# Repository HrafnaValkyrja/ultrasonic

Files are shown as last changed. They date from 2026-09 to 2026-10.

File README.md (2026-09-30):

# Stereo Ultrasound

A glasses-mounted wearable that shifts ultrasound (≈20–85 kHz) down into the audible range and plays it by bone conduction, in stereo, in real time.

- **Spec (source of truth):** [`docs/spec.md`](docs/spec.md). §1 is the owner-locked MVP.
- **Latest plan review:** [`docs/research/review-2026-09-30.md`](docs/research/review-2026-09-30.md)
- **Research findings:** [`docs/research/`](docs/research/), one file per task ID from spec §12.
- **Models and checks:** [`sim/checks/`](sim/checks/): PWM noise, noise-shaper comparison, dead-time distortion, weight balance. Run with `python3 <script>` (numpy, scipy).
- **Data:** [`sim/data/`](sim/data/): the mic's ultrasonic response, digitized from its datasheet.

Status: concept phase. Phase 1 (DSP simulation in Python) is next, pending owner decisions O1–O3 in spec §12.

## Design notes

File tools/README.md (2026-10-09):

# Engineering harness

Tools that let Claude simulate circuits, design and check boards, model mechanics, render
diagrams and cross-compile firmware in the cloud container. One idempotent installer,
one environment file, smoke tests with real answers.

```bash
tools/setup.sh               # install anything missing, verify (a fast no-op once installed)
tools/setup.sh --smoke       # ...then run the smoke tests
tools/setup.sh --check       # verify only
source tools/env.sh          # PATH, venv, KiCad library paths, FreeRouting, mermaid-cli
python3 tools/smoke/run_all.py [--offline] [-k NAME] [--keep DIR]
```
A SessionStart hook runs `tools/setup.sh --quiet` in Claude Code on the web, so a fresh
container installs everything automatically.

## What's installed (2026-09-30)
| Tool | Version | Used for | Skill |
|---|---|---|---|
| ngspice | 42 | Circuit simulation: H-bridge dead time, gate drive, LDO, battery | spice-sim |
| KiCad (`kicad-cli`, `pcbnew` Python) | 10.0.6 (official PPA, key pinned in `keys/`) | ERC/DRC, Gerber/drill/placement export, 3D renders, board scripting | pcb-kicad |
| SKiDL | 2.3.0 | Schematics as code, generating the KiCad netlist | pcb-kicad |
| FreeRouting | 2.4.1 (SHA-256 pinned; OpenJDK 25) | Headless autorouting via Specctra DSN/SES | pcb-kicad |
| easyeda2kicad | 1.0.1 | KiCad symbol, footprint and 3D model by LCSC number | jlc-parts |
| `tools/jlc.py` | — | JLC stock, price, Basic/Extended, with a query timestamp | jlc-parts |
| ARM GCC + newlib | 13.2.1 | Cortex-M4F cross-compiling (hard-float) | — |
| build123d | 0.13.0 | Parametric CAD, mass properties, STL/STEP | cad-mech |
| scikit-fem | 12.0.2 | Finite elements (spring arm force, stiffness) | cad-mech |
| sounddevice + libportaudio2 | 0.5.6 / 19.7 | Live audio I/O for `bench/rig/` scripts (licences: python-sounddevice MIT, PortAudio MIT-style) | bench |
| numpy / scipy / matplotlib | 2.5.3 / 1.18.1 / 3.11.2 | DSP models, plots (`tools/plotstyle.py`) | — |
| mermaid-cli | 11.17.0 (uses the preinstalled Chromium) | Flowcharts and mind maps to PNG | visual-explainer |
| headless Chromium | preinstalled (`/opt/pw-browsers`) | SVG diagrams to PNG (`docs/diagrams/render.sh`) | visual-explainer |

Python packages live in a Python 3.12 venv (`$ULTRA_VENV`, with system site packages so
`import pcbnew` works), pinned by `requirements.txt` and `constraints.txt`. Install location
is `/opt/ultrasonic-tools` (`$ULTRA_TOOLS_HOME`).

**Cost:** about 3.4 GB of disk (1.7 GB of apt packages, 1.7 GB of venv and tools). A run with
partly cached apt packages took 107 s. A fully cold install hasn't been timed; expect a few
minutes. The KiCad 3D-model library is optional: `--with-3d` adds 3.2 GB.

## Smoke tests (all passing, 2026-09-30)
| Test | Checks |
|---|---|
| ngspice | RC step response: time constant 1.000 ms (expected 1.000) |
| kicad+freerouting | Build a 2-net board → autoroute → import → DRC 0 errors, 0 unconnected → 25 Gerber files → 3D render |
| skidl | Netlist with parts, nets and footprints |
| arm-gcc | Cortex-M4F object uses the FPU |
| build123d | Exact volume and centroid of a part with a window; STL + STEP |
| scikit-fem | Cantilever tip deflection matches beam theory to 0.1% |
| sounddevice + libportaudio2 | 0.5.6 / 19.7 | Live audio I/O for `bench/rig/` scripts (licences: python-sounddevice MIT, PortAudio MIT-style) | bench |
| render | SVG and Mermaid diagrams to PNG |
| easyeda2kicad | Fetches the SPH0641LU4H-1 footprint and symbol (C2879853) — network |
| jlc-api | Live JLC lookup — network |

## Fixed while testing
`tools/spice.py` returned no `.meas` results: ngspice 42 refuses `.meas` in batch mode
when writing a rawfile. Netlists with `.meas` now get a second batch pass without `-r`.

## What this can't do
- **Cycle-accurate Cortex-M4 timing.** There's no free simulator for it; measure on the Nucleo
  with the DWT cycle counter (spec S3).
- **Bone conduction, skin coupling and perception.** These are bench and ear questions (spec §10).
- **The mic's acoustic port above ~20 kHz.** Lumped models are approximate; the S1 acoustic
  coupons decide.
- **EMI and full-wave electromagnetics.** Not installed (openEMS could be added if needed).
- **Accuracy of vendor models.** A simulation is only as good as its models; every result
  names the models it used.

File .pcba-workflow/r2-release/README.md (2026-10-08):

# r2 (phase-2 'mz2') release package - 2026-10-08 - gate BLOCKED (see gate.yaml)
Mirrors .pcba-workflow/k4-release. Files: `r2_gerber_drill.zip` (Protel-ext Gerbers F/In1/In2/B Cu, masks, paste, silk, Edge.Cuts; Excellon PTH+NPTH; maps; job), `bom.csv`, `cpl.csv` (JLC rotations via tools/jlc_rotations.py; bottom rule jlc2022), `jlc_rotation_corrections.csv`, `pin1_expected.png`, `pin1_check.csv`, `sourcing_dated.csv` (live JLC API), `cost_inputs.json`, `src/bom_jlc_mz2.csv`.
Rebuild: `python3 .pcba-workflow/k4-release/build_release.py r2` (default arg = K4). Gerbers: `kicad-cli pcb export gerbers --board-plot-params --no-x2` + `export drill --excellon-separate-th --generate-map --map-format gerberx2` on the board, zipped.
Quantity assumed 5 boards (JLC min). Nothing ordered.

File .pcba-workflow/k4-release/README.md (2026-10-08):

# K4 release package (P + M boards) - 2026-10-08 - gate BLOCKED (see gate.yaml); rebuilt on 311b11d (board hashes in gate.yaml)

Files (per board X in P, M): `k4_X_gerber_drill.zip` (Protel-ext Gerbers F/In1-4/B Cu, masks, paste, silk, Edge.Cuts; Excellon PTH+NPTH; drill maps; job file),
`bom_X.csv` (JLC columns Comment/Designator/Footprint/LCSC Part #), `cpl_X.csv` (Designator, Mid X, Mid Y, Layer, Rotation; absolute KiCad coordinates, y up, mm),
`pin1_check.csv`, `sourcing_dated.csv` (live JLC API per line), `build_release.py`, `src/` (BOMs matching the boards).

Board: 15.5 x 12.0 mm (bbox 15.55 x 12.05 with edge line), 6 copper layers, 0.8 mm, ENIG (BM28 0.35 mm pitch, QFN/DSBGA need flat pads), min track/space 0.09/0.088 mm (persisted JLC fine rules in .kicad_pro), parts both sides (top, from cpl_X.csv. P top: C2 C9 C11 C22 J21 Q1 R2 R3 R4 R6 R21 R22 R23; P bottom: the rest incl. U1 QFN48, Y1, L1, Q2. M top: C16 C17 C19 D4 D5 J20 R8 R9 R12 R13 R14 U2 U3 U4; M bottom: the rest incl. SW1, U6, RT1).

## Quantities (owner rule: 2 worn + 3 spares, O19)
JLC PCBA minimum is 5. Order 5 P + 5 M assembled; every BOM line = qty/board x 5. Spares are whole boards, so a P/M pair is always available.
MCU C5271013 stock was 19 on 2026-10-08 (08:40Z) (5 needed): reserve early.

## Stack-up / impedance
No `(stackup)` block in the board files; JLC publishes 6L builds for 1.2/1.6/2.0 mm only, NOT 0.8 mm (read 2026-10-08, K4-STACK6). Order 6L 0.8 mm with JLC's default build, **no impedance control**: nothing here claims a controlled net (USB D+/D- are full speed, ~15 mm). Planes: In1 GND, In2/In3/In4 per router assignment; sim/noise assumed uniform dielectrics (0.2 dB spread to thin-outer). Copper outer 1 oz-class (35 um nominal on JLC 6L), inner 0.5 oz (15 um).

## Vias / via-in-pad
All vias 0.15 mm drill / 0.25 mm pad, through (F-B) only: P 107, M 70 (pcbnew count). That is JLC's minimum (0.15/0.25) and carries a small-via surcharge. **Via-in-pad: 67 vias land on SMD pads on P (U1 QFN48 exposed pad, R3, R5); none on M.** Order flag: **"Via-in-pad / plugged: Epoxy/copper filled and capped (POFV)"**, which JLC covers for 0.15-0.55 mm vias (capabilities page Sep 2026). Ink-plugged is NOT allowed in pads. Without POFV, solder wicks into the QFN EP vias. Drill histogram: P PTH 0.15 x107; M PTH 0.15 x70, NPTH 0.65 x1 (mic port).

## CPL rotation corrections (tools/jlc_rotations.py, 2026-10-08; replaces the raw-KiCad CPL)
`cpl_X.csv` now carries JLC rotations: top = KiCad rot + corr; bottom = (180 - (rot - corr)) mod 360 (JLCKicadTools rule, comment dated 2022-07; JLC changed it before, so the preview still decides; `--bottom-rule asis` = old raw behaviour). corr comes from (1) pin-1 geometry of our footprint vs the EasyEDA footprint of the LCSC part (easyeda2kicad, cached `tools/data/jlc_rot/ee/`), (2) the community DB `tools/data/jlc_rot/cpl_rotations_db.csv` (matthewlai/JLCKicadTools, GPL-3.0, last commit 2024-09-11, fetched 2026-10-08; same file kicad-jlcpcb-tools downloads) which wins when a rule matches. Table: `jlc_rotation_corrections.csv` (board, ref, footprint, LCSC, kicad rot, jlc rot, corr, offset, source, confidence, check flag, notes). Regenerate: `python3 tools/jlc_rotations.py --release` (build_release.py calls it).
Result: only U1 (corr 270) differs among ICs; bottom-side rule changes C13, R10 etc. (180 -> 0, harmless for passives). 43 of 55 parts are symmetric passives (high); **12 parts are NOT confirmable from data and go on the preview checklist, `pin1_expected.png` shows the expected pad-1 corner for each**: J21, J20 (BM28), Q1, Q2 (SOT1216, no EasyEDA footprint exists for C19654206, so no data check at all), U1 (QFN48, pad sets differ 0.23 mm from EasyEDA), U2 (LGA mic), U3 (DSBGA), U4 (X2SON), U6 (SOT-553), D4, SW1. (D5 X1SON is symmetric-ish, checked in the same pass.) JLC's private per-part rotation offsets are not published; that residual is what the preview is for.
Do not accept the preview with any part highlighted red; stop and re-export. Any part rotated wrong in preview: add its correction to a local override and rerun.

## Panel / rails (15.5 x 12 boards)
JLC assembly needs rails + tooling; boards this small cannot run alone. Options:
A. **(recommended) 1 P + 1 M per panel, 5 panels** = exactly 5 + 5 boards (2 worn + 3 spares); Different Design = 2, panel by customer. Side by side with 2 mm gap and mouse bites: 33 x 12; 5 mm rails on the long sides: 33 x 22; 2 mm tooling holes + 1 mm fiducials in the rails. If JLC enforces the 70 x 70 minimum seen in assembly.md, widen the rails (free FR4, same price).
B. 5 P + 5 M in one 2-row panel: fewer panels, but a single bad row blocks both; JLC min PCB qty may force 5 such panels.
C. Order loose and "Panel by JLCPCB" V-cut: not recommended (mouse-bite/V-cut leaves 0.4 mm tolerance against 0.35 mm-pitch connector edge placement and offers no fiducials).
No panel file made (needs the final board hashes).

## Cost estimate, 5 + 5 assembled (2026-10-08, JLC parts API 11:53Z; fees from JLC page read 2026-10-02: assembly.md)
| Line | USD | Basis |
|---|---|---|
| Parts (40 lines, 35 distinct LCSC, 5x each) | 78.40 | live API price at qty, `sourcing_dated.csv`; MCU alone 5 x 9.02 = 45.1 |
| Feeder loading $1.53 per part type | 54 (61 if per board line) | 35 distinct (29 Extended) |
| Setup + stencil, double-sided | 68 to 135 | $51.12 + $16.42 once for one combined order; double if P and M ordered separately |
| X-ray (QFN48, DSBGA, LGA, X2SON, DFN, X1SON) | 25 to 70 | scaled from $10-28 per 4 boards; unquoted |
| PCB 6L 0.8 ENIG, 0.15 vias, POFV, 5 panels | 60 to 160 | UNQUOTED: JLC headline "6L 5 pcs from $2" excludes ENIG, POFV, small-via fee |
| Shipping, tax | not included | |
| **Total** | **about 287 to 503** | mid ~395; over the ~$300 budget line (O13) unless the low end holds |
Live quote is required before relying on any of this. Hand-off to the upload checklist: `operate-jlcpcb-order` (not started).

## ECR-0023 filler
Bonded-post filler: low-shrink epoxy, <= 0.5 % shrink (shell assembly, not a PCB line item).

**K4-STACK6 (2026-10-08):** stack-up we order = JLC 6L 0.8 mm default build, symmetric split assumed (sources: jlcpcb.com/resources/6-layer-pcbs, jlcpcb.com/impedance, read 2026-10-08). sim/noise/k4_noise.py re-run with both bounding splits: worst-PSRR corner 26.4 dB (uniform) / 26.2 dB (thin_outer), spread 0.2 dB, sign-off >= 10 PASS.

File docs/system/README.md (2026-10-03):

# The big picture: living system documents

The pod is one system. A change in one place (a part swap, a moved component, a lid feature, a firmware
pin) can break something three domains away. These documents keep the whole picture in one place, so
every change is checked against it **before** it is made. Owner rule, 2026-10-01: Claude and every
agent use this set for every design change.

## The rule

1. **Before** any design change (schematic, layout, mechanics, firmware architecture, part choice):
   read `00-whole.md`, `integration-map.md`, and the doc of every subsystem and region the change touches.
   Walk the change through the cross-check in `integration-map.md` §10 (functions, nets, pins, rails,
   off-board, mechanical, firmware, cross-domain dependencies). Run `python3 tools/plm.py impact <file|ref:X|net:X|item>`
   to list every interface and doc the change touches. A change bigger than a typo gets an ECR
   (`plm.py ecr new`); the owner approves ECRs that touch her decisions.
2. **After** the change, in the same commit: update every doc it touched, in the AI-facing format (owner
   rule 2026-10-01: the docs are written for other Claude instances with a compacted context, not for humans):
   - **content:** current state only (history = git, no change-log section; one `Rev <letter> <date>:` line at
     the top says what the latest revision changed); the YAML status header, interfaces, key numbers and open
     issues all updated;
   - **form:** YAML blocks and terse key:value lines; stable IDs (D#, O#, R#, F#, ECR-####, relation ids, check
     ids; a closed issue leaves a gap in its ID sequence, never a renumbering); a source (file:symbol | spec § |
     commit) and a date on every number; pointers instead of copies; invariants as executable checks
     (`tools/checks/*`) that the doc lists by id; at most one `why:` line, only when non-obvious; every
     abbreviation defined once at the top.

   Regenerate the integration map when the schematic changes:
   `source tools/env.sh && python3 hw/pod/system_map.py`. Then `plm.py status`: every SUSPECT relation and
   STALE item it reports must be checked and re-baselined (`plm.py review <id> --by ... --note ...`) before
   the work counts as done.
3. **Agents** get this set as mandatory context and must return the cross-check with every proposal.
   A team (agent or person) that edits an item checks it out first (`plm.py checkout <item> --by <team>`);
   a CONFLICT FLAG means a related item is held by another team: coordinate before editing.
4. **Authority:** `docs/spec.md` wins. These docs summarise and link; they never override the spec or the
   source-of-truth files (`hw/pod/gen.py`, the KiCad board, `hw/mech/*.py`). If a doc disagrees with a
   source file, the doc is wrong: fix it. If the spec looks wrong, raise it with the owner.
5. **Staleness is a bug.** A doc whose status line is older than the last change to its source files is
   out of date. Fix it before relying on it.

## Index

| Doc | Kind | Covers |
|---|---|---|
| [00-whole.md](00-whole.md) | whole | The product on one page: functions, block and physical diagrams, key numbers, status of every part of the system, decision index |
| [integration-map.md](integration-map.md) | integration (generated) | Every block, inter-block net, MCU pin, rail load, off-board wire, mechanical keep-out, firmware dependency; the cross-check protocol |
| [physical.md](physical.md) | physical integration | Coordinate frame, stack-up through the pod, clearances, sealing paths, assembly order (test build vs final bonded build) |
| [sub-power.md](sub-power.md) | subsystem | Cell, charger, power path, LDO, rails, temperature-safe charging, battery sensing, power budget |
| [sub-audio-in.md](sub-audio-in.md) | subsystem | Ultrasonic mic, acoustic port path, PDM/ADF1 capture |
| [sub-processing.md](sub-processing.md) | subsystem | MCU, core SMPS, clocks, memory, firmware architecture and algorithms, low-power modes |
| [sub-output.md](sub-output.md) | subsystem | H-bridge, PWM, exciter, arm wiring to it, self-test current sense |
| [sub-dock-usb.md](sub-dock-usb.md) | subsystem | Magnetic dock, USB FS, DFU, ESD, dock detect |
| [sub-ui.md](sub-ui.md) | subsystem | Button (switch, plunger, skin), power LED |
| [sub-debug-test.md](sub-debug-test.md) | subsystem | SWD, test pads, test hooks, snap-off test frame, self-test over USB, bring-up plan |
| [reg-pod-body.md](reg-pod-body.md) | region | Housing (tub, lid, spine top), board retention, dock bay, sealing, adapter to the temple |
| [reg-board.md](reg-board.md) | region | The PCB: outline, faces, floorplan regions, layer stack, keep-outs, height bands, routing state |
| [reg-arm.md](reg-arm.md) | region | NiTi arm, heel, strut cover, joint, wire path through it |
| [reg-pad.md](reg-pad.md) | region | Transducer cup, contact face, pad board and LED |

## Relation tracking (`tools/plm.py`, PLM-style)

Items (these docs), relations (the interfaces between them, each watching the exact things that carry the
interface: nets, parts, placement entries, CAD symbols, spec lines), baselines, check-outs and ECRs live in
`docs/system/plm/`. A relation turns **SUSPECT** when anything it watches changes after its last review; an
item turns **STALE** when its sources change after its doc was last reviewed; a watch that no longer resolves
is **BROKEN** (re-model the relation). `plm.py graph` draws the whole web (`docs/diagrams/plm-relations.png`).
Idea sources: Teamcenter-style where-used / change management; Doorstop's suspect-link stamps.

## Template (every subsystem and region doc)

Format of the six Rev F docs (`sub-power`, `sub-processing`, `sub-output`, `sub-dock-usb`, `sub-debug-test`,
`reg-board`); rule 2 above defines the style.

````
# <NAME>: <scope> (item <ITEM-ID>)
Rev <letter> <date>: <one line: what this revision changed; current state only, history = git>
Status: <schematic / board / firmware state, each with source + date>. Updated <date>.

```yaml
abbrev: {TERM: meaning}          # every abbreviation, defined once, before use
item: <ITEM-ID>                  # docs/system/plm/items.yaml
src_of_truth: ["<file[:symbol or Lnn]>", "<...>"]
owner_decisions: ["O#", "<...>"]
open_ecrs: {ECR-####: <state>}
checks: ["tools/checks/<x>.py [<check id>] (<date>: <result>)"]
diagrams: ["docs/diagrams/<name>.png"]
```

## Purpose            YAML: functions (F-rows in integration-map.md §1), requirements, each with its D-/O-id
## Big picture        a diagram (PNG in docs/diagrams, dark mode, or mermaid) + at most ~10 key:value lines
## Elements           YAML list: ref, part (glossed: part number = what it is), lcsc · class · stock · price (query date), position (src)
## Interfaces         YAML list, one entry per neighbour: to, nets/pins (names exactly as in integration-map.md),
                      crosses, invariants, src, rel (plm relation id)
## Constraints        YAML: D-items, O-items, physics/process limits, each with src
## Key numbers        YAML list: {q: quantity, v: value, src: source + date}; derived values say "derived"
## Open issues        YAML list with stable IDs (<PREFIX>-<n>, gaps = closed): id, t (what), close (what would
                      close it), owner (who decides)
## Before you change this, check   YAML: invariant -> other docs/checks it can break; always: plm.py impact + integration-map §10
````

## Change log
- 2026-10-01: set created (owner rule). `integration-map.md` generated from gen.py Rev E.
- 2026-10-01: doc set completed (00-whole, physical, 7 subsystem and 4 region docs, diagrams `system-overview-physical` and `board-regions`), then inspected and corrected in one editor pass: interfaces name the doc on the other side, 00-whole gains the status table, "Design-level cross-domain risks" and "Fixes waiting in source files"; ECR-0008/0009 and two relations in `items.yaml` amended.

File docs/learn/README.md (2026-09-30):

# Learning the device

**Level-set (owner, 2026-09-30):** RF, analogue, digital packets/data, CAD and device physics are all known ground. The gaps are the black boxes: what's inside a modern MCU, how to read one, and why a 4-layer board. Lessons are pitched there.

- `02-inside-the-chip.png`: the STM32U575 as a small network (bus masters, DMA, memory-mapped peripherals, clock tree), with one audio sample's path
- `03-four-layer-board.png`: the pod board's stack-up, vias, return paths, and why 4 layers

## Original plan (lesson 1 pitched too low; kept for reference)

Each lesson has one picture and one idea. Every later lesson builds on lesson 1.

1. **The big picture:** the journey of one bat chirp; the "two pianos" idea (`01-big-picture.png`)
2. **Hearing ultrasound:** how a 3.5 mm mic hears 40 kHz, and why it speaks in 1-bit pulses
3. **Counting:** turning pulses into numbers; why 200,000 numbers a second is enough for 85 kHz
4. **Sorting and re-singing:** splitting sound into 28 "keys" (the FFT), the log squeeze, and why whines vanish
5. **Switching:** making sound from on/off pulses (PWM), the H-bridge, and dead time
6. **Bone conduction:** why the tragus, and how vibration reaches the cochlea
7. **Power:** battery, regulators, and why current decides runtime; the idle mode
8. **The board:** every part on the render, matched to the blocks above
9. **Mechanics:** the pod, the NiTi arm, and balance on your nose and ears

Each lesson ends with a hands-on "try it" for when the parts arrive.

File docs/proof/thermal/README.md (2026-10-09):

# P-THERM: is the K4 pod thermally possible? (2026-10-08)
Method: lumped transient network (`thermal.py`, numbers reproducible, 3G fence): U3 die - board - shell - 35 °C ambient, cell coupled to board (1.4 mm air gap, 113 K/W) and shell (13.9 K/W). Envelope from `hw/mech/dims_k4.py` (A_out 23.5 cm²). No 2-D FEM: the unknowns are the film coefficient and gaps, not conduction detail. Plot: `thermal.png` (dark).

## Heat sources (130 mA charge, 5 V dock, D4 drop 0.30 V -> VIN 4.7 V)
| part | dissipation | basis |
|---|---|---|
| U3 BQ25180 (TI 1-cell linear charger) | 0.19 W at VBAT 3.3 V, 0.12 W at 3.8 V, 0.07 W at 4.2 V | (VIN-VBAT) x (130+5 mA), TI SLUSE99C §8.3.7.7 formula |
| D4 PMEG3005EL (Nexperia 30 V Schottky) | 0.04 W | 0.30 V x 0.135 A |
| cell + PCM (protection circuit) | 5 mW | I²R, 0.3 Ω ASSUMED (no datasheet ESR in repo) |
| awake, worst (MCU 5.8 + audio 2.15 + bridge ctrl 1.06 + transducer avg 2.5 = 11.5 mA, VSYS 4.2 V) | 48 mW (LDO U4 14 mW) | `docs/system/rail-budget.yaml` |

## Results
| # | check | result | verdict |
|---|---|---|---|
| 1 | U3 junction, charging, 35 °C docked | 52 °C (board 47 + P x RθJB 30.3); bounds with θJA 65/107 °C/W on 0.2 W: 48-56 °C. Limit: THERM_REG 100 °C | PASS (48 K margin) |
| 2 | D4 junction | ~71 °C (existing figure, 500 K/W) | PASS |
| 3 | Cell temp, charging, **docked, still air** (h 10 W/m²K) | peak 43.5 °C at 21 min, limit 45 °C (0-45 °C charge, `sub-power.md` L134) | PASS, margin only 1.5 K |
| 4 | Cell temp, charging, **worn / covered** (h 5, bound) | peak 49.4 °C | FAIL as a bound; mitigated by U3 JEITA (TS 45 °C stop) via RT1 (reads board, hotter than the cell, so conservative) -> charge pauses, never overheats the cell. Charging worn is not a stated use |
| 5 | Skin touch, charging docked | shell 42.9 °C vs 43 °C | PASS, zero margin |
| 6 | Skin touch, charging worn bound | shell 48.9 °C | FAIL vs 43 °C; do not charge on the head |
| 7 | Awake runtime, worst | 48 mW: shell +2.1 K (docked-like) to +4.1 K (bound) -> ~39 °C at 35 °C ambient; U4 +2.3 K | PASS |
| 8 | LDO U4 under transducer drive, fw clamp 208 mA (FWSIM-R64), VSYS 4.2-4.5 V docked (drop 1.2-1.5 V) | Playback is real-time audio, not scheduled bursts (spec §5: heterodyne/compression; bat calls last ms, spec L291). Duty is signal-driven, so bounded three ways. (a) Continuous full-clamp sine (impossible bound): mean |i| = 0.637 x 208 = 132 mA -> 0.16 W (4.2 V) to 0.20 W (4.5 V) -> +26 to +33 K at θJA 166 °C/W (steady). (b) Budgeted worst average, rail-budget exciter 2.5 mA: 3.8 mW at 4.5 V -> +0.6 K (equals 1.9 % of (a)). (b2) D17 option A + 12 dB drive into the limiter, real programme (docs/proof/electrical/d17-cost.md, 2026-10-08): mean 14.5 mA (dense) to 24.9 mA (calls continuous) -> 17-37 mW -> +2.9 to +6.2 K (TEAX 7.8 ohm: +3.0 to +6.3 K); option A alone +1.0 to +2.2 K; U4 junction ~45 °C worst, PASS. (c) One call, 10 ms at the clamp (0.2 W mean): ΔT = P θ (1-e^(-t/τ)); no Zth curve exists in TPS7A20 datasheet SBVS338H (rev. Jul 2024, fetched 2026-10-08; only θJA 166.1, RθJC(top) 103.6, ψJT 3.0, ψJB 103.3 °C/W for DQN), so NO thermal-capacity credit is taken: the pulse is charged at steady θJA, +33 K (supersedes the assumed τ 0.1-1 s, +0.3 to +3 K). Even a 200 calls/s buzz at 10 ms is case (a). U4 junction then ~35 + 3 (shell) + 33 = 71 °C worst, far under its 125 °C | PASS (realistic +0.6 K; bound +33 K); datasheet θJA/ψJT confirmed; Zth not published (bound used); shell/ambient terms still ASSUMED, bench log of U4 (PWR-I12) closes them |

**Row 8 re-run 2026-10-08 (SIM-FID-U4; datasheet SBVS338H, θJA 166.1, ψJT 3.0 so case top is within 0.2 K of the die).** Heat into the shell = all extra battery power (4.2 V x extra mA; acoustic output negligible) at row 7's 44 K/W (docked-like) to 85 K/W (bound); U4 = (VSYS-3.0) 1.2-1.5 V x I x 166. Ambient 35 °C.

| Case (exciter mean mA; source) | Pod P | Shell | U4 junction | Touch margin vs 48 °C (TS1) |
|---|---|---|---|---|
| Today, rail budget 2.5 | 48 mW | 37.1-39.1 | ~39-41 | 8.9-10.9 K |
| A+loud12, real use bats (8.9 awake hops; current-models-reconciled.md) | ~75 mW | 38.3-41.4 | 41.9-45.0 | 6.6-9.7 K |
| A+loud12 dense programme (14.5; d17-cost.md) | ~98 mW | 39.3-43.3 | ~44-49 | 4.7-8.7 K |
| A+loud12 nonstop loud, calls continuous (24.9) | ~142 mW | 41.2-47.1 | 48-55.5 | **0.9-6.8 K** |

All junctions far under 125 °C (even +33 K pulse on top: <90 °C). Shell touch is the limiter: nonstop loud playback in the bound (worn, no airflow) case is 0.9 K from TS1 48 °C, thin but passing; docked-like 6.8 K. Note row 5/6 charging limits (43 °C skin) are separate and do not combine with playback (docked, not worn). Still ASSUMED: ambient 35 °C, R_shell 44-85 K/W (row 7), VSYS 4.2-4.5 V, mean mA from sim not firmware.
| 9 | Cell ESR, h, R_BS | assumed, not measured | OPEN: log board+cell temperature through a full charge (PWR-I12 / ECR-0009 item 3) |

## Limits (sources; touch text re-fetched 2026-10-08)
- Cell charge 0-45 °C: Renata ICP401230 V02 08/2019 (as in `sub-power.md`).
- Touch: IEC 62368-1 (TS1 table, Table 42 in ed. 2.0 2010; Table 38 in later editions): TS1 max 48 °C, metal and plastic, contact > 1 min; 51 °C metal / 60 °C plastic for 10-60 s; TS2 = TS1 + 10 K. Source: UL Japan tech brief 'Touch Temperature' (Copyright 2010 UL), https://japan.ul.com/wp-content/uploads/sites/27/2014/06/1_techbrief_touchtemp.pdf, fetched 2026-10-08 (secondary source; the standard text itself is paywalled). The earlier '~43 °C' is NOT the 62368-1 number: it is the IEC 60601-1 applied-part limit (recall, still unconfirmed). Project line stays 43 °C (conservative, worn on skin ~33-35 °C): rows 5/6 verdicts unchanged; against 62368-1 TS1 48 °C, row 5 has 5 K margin and row 6 (48.9 °C) is a marginal FAIL.
- U3 numbers: TI BQ25180 SLUSE99C §7.3, §8.3.7.7 (via `docs/system/audit-datasheet-claims.md` row 7, 2026-10-02).

## Verdict
Possible with thin margin: docked charge keeps the cell under 45 °C by 1.5 K and the shell at the 43 °C line. The one real lever is current: capping charge at 65 mA (0.5C, already an open owner question A-SAFETY-REVIEW) halves U3 heat and gives ~20 K margin. Recommend: ship firmware default 0.5C, 130 mA only below ~30 °C ambient (RT1 reads).

**Lead note 2026-10-08:** the owner ruled 130 mA (1C) in O34, so 1C stays the default. The hot case is already covered in hardware: U3 TS_HOT is set to 45 °C (sub-power.md register plan), so above that charging pauses and resumes once the cell cools; it never overheats. A 0.5C fallback above ~30 °C ambient (RT1) is a firmware option to raise only if the bench first charge (G5, thermocouple) shows pauses. Row 8 (LDO duty) and the touch-limit re-fetch closed 2026-10-08 (see table and limits).

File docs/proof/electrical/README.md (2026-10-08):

# K4 electrical proof (P + M boards), 2026-10-08

Question: are `hw/pod/k4/routed_{P,M}.kicad_pcb` (generator `hw/pod/k4/gen.py`, BOMs `bom_jlc_{P,M}.csv`) electrically possible?
Answer: **boards are connected and rule-clean; the +3V0 peak is not.** Two FAILs, one root cause: the bridge full-drive peak (326 mA) exceeds the K4 cell's pulse rating (260 mA) and the U4 LDO's 300 mA rating. Fix candidate already in the repo: 12 ohm exciter (about 226 mA), ECR-0005 (proposed).

**Lead check 2026-10-08:** both FAILs are full-drive hardware peaks with no firmware limit. The firmware already clamps the bridge (FWSIM-R64, fw/variants.yaml `bridge`, tested by fw/test/test_clamp.c and prop_ceiling.c): i_peak_max = min(0.8 x cell pulse, 0.9 x U4) = min(208, 270) = **208 mA** for the K1_130 cell. With the clamp, rows 2 and 4 **PASS** (cell 80 %, U4 69 %). The cost is loudness: the clamp holds the drive at about 208/315 of full scale (about -3.6 dB of peak level). A 12 ohm exciter (ECR-0005, closes on bench E1) would raise the unclamped headroom. Open: confirm the clamp holds on the bench (G-stage current probe).

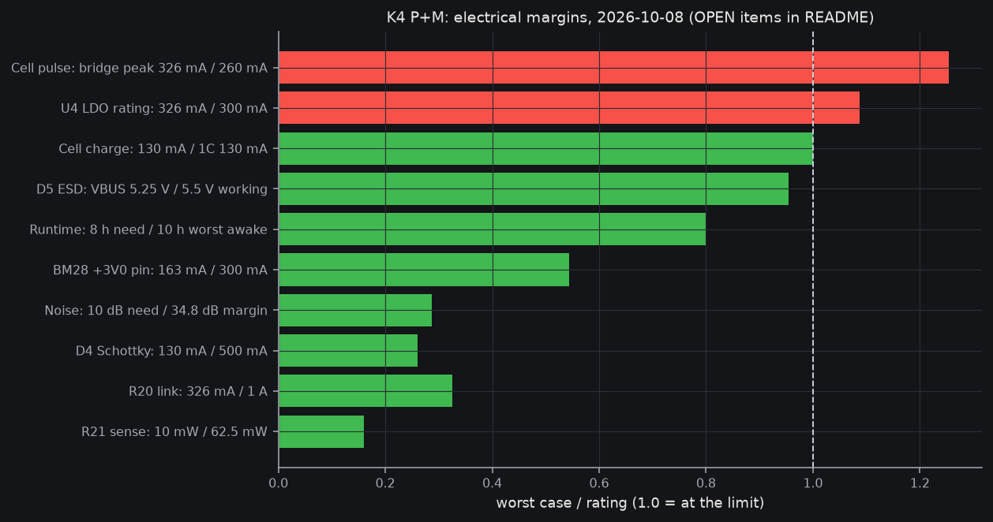
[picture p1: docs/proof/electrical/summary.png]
summary


Status: PASS = met with margin from a source; FAIL = exceeded; OPEN = no K4 evidence yet. Source paths are repo-relative.

| # | Check | Worst case vs limit | Status | Source | Date |
|---|---|---|---|---|---|
| 1 | Runtime vs cell (ICP401230UPR, Renata 130 mAh Li-polymer) | avg 5.0-9.8 mA awake; 130 mAh gives about 10-16 h with LED vs 8 h spec (scaled from the 175 mAh model, not re-simulated) | PASS | docs/system/sub-power.md l.171-181; docs/research/k1t-vs-k4-parity.md | 2026-10-08 |
| 2 | Cell pulse | bridge peak 326 mA vs 260 mA (2C "non-continuous", duration unstated) = 125 % unclamped; 208 mA with the FWSIM-R64 clamp = 80 % | **PASS (fw clamp)** | fw/variants.yaml K1_130; docs/research/drastic/V2-cells.yaml l.82; tools/checks/interfaces.py (run today, r2 loads: +3V0 peak 326 mA) | 2026-10-08 |
| 3 | Cell charge | 130 mA at ICHG code 40 vs 1C = 130 mA (0 % margin; owner question on a 65 mA cap open) | PASS (at limit) | docs/system/sub-power.md l.146 | 2026-10-08 |
| 4 | +3V0 rail load (U4 TPS7A2030, TI 300 mA 3.0 V ultra-low-noise LDO) | 326 mA unclamped vs 300 mA rated; 208 mA + ~11 mA other loads with the clamp = 73 % | **PASS (fw clamp)** | docs/system/rail-budget.yaml; interfaces.py rails WARN; sub-power.md PWR-I1 | 2026-10-08 |
| 5 | +3V0 dropout | holds at 315 mA while VBAT >= 3.32 V (dropout 140 mV at 300 mA + path drop). Below that the bridge sags (function, not safety). Cell sag at 260 mA <= 88 mV (max R) | PASS (derived), OPEN at low SOC | sub-power.md l.158; V2-cells.yaml l.108 | 2026-10-07 |
| 6 | +3V0 and VSYS ripple (K4 nets) | Bound = |Z|(f) x bridge peak 208 mA (clamped), ngspice AC of K4 caps (C4/C7 10u, C14 22u on +3V0; C21 10u on VSYS; cell 0.34 ohm Rint, R21 0.1 ohm). +3V0: 17-39 mV pk at 40 kHz (kd 1..0.5 cap derating, LDO Zout 0.2..2 ohm), 4-8 mV at 200 kHz, 1 mV at 2 MHz. VSYS: 53-65 mV pk at 40 kHz, 16-29 mV at 200 kHz, 3-4 mV at 2 MHz. Mic-rail effect stays the 8.72 uV rms LN-M05 / 34.8 dB (row 8) because R30/C filter and mic PSRR sit after. U4 Zout curve is not in SBVS338H (assumed R\|\|1 uH), kd is an estimate until A-CAP-CURVES; bound is a peak-current sine, not a loop sim | PASS (bound), OPEN (U4 Zout bench, G-stage scope) | sim/proof/k4_rail_ripple.cir (ngspice 45, run 2026-10-08); sim/noise/params.yaml esr; V2-cells.yaml | 2026-10-08 |
| 7 | VDD11 (MCU core SMPS, D11 the one allowed switcher) | L1 DFE201610E-2R2M (Murata 2.2 uH): Isat 2.4 A (Murata), ST needs > 0.5 A; core load not budgeted in rail-budget.yaml | PASS (rating), OPEN (load figure) | docs/system/sub-processing.md l.36; rail-budget.yaml VDD11 | 2026-10-08 |
| 8 | Mic supply noise: F02 SMPS to MIC_VDD vs 10 dB sign-off | worst-PSRR corner margin 34.8 dB abs-bound on the re-routed boards (26.4 dB / 26.2 dB for the default / thin_outer stack in ECR-0020 rev 5 text; both >= 10) | PASS | sim/noise/out_k4/k4_noise.json; `k4_noise.py --gap 0.6` re-run today, output byte-identical (cmp) to the 07:39 file; ECR-0020 l.28, l.124 | 2026-10-08 |
| 9 | Mic data/clock crosstalk vs 100 mV | MIC_DATA 62.6 dB, MIC_CLK 64.1 dB abs-bound margin (bridge: 82/88 dB) | PASS | k4_noise.json (with_L1_body) | 2026-10-08 |
| 10 | BM28 (Hirose 0.35 mm B2B, 30 pins) current | +3V0 on pins 15/30 plus 4 power tabs: 326 mA over 2 pins = 163 mA/pin vs 0.3 A per contact [tentative, secondary source] = 54 %. Mic VDD 1.35 mA | PASS | docs/system/integration-map.md l.218; pin-contract.yaml k4_split | 2026-10-08 |
| 11 | BM28 SI on MIC_CLK / data | Simulated (ngspice, 6-section LC lines, Z0 70 ohm assumed from 0.09 mm trace on ~0.1 mm prepreg, IPC-2141 microstrip; 6.9 ps/mm; BM28 1 nH + 0.3 pF): MIC_CLK 1.8 V, 2 ns edge, 33 ohm R2, 12.5 + 7.1 mm: overshoot 1.88 V (+4 %), settles clean. Neighbour I2C_SCL (4.7k pull-up, 3.0 V, GND pin between; Cm 0.2 pF, k 0.2 assumed worst): +/-68 mV vs VIL 0.9 V. Checkerboard map (gen.py l.383-389) puts GND on both row neighbours of MIC_CLK (pins 2, 4) and MIC_DATA (22 and 20 beside LED_K). Lines 19.6 mm and 19 mm (M MIC_DATA) are far shorter than edge length (2 ns = 290 mm). Connector parasitics assumed (no Hirose model) | PASS (simulated, assumed parasitics), OPEN (TDR on a bench coupon) | sim/proof/k4_bm28_si.cir; pcbnew track lengths; hw/pod/k4/gen.py l.383 | 2026-10-08 |
| 12 | USB FS (12 Mb/s) through BM28 pins 11/13 | pcbnew lengths: P D+ 4.65 mm / D- 4.57 mm, M D+ 8.49 / D- 7.16 (0.09 mm tracks, 1 via each, GND pins 12/14 both sides); on-board total D+ 13.1 mm, D- 11.7 mm, skew 1.4 mm = 10 ps (6.9 ps/mm) vs 12 Mb/s bit 83 ns; no stubs (ESD U6 TPD2E2U06 in-line at the contacts, gen.py l.305). Dock wires 27-42 mm (physical.md l.181). FS edges are 4-20 ns (rise 4 ns => critical length ~ tr/6 / 6.9 ps/mm ~ 97 mm), so the whole path (<= 55 mm with wires) is lumped; FS has no board impedance spec (90 ohm differential is the HS/cable figure, uncoupled 70 ohm single-ended here, no effect at FS). Primary source, fetched and read 2026-10-08: USB 2.0 Specification Rev 2.0 (2000-04-27, usb.org release package usb_20_20240927.zip, https://www.usb.org/sites/default/files/usb_20_20240927.zip, file usb_20.pdf): section 7.1.2.1 FS 10-90 % rise and fall times 4 ns to 20 ns, matched within +/-10 %, monotonic, crossover VCRS 1.3-2.0 V; Table 7-8 FS driver output resistance ZDRV 28-44 ohm (so no board-trace impedance rule at FS); Table 7-9 cable ZO 90 ohm +/-15 % is the cable figure; the spec gives no FS PCB-trace length rule, only the edge-rate bounds used above | PASS (analytic) | pcbnew on routed_{P,M}.kicad_pcb; pin-contract.yaml | 2026-10-08 |
| 13 | Clock: LSE 32.768 kHz Y1 (7 pF) with C11/C12 8.2 pF | CL = 8.2 x 8.2 / 16.4 + stray (~3 pF) = ~7 pF; matches Y1. No HSE (internal oscillator) | PASS (analytic), bench confirm | bom_jlc_P.csv; docs/research/A3-clock-and-peripherals.md | 2026-10-08 |
| 14 | DRC (kicad-cli pcb drc, JLC 6L rules) | P: 0 violations, 0 unconnected; M: 0 / 0 | PASS | `kicad-cli pcb drc` run today on routed_P / routed_M | 2026-10-08 |
| 15 | ERC (SKiDL, gen.py) | 0 errors, 15 warnings (unconnected-by-design nets LDO_OUT/VBUS/VBAT, VLXSMPS pin type) | PASS | hw/pod/k4/gen.erc | 2026-10-08 |
| 16 | tools/checks/interfaces.py on K4 | since 56cf4fd it runs on K4 (ULTRASONIC_DESIGN=k4): mic-port, switch, outline, inside, clamp-bands (ledge), heights (37 parts), board-nets PASS; pins WARN (known ECR-0013 hazards); rails WARN uses unclamped peaks and the old 175 mAh cell pulse rating (350 mA), not K4's 130 mAh (260 mA): checker gap, fw clamp covers it (row 2); frame FAIL = vision line (parked for the pen test) | PASS with 1 checker gap | ULTRASONIC_DESIGN=k4 python3 tools/checks/interfaces.py, run by lead 2026-10-08 | 2026-10-08 |

## Part ratings vs worst case

| Part | Worst case | Rating | Margin | Status | Source |
|---|---|---|---|---|---|
| U4 TPS7A2030 | 219 mA clamped (326 unclamped) | 300 mA | +27 % | PASS (fw clamp) | row 4 |
| R20 0 ohm 0402 link | 326 mA | 1 A (2 A overload) | 3x | PASS | rail-budget.yaml (Uni-Royal 2019-02-26) |
| R21 0.1 ohm 0402 sense | 10 mW (315 mA) | 62.5 mW (0402 generic) | 6x | PASS | computed |
| R30 33 ohm 0402 mic filter | 1.35 mA: 60 uW; drop 45 mV | 62.5 mW | >1000x | PASS | sub-audio-in.md l.134 |
| D4 PMEG3005EL (Nexperia 30 V 0.5 A Schottky) | 130 mA charge | 0.5 A / 30 V | 3.8x | PASS | sub-dock-usb.md l.44 |
| D5 TPD1E10B06 (TI ESD diode) | VBUS 5.25 V | 5.5 V working | 5 % | PASS (thin) | sub-dock-usb.md l.42 |
| U6 TPD2E2U06 (TI USB ESD) | 5 V | 5.5 V | 10 % | PASS | sub-dock-usb.md l.45 |
| Q1/Q2 PMCXB290UE (Nexperia 20 V N+P pair) | 3.0-4.2 V, 315 mA | 20 V (current rating not in repo) | 5x V | PASS V, OPEN I | sub-output.md l.52 |
| L1 Murata 2.2 uH | core SMPS | Isat 2.4 A | see row 7 | PASS | sub-processing.md l.36 |
| BM28 contacts | 163 mA | 0.3 A | 46 % | PASS | row 10 |
| C9 2.2 uF 10 V X5R 0201, C17 1 uF 16 V 0201 (DC-bias derating) | 1.1 V / 4.5 V | Samsung curve not fetched (site blocks automated download; Murata SimSurfing also browser-only, queue.yaml A-CAP-CURVES, 2026-10-08): owner-download | n/a | OPEN (owner-download, A-CAP-CURVES) | docs/brief/queue.yaml |
| C14 22 uF 0603, C15 4.7 uF 25 V, C16 2.2 uF 10 V, C21 10 uF (on VBAT/VBUS, <= 5.5 V) | <= 5.5 V | voltage ratings not in the BOM names for C14/C21 | n/a | OPEN (owner-download, A-CAP-CURVES; ripple row 6 brackets kd 0.5..1) | bom_jlc_{P,M}.csv |

## What closes the FAILs and OPENs
1. Rows 2 and 4: choose the exciter resistance (12 ohm gives about 226 mA, under both limits) or accept the cell overrun after asking Renata for pulse duration; owner decision via ECR-0005. Then re-run `interfaces.py` with the K4 cell (260 mA) as the VSYS rating.
2. Row 16 (K4 rail checker) and the maker DC-bias curves (A-CAP-CURVES, owner download) remain. Rows 6, 11, 12 closed analytically/by sim 2026-10-08.
3. Row 11: TDR on a bench coupon only if the mic clock edge gets faster than R2 allows.

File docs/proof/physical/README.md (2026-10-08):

# Proof P-PHYS: is the K4 pod physically possible? (2026-10-08)
Re-run 2026-10-08, fenced 3G: `K4_RELIEF=lift python3 hw/mech/shell_k4.py` -> hw/mech/out/k4s_lift/checks.json (2026-10-08: cavity relief CELL_RELIEF_R 0.25 on the y0/z1 edge + 0.2 relief in the strut fill, cell unshrunk; all clashes and corridors 0); `python3 sim/checks/k4_heights.py` -> sim/out/k4_heights.json. k1t: hw/mech/out/k1t/checks.json (docs/research/k1t-vs-k4-parity.md, 2026-10-08). Figure: physical.png (plot.py).

| # | Check | K4 | K1-thin | Verdict | Source |
|---|---|---|---|---|---|
| 1 | 6L 0.8 mm stack-up (JLC) | JLC impedance page lists 6L only at 1.2/1.6/2.0 mm; 0.8 mm 6L unpublished; dielectric split chosen by JLC; no impedance control | n/a (4L 0.8 mm, JLC04081H-3313 published) | K4 OPEN (gate B4); k1t PASS | .pcba-workflow/k4-release/gate.yaml (fetched 2026-10-08); reg-board.md l.161 |
| 2 | Part heights vs floor (P file-B side) | clear nom 0.65, RSS 0.44, worst 0.163 (tallest L1 1.0) | board-B to cell 1.4, tallest 1.08, margin 0.32 | PASS both | k4_heights floor_side; k1t B_gap |
| 3 | Part heights vs lid (M file-B side + 0.25 VHB) | worst +0.112 (12 parts, 0 fail); only 0201-class under the lid; SW1 in pocket, mic bore | F gap slack 0.05 | PASS both (K4 thin); interfaces heights PASS 37 parts (C16/C17/C21 rows added to part_heights.yaml 2026-10-08, C16 from sibling-sheet T class) | k4_heights lid_side_M_fileB; k1t F_gap |
| 4 | Inner gap P-M (BM28 0.6 +-0.05) | 24 checked, 0 fail nominal/worst, 2 below margin | n/a | PASS (2 WARN) | k4_heights inner_gap |
| 5 | Clashes (shell checks) | all 0, corridors 0 (was tub/cell 0.145 mm3: cell edge in the R0.5 cavity fillet; fixed by shell relief: cavity y0/z1 edge R0.25 (was R0.5) and a 0.2 square relief in the strut fill at the cell's z0 corner; cell kept sharp, min resin 0.6, fill wall >= 0.71) | all 0, corridors 0 | PASS both | checks.json both |
| 6 | Printable (solids valid) | tub, lid, puck 1 solid each | all 1 solid; 0.6 wall corner 0.14 under chamfer, coupon unprinted | K4 PASS; k1t OPEN (wall coupon) | checks.json printable; parity doc gap 1 |
| 7 | Tolerance stack board/ledge/post (ECR-0023 add.2) | chain +-0.537 lin / +-0.215 RSS; post printed 0.5875 short, air gap 0.05..1.125, epoxy dab fills; ledge VHB 19 mm2 | no post | OPEN: epoxy fill (shrink, voids) is [A], bench-unverified; ledge alone 104 kPa vs 85 | k4_heights floor_post; docs/research/k4-ledge-margin.md; ECR-0023 |
| 8 | BM28 mated height | 0.6 mm gap +-0.05 [T] (C424570/C424571 BM28B0.6-30DP/DS, JLC 2026-10-08); in chain, floor worst 0.163 includes it | n/a (no B2B) | PASS | integration-map.md l.218; k4_heights TOL bm28 |
| 9 | Dock fit | head 21.2 x 6.86 on 4.4 flat belly overhangs T 6.4 by 0.23/side; tab to cell 3.55; tab-to-boss 0.45; clash dock_mags/dock_boss 0 | dock fits (clash/dock 0) | PASS (overhang is cosmetic, by design) | checks.json dock |
| 10 | Board in cavity | stack x 18.5-34.0, side gap 1.03, front gap 0.25 | board x 34.55-64.55, side gap 0.8, front 0.25 | PASS both | checks.json |
| 11 | Vision line (VISION_X 29.5 = pupil + 18 mm, estimate) | front X0 17.65: 11.85 mm inside; passes only if the pen-test line is <= 12.6 mm (parity doc) | X0 33.7: clear 4.2 mm | K4 OPEN (pen test, weekend bench day); k1t PASS on estimate | hw/mech/pod.py l.35; queue A-K4-VISION |
| 12 | Size | 49.85 x 6.4 x 15.25, 4805 mm3, 9.43-10.58 g | 33.8 x 8.5 x 14.8, 4779 mm3, 9.6-11.5 g | info | checks.json; parity doc |

## Bottom line
Geometry closes for K4 (no real clash, positive clearances at worst case). Three things are not proven: 6L 0.8 mm stack at JLC (B4), the epoxy post fill that keeps the ledge VHB alive under a 2 N press (bench), and the vision line (pen test). K1-thin is simpler on all three but owes the 0.6 mm wall coupon print, the button and duct fixes, and a release package (~5-6 h Claude time).

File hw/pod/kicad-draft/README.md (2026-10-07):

# Pod board: draft KiCad project (KiCad 10)

Open `pod.kicad_pro` in **KiCad 10** (the files are KiCad 10 format; KiCad 9 and older can't open them).
The project is self-contained: footprints, symbols and 3D models for the LCSC-sourced parts are in
this folder and referenced via `${KIPRJMOD}`. Standard parts use KiCad's own libraries.

## What this is
- **Board:** 20 × 11.5 mm, 4 layers, parts on both sides.
- **Placement:** by script (`hw/pod/place.py`).
- **Routing:** FreeRouting, fully routed.
- **DRC:** clean except the courtyard rings of neighbouring 1 mm test pads. Clearance is checked at JLC's 0.09 mm minimum.
- **`pod.net`:** the netlist from the schematic code (`hw/pod/gen.py`). The code is the source of truth; there is no `.kicad_sch`.
- **`bom_jlc.csv`:** every part with its LCSC number.

## What it is NOT
A proof that the parts fit and route. It is not a layout to order. Known issues to fix in the real layout:
1. **No ground plane.** The autorouter used all four layers for signals. Make In1.Cu a solid GND plane and route around it.
2. **The MCU's centre pad needs vias to ground** (thermal and ground).
3. ~~Mic port hole 0.5 mm~~ **Fixed 2026-09-30: 0.6 mm.** Spec §8 allows 0.6–1.0 mm, but the mic's ground ring has a 1.025 mm inner diameter, so 0.8 mm would leave only 0.11 mm to copper. 0.6 mm leaves 0.21 mm. Footprint `lcsc:Knowles_LGA-5_3.5x2.65mm_Port0.6`.
4. **The PMCXB290UE (Q1, Q2) footprint** comes from EasyEDA and has pads smaller than Nexperia's land pattern (datasheet Fig. 32). Redraw it before layout.
5. **SMPS loop** (U1 pin 20 → L1 → C8/C9): keep it tighter than the router did.
6. **Silkscreen** labels are shrunk to 0.4 mm so the board is readable; set real silk sizes for fabrication.

## Rev B updates (2026-09-30, after the audit)
**Done in this file:**
- **Board thickness 0.8 mm** with a real 4-layer stackup (it said 1.6 mm with no stackup). The dielectric values approximate JLC's 0.8 mm 4-layer build (7628/3313 prepreg class) `[Med]`. Pick JLC's stackup by name at order time and copy its exact numbers.
- **Mic port 0.6 mm** (item 3 above).
- DRC is unchanged at 186, all silk, text and test-pad courtyards.

**Not done here: import the new netlist** (`pod.net`, schematic Rev B) when you start the real layout (File → Import → Netlist):
- **U3 → MCP73832** (same SOT-23-5 footprint): open-drain STAT, so PA10 never sees 5 V.
- **New:** R11 100k (STAT pull-up), R12/R13 100k/100k (VBUS sense into PA1), C20 100 nF at VBAT pin 1.
- **Changed:** C4 → 10 µF **0603**; R1 (BOOT0) → 10k.
- **Also for the layout:** one 2.2 µF at **each** VDD11 pin (pin 46 has none); keep the SMPS loop tight.

**Audit claim checked and NOT upheld:** "TPS7A20 footprint pads oversized" (FP-1). The EasyEDA footprint matches KiCad's stock `Texas_X2SON-4_1x1mm_P0.65mm`, which is drawn from TI's DQN0004A drawing: signal pads 0.46 × 0.32 mm vs 0.46 × 0.31 mm, and the smallest pad gap is 0.134 mm vs 0.120 mm. The tight gap is the package's own; JLC's minimum is 0.09 mm. No change.

2026-10-07 (CHK-IDENT): the 'LCSC Part' properties were stripped from the 8 footprints in lcsc.pretty (same cleanup as ECR-0012 on the live library): footprints carry no part identity; the BOM comes from gen.py. This draft is superseded (hw/current.yaml); kept because sim/noise/pcbgeom.py cites its stackup lines as a source.

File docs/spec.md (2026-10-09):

# Stereo Ultrasound — Project Spec v0.14

**Owner:** Valkyrie
**Status:** Concept phase. §1 MVP confirmed by owner 2026-09-30. MCU (D5) and firmware toolchain (D15) decided. v0.5 applies the full-plan sanity check (`docs/research/review-2026-09-30.md`). Next: shopping-list approval (O3) → Phase 1 simulation and first bench orders. No hardware purchased.
**Last updated:** 2026-09-30 (Claude Code session). See §15 for the changelog.

**Confidence tags:** `[High]` verified from a primary source or well established · `[Med]` reasoned estimate, likely right · `[Low]` guess, verify before relying on it.

**Everything below §1 may be revised as evidence comes in. §1 is locked.**

---

## 0. Working rules (for Claude)

1. **§1 (MVP) is owner-locked.** Never change it. If evidence says part of it can't be met, say so bluntly and propose options, but leave the text alone.
2. **Gloss every part number** in plain language on first mention in any document or message: what it is, and why it's there.
3. **Primary sources.** Datasheets for specs; distributor or JLC listings for stock and price, always with the query date. Findings go in `docs/research/`, one file per task, and get summarized here. Numeric models live in `sim/` and are cited by script name.
4. **Decisions as 2–3 options with tradeoffs plus a recommendation.** The owner picks. Nothing is final without her approval.
5. **Part-choice checklist:** smallest package JLC can assemble · lowest power · **switching regulators only as allowed by D11** · in stock or sourceable. JLC "Basic" parts carry no setup fee, "Extended" parts carry a small one; say which.
6. **Teach the why** (DSP, PDM, noise shaping, power design), briefly and without condescension.
7. **Be blunt.** If something in this spec is wrong, flag it, fix it here, bump the version, and log it in §15.
8. **Show, don't just tell.** The owner is a visual learner. When a mechanism, layout, flow or comparison is involved, draw it: author the SVG in `docs/diagrams/`, render it with `docs/diagrams/render.sh`, and send the **PNG** into the chat, where it displays inline (SVG files only appear as file cards). Label the arrows; one figure, one claim.

---

## 1. MVP — LOCKED (owner-defined; do not modify)

### 1.1 Goal
A wearable that lets the owner hear ultrasound (roughly 20–96 kHz) in real time, in stereo, by shifting it down into a comfortable audible band and delivering it by bone conduction. It mounts on her everyday prescription glasses and must feel like an extension of her body, not a gadget.

### 1.2 Owner constraints
1. **Full-time glasses wearer.** The device clips onto her main glasses via removable 3D-printed clasps.
2. **Nothing Ear (open) headphones are worn constantly and reserved for phone audio.** The device must not use them as output, must not interfere with their fit, and must not bump the driver pod (over the ear opening, between helix root and tragus; shifts slightly during wear). The counterweight bulb sits behind the ear.
3. **Unusually good high-frequency hearing** (hears some charger and LED-driver whine). So: any self-noise must be no louder than the ambient background, and PWM noise is kept well above her hearing. *(Owner change 2026-09-30: the blanket "no switching regulators" rule was removed.)*
4. **Comfort and size are the top priority.** Bulky or uncomfortable means unworn means failed. Bulk goes at the front of the frame near the hinges, never near the neck or behind the ears.

### 1.3 Success tests
- **T1 House walk:** she hears ultrasonic sources (electronics, etc.) around the house. In Transient-only mode the house is tolerable, not overwhelming.
- **T2 Nature sit:** outside at dusk, bats and other ultrasonic wildlife come through as comfortable, non-shrill sound.
- **T3 Localization:** eyes closed, she can point left/right toward an ultrasonic source (e.g. a 40 kHz rangefinder emitter) better than chance.
- **T4 Coexistence:** Ear Opens worn and playing phone audio the whole time; no fit interference; both streams distinguishable.
- **T5 Wearability:** 2+ hours with no pressure pain at the transducer site or temples, including while talking and eating.
- **T6 Silence:** with no ultrasound present, the device is inaudible to her. No hiss, no whine.

---

## 2. Priorities (ranked)

1. Comfort, size, weight
2. Power draw
3. Circuit simplicity and part count
4. Cost
5. Sound pleasantness (close 5th; the reason for digital DSP over analog)

---

## 3. Architecture (per side)

```
                     32.768 kHz crystal ─▶ MSI (auto-trimmed) ─▶ PLL ─▶ 48–80 MHz per mode (D14) — every clock below derives from this
SPH0641LU4H-1 mic ◀── 4.0 MHz clock (SYSCLK ÷ 12…20) ──┐
      │ PDM 1-bit                                   │
      ▼                                             │
STM32L452 DFSDM (hardware PDM→PCM, sinc5 ÷10) ──────┘ 400 kS/s ──▶ half-band FIR ÷2 ──▶ 200 kS/s
      ▼
DSP: mic EQ → band select → shift or compress → transient gate → volume → safety ceiling   (output-band signal at 12.5 kS/s)
      ▼
×16 interpolation → 3rd-order noise shaper → TIM1 PWM, 200 kHz centre-aligned, 2-level (AD), 12.5–25 ns dead time
      ▼
H-bridge: 2× complementary MOSFET pairs (gates held off by pull resistors until TIM1 takes over) → RC-BC02 transducer

Power:    ~105–150 mAh LiPo along the temple arm (with protection) → MCP73831 charger → low-noise 3.0 V LDO → everything
Controls: 1 button; SWD pogo pads for programming; magnetic pogo pins for charging
```

Two identical, fully independent units, one per temple arm. No wires or radio between them (D2).
Every rate in the chain is an integer ratio of one 80 MHz clock. Any switching interference that leaks into the mic path therefore folds to 0 Hz and is filtered out (D14).

---

## 4. Decisions

Each decision gives the choice, the reasoning, and what was rejected. **vX.Y** marks the version that changed it.

### D1. Output site: at the tragus (primary); root of the cheekbone arch (fallback) `[High]` — **v0.5: moved to the tragus, owner-confirmed**
- **Primary site (owner, 2026-09-30; refined v0.7):** the skin **just in front of the tragus, at its base, at mid-tragus height**. The owner confirmed the tragus area is *easier* to fit than the cheekbone-arch spot alongside the Ear Opens. Geometry: `docs/research/ear-open-fit.md`.
  - **Why it wins:** the literature predicts ~10 dB more loudness and 25–40 dB of left/right isolation instead of ~10–15 dB. The mechanism is *cartilage conduction*: vibrating the tragal cartilage radiates sound into the ear canal (Surendran 2023).
  - **Consequences:** more loudness per milliwatt (battery, R1); much less crosstalk between sides (stereo, R5, D2).
  - **Fit with the Ear (open) (v0.7):**
    - Its hook junction comes down the front of the ear at the helix root, *above* the tragus, sitting 0–3 mm proud of the ear's front edge.
    - Its pod angles down and back into the ear bowl (concha), and its speaker grille aims at the canal entrance behind the tragus.
    - The only free contact spot near the canal is therefore **in front of the tragus, below the junction**. "Above the jaw joint" (v0.6 advice) is taken by the junction.
  - **Press inward (into the head), not backward.** Pushing the tragus flap back narrows the canal entrance the Ear (open) aims into, which breaks T4.
  - **Jaw:** the condyle is directly in front of the tragus, so this skin moves when you chew or open wide. The spring must hold ≥1 N through that motion (E2: talk and chew; T5).
  - The ear canal must stay open for the cartilage path to work. The Ear Opens don't block it.
- **Fallback site:** root of the zygomatic arch, about one finger-width above the jaw joint and 1–1.5 cm forward of the tragus. Kept in E2 as the comparison.
- **Evidence** (`docs/research/bone-conduction.md`):
  - The condyle region is 5–10 dB more sensitive than the mastoid at 1–4 kHz, and 3–14 dB more than the temple (McBride 2005/2008).
  - Localization through condyle-placed transducers matches headphones: ~23° error vs ~20° (Wang 2022).
- **Contact force:** aim for **≥1 N** through a compliant pad of **~8 mm** diameter (or an 8×10 mm oval, long axis vertical), which fits the pocket. That's ~17–20 kPa. Our inertial exciter loses only a few dB at ~1 N; below ~0.5 N coupling gets weaker and less repeatable. T5 comfort is the limit.
- **Rejected:**
  - Streaming to the Ear Opens (violates §1.2.2).
  - Temple: 3–14 dB worse, and a glasses-pressure headache spot.
  - Air-conduction speaker: the pod is in the way.
  - Mastoid: crowded by the Ear Open hook and counterweight.

### D2. Two independent mono units, no link `[High]` — **v0.5: phase caveat**
- **Why:**
  - At ultrasonic wavelengths the head casts a strong acoustic shadow, so the loudness difference between ears is the main direction cue. Each side processing its own mic preserves it.
  - No wiring across the hinges.
  - Each clasp is half the size.
- **Caveat (v0.5):**
  - At the fallback site (~10–15 dB of isolation), each ear also hears the other side's transducer. At the tragus site (25–40 dB) the crosstalk mostly disappears. Ren 2025 models a clean left/right cue once isolation is ≥20 dB, so the tragus site largely removes this risk.
  - The two unlinked units play with arbitrary relative phase, which changes the *size* of the left/right difference each ear receives.
  - A simple model keeps its *direction*, which is what T3 needs `[Med]`. Studies that got headphone-grade localization used phase-coherent stereo (Ren 2025; Rowan & Gray 2008).
  - **S4 measures it:** free-running units vs units sharing one clock. If the difference is large, revisit a link (see Parked ideas).
- **Cost accepted:** 2 MCUs, 2 batteries, no shared settings.

### D3. Fixed gain plus manual stepped volume; no automatic gain control `[High]` — **v0.5: controls detail**
- Independent automatic gain on each side would equalize the sides and erase the direction cue.
- Volume and mode **reset to known defaults at power-on**.
- **Because the sides can't sync (v0.5):**
  - Coarse volume steps (~4 dB).
  - Each change plays a short tick pattern saying which step you're on.
  - A long press returns that side to the default, so both sides can always be re-matched in two presses.

### D4. Digital DSP, not analog frequency division `[High]`
- Analog division (comparator plus counter) sounds harsh and buzzy and throws loudness away.
- The real-time digital options are heterodyne and spectral frequency compression (§5). Time expansion, which most bat demos use, can't run in real time.

### D5. MCU = STM32U575CIU6Q (QFN-48, 7×7 mm, internal SMPS) `[High]` — **Changed v0.12 (was STM32L452CEU6, decided v0.4)**
- **v0.14 note (audit MP-07):** the pin map and text below are the L452 history. The current pin map is `hw/pod/gen.py` and `A3-u575-plan.md` §3: mic on ADF1 (PB3 clock, PB4 data), bridge on TIM1 (PA8/PA7/PA9/PB0).
- **What it is:** ST's ultra-low-power Arm Cortex-M4F at 80 MHz, with DSP instructions, an FPU and 160 KB RAM. It includes the **DFSDM**, a hardware PDM-to-PCM converter for the mic. The v0.2 pick (L432) lacks the DFSDM. Details: `docs/research/A1-A2-mcu-and-mic.md`.
- **Pin check (v0.5):** every needed function is available on the 48-pin package.
  - mic clock PA5, mic data PB1;
  - bridge PA8/PA7 and PA9/PB0 (TIM1 CH1/CH1N, CH2/CH2N);
  - SWD PA13/PA14; crystal PC14/PC15.
  - See `A3-clock-and-peripherals.md` §5.
- **JLC:** Extended part C222355, **16 in stock** (2026-09-30). Buy early (R10).

- **v0.12: moving to STM32U575CIU6Q** (owner removed the SMPS rule; D11). It's a Cortex-M33 at up to 160 MHz with DSP and FPU and an internal core SMPS, in the **same 7×7 mm UFQFPN-48**. MCU run current ~19.5 µA/MHz vs 84. The 160 MHz headroom also removes the CPU risk for log compression (R3).
  - Drop-in alternative: STM32U585CIU6Q (same chip plus crypto).
  - JLC (2026-09-30): U575CIU6Q C5271013, 8 in stock, $8.93; U585CIU6Q C5271021, 15 in stock, $12.52. Stock is thin, so buy early.
  - **Must re-verify before the schematic (A1/A3 reopened):** the U5 replaces DFSDM with the **MDF/ADF** digital filters, so the clock plan, filter orders and pin map need redoing. Also the advanced timer with complementary outputs and dead time for the bridge, and the SMPS inductor layout.
- **v0.13: U5 plan done** (`docs/research/A3-u575-plan.md`; DS13737 Rev 8, RM0456 Rev 6, ES0499 Rev 10).
  - **Correction:** ~19.5 µA/MHz applies only in voltage Range 4. In Ranges 1–3 on the SMPS it's **~40–45 µA/MHz**, so algorithm B at 80 MHz draws **~2.5–3 mA**, not ~0.9 mA. That's ~45% less than the L452, not ~75%.
  - **Pins (SMPS package):**
    - mic on the **ADF**, which draws ~8× less current than the MDF and keeps running in Stop 2: clock **PB3**, data **PB4**;
    - bridge PA8/PA7/PA9/PB0 (TIM1 CH1/CH1N/CH2/CH2N, unchanged);
    - button PA0; battery sense PA4; SWD PA13/PA14; crystal PC14/PC15. Never toggle PC13, which sits next to the crystal (ES0499 §2.2.1).
    - Using PB3 costs the SWO trace pin. Fallback is the MDF on PB8/PB1.
  - SMPS parts: 2.2 µH inductor (Murata LQM21PN2R2MGHL, a 0805 chip inductor; C341781, Extended, 6,100 in stock on 2026-09-30), 2 × 2.2 µF on VDD11, 10 µF at the SMPS input.
### D6. Output stage: 200 kHz 2-level PWM, 3rd-order noise shaping, discrete H-bridge `[Med]` — **Rewritten v0.5**
- **What it is:** TIM1, the MCU's motor-control timer, switches an H-bridge made of two complementary MOSFET pairs (each pair is one N-channel + one P-channel transistor in a 1.6 mm package). The bridge drives the transducer directly, and the transducer coil smooths the switching into sound.
- **Carrier:** **200 kHz**, centre-aligned (ARR = 200), with one duty update per period over DMA. It is synchronous with the input chain (D14), and 201 duty levels.
  - *Changed from 312.5 kHz.* That rate wasn't a multiple of the sample rate, so switching leakage would fold to 87.5 kHz and play as a tone.
- **v0.14, audit MP-01: the shaper's noise lands in the mic band.** "Coherent clocks put leakage at 0 Hz" holds for the carrier and its harmonics, **not** for the noise shaper's broadband quantisation noise. At 200 kHz that noise sits at **−35 dB re full scale across 20–85 kHz** on the bridge voltage (−59 dB in coil current), which is exactly the band the mic processes. If any of it couples back (rail, ground, mechanical), the device hears itself. `sim/checks/pwm_ultrasonic_leak.py`, same timer clock (80 MHz):

  | PWM rate / levels | mic band (V) | audio band 3–16 kHz | extra gate current |
  |---|---|---|---|
  | 200 kHz / 201 (today) | −35 dB | −87 dB | — |
  | 400 kHz / 101 | −45 dB | −102 dB | +0.3 mA |
  | **800 kHz / 51** | **−59 dB** | **−117 dB** | **+0.8 mA** |

  **Recommendation:** leave the hardware as is. The PWM rate is a firmware setting, and all three rows run on the same timer and bridge. Measure the real coupling on the bench (S2), then pick the lowest rate that keeps the self-noise below the mic's own floor.
- **Modulation: 2-level ("AD").** The two bridge legs are driven as complements.
  - At idle, a small ripple current (≈ Vbus / (4·L·f), e.g. 12.5 mA at 0.3 mH) flows back and forth. It costs 0.04–0.4 mW.
  - While that ripple exceeds the signal current, the bridge's **dead-time errors cancel exactly**, so quiet sounds stay undistorted.
  - *Changed from the 3-level ("BD") idea in v0.3–v0.4.* BD has no idle ripple, and dead time then distorts quiet signals badly: −10 dB THD+N at −40 dBFS even at 12.5 ns (`sim/checks/deadtime_switching.py`, `C3-output-stage.md`).
- **Dead time:** 1–2 timer ticks (12.5–25 ns), set per measured MOSFET switching speed.
  - **v0.13, SPICE with the Diodes DMC2400UV model** (`C3-output-stage.md` §5):
    - no dead time means shoot-through: 4.3 mA at idle;
    - 12.5 ns: 0.49 mA idle, THD+N −61 dB at −40 dBFS and −52 dB at the −12 dBFS ceiling;
    - 25 ns: 0.20 mA idle, −48 / −38 dB.
    - Start at 12.5 ns; try 25 ns plus firmware dead-time compensation in S2. Gate drive is 0.28 mA.
- **Noise shaping:** 3rd-order error feedback with one zero at DC and a zero pair near 13 kHz, plus TPDF dither.
  - Modelled noise: −93 dB (0.2–8 kHz), −90 dB (8–20 kHz), −72 dB (20–40 kHz), relative to full scale after the coil (`sim/checks/ntf_compare.py`).
  - Dither is off while squelched, so silence is an exact 50% square wave with zero noise (T6).
- **Squelch:**
  - Short gaps: keep switching at zero signal.
  - Long silences and Off: stop with a soft start/stop, because starting the ripple abruptly makes a small click.
- **Reset safety:** TIM1 outputs float from reset until configured (RM0394). **Pull-up resistors on P-gates and pull-down resistors on N-gates are mandatory.** Configure the safe idle states (OSSI, OISx) before enabling outputs.
- **Rejected:**
  - Integrated H-bridge ICs. DRV8837 has 160–200 ns delays and 30–188 ns edges, and 0.7 mA even at 50 kHz. DRV8210 tops out at 100 kHz with 500 ns dead time. DRV8833 has 450 ns dead time, 450 ns deglitch and 1.1 µs delay.
  - Amplifier IC + DAC: quiescent current, and one more part.
- **Depends on E1** (coil inductance). If L ≥ ~1 mH, AD's clean range shrinks, so consider 100 kHz / ARR 400.
- **Gate charge matters for battery life (v0.6):** 4 FETs × Qg × 200 kHz is 0.4 mA at ~0.5 nC but 2 mA at ~2.5 nC. B1 prefers the low-gate-charge pair (DMC2400UV class).

### D7. Transducer = RC-BC02 / "GD02"-class module `[Med]` — **v0.5: specs disputed**
- **What it is:** a tiny inertial bone-conduction exciter, rated 300–19,000 Hz, 0.3 W nominal / 0.8 W max.
- **The maker's own pages disagree:** 12.5×5×3.5 mm and 8 Ω on one, **12.6×6×4 mm and 12 Ω** on another. **Measure a sample** (E1).
- **No inductance data exists anywhere.** The one bone transducer with published figures (Adafruit 1674, larger) is 1.26 mH / 5.8 Ω, so the 0.3 mH placeholder may be low. Higher inductance helps filtering and shrinks AD's clean range (D6).
- A DIY glasses build reported it as quiet. That's acceptable, and the D1 findings help.
- **Alternatives with maker specs, prices unverified:**
  - RC-BC95: 9.5×9×4 mm, 8 Ω, 600–15,000 Hz.
  - RC-BC09: 10.9×8.5 mm, 8 Ω, 100–5,000 Hz.
- **Bench comparison part:** Dayton BCE-1 (21×14×7.8 mm, 4 Ω).

### D8. Factory assembly at JLCPCB `[High]`
- All SMD parts are machine-placed. The owner hand-solders only the transducer leads, the battery, and optionally the button.
- The mic is a land-grid part that can only be reflowed, and it is JLC-stocked (D13).

### D9. Output band ≈ 1.5–4 kHz `[Med]` — **v0.5: keep the floor ≥1.5 kHz**
- This is the ear's most sensitive region, near typical bone-transducer resonance, so it gives the most loudness per milliwatt.
- **Keep the floor at or above ~1.5 kHz.** Below that, the ear is sensitive to waveform phase. The two unlinked units' random phase could then scramble direction (D2).

### D10. Band floor calibrated to the owner's hearing `[High]` as a principle
- Measure her upper hearing limit (C5/E5). Start the processed band just below it, so there's no gap and no doubled sounds. Stored as a firmware constant, identical on both sides.

### D11. Switching regulator for the MCU core; linear for everything else `[Med]` — **Changed v0.12 (owner)**
- The owner removed the no-switching rule. The limit is now that self-noise is no louder than the ambient background (§1.2.3).
- **Use:** the MCU's internal SMPS for its ~1.2 V core only. That's where the efficiency gain is: the core's LDO throws away about 60% of its input.
  - Keep it in fixed-frequency (PWM) mode, never burst/skip mode, which is the usual source of audible whine at light load. **v0.13:** the U5 has no mode bit for this. Its SMPS switches at a fixed ~3 MHz in voltage Ranges 1–3 and runs asynchronously only in Range 4. **Rule: never run Range 4 on the SMPS.** Stop 2 stays on the SMPS (ES0499 §2.2.22: Stop 2 on the LDO with RAM partly off can lock the part).
  - Use a shielded, low-magnetostriction inductor. **v0.13:** the switching pin itself carries no capacitor. ST requires 2 × 2.2 µF on the core rail and 10 µF at the SMPS input, and no C0G part comes in those values. So those are X5R, placed at the MCU, away from the mic and on the far side of the board from it. Parts: Murata DFE201610E-2R2M (a shielded 2.2 µH metal-alloy inductor, 2.0×1.6 mm; C337891); `B-parts-selection.md`.
- **Main 3.0 V rail stays a linear LDO.** A battery-to-3.0 V buck would save only ~10%, and the mic and bridge supply benefit from a quiet rail.
- **Check:** the owner's listening test on the bench (E11). If whine is audible over a quiet room's background, fall back to the LDO. The chip can switch regulators on the fly.

### D12. Modes `[High]` as requirements
- **Full:** the whole band, pitched down.
- **Transient-only (indoor default):** steady tones (charger and LED-driver whine) suppressed; changing sounds (chirps, clicks, rustles) passed through.
- **Off:** silent. MCU in Stop 2 (~4–9 µA on the U5, v0.13), mic unpowered, bridge stopped.
- **v0.11 (owner):** if log compression (B) sounds better in Phase 1 listening, it becomes the **only** processing mode. The always-on current difference is ~1.6 mA, and with idle-listening mode ~0.4 mA. Heterodyne (A) stays in the code only as a fallback if B won't fit the CPU (R3).

### D13. Mic = SPH0641LU4H-1 digital MEMS with ultrasonic mode `[High]` — **v0.5: lifecycle OK, response data**
- **What it is:** a Knowles/Syntiant microphone, 3.50×2.65×0.98 mm, bottom port Ø0.325 mm, 1-bit PDM output.
  - Ultrasonic mode takes a 3.072–4.8 MHz clock and draws 845 µA typical.
  - Sensitivity matching is ±1 dB.
- **Lifecycle:** Active at DigiKey (22k in stock). Syntiant reissued the datasheet as Rev B-1 in Dec 2024. JLC C2879853, Extended, 1,076 in stock, $1.99 (2026-09-30).
- **Response (digitized from the datasheet, `sim/data/sph0641_ultrasonic_response.json`):** relative to 1 kHz,
  - +1.6 dB at 10 kHz, **+14.7 dB at 25 kHz**, about +8 dB across 35–65 kHz, +12.7 dB at 80 kHz.
  - The mic is *more* sensitive in ultrasound than at 1 kHz, which is good for distant bats (R8).
  - The 25 kHz peak is an acoustic-path resonance **on the test fixture**. Our port hole, clasp wall and mesh will reshape it. Hence the DSP **EQ stage**, the acoustic-path rules in §8, and the coupons in S1.
- **Firmware rules:**
  - Never power up or wake straight into ultrasonic mode. Start in standard mode (1.024–2.475 MHz), then raise the clock. Mode change ≤10 ms; power-up ≤50 ms.
  - Clock duty cycle 48–52% above 2.4 MHz (see D14 for the risk).
  - The SELECT pin must be tied, not left floating.
  - **No Class-2 ceramic capacitors (X5R/X7R) near the mic.**
- **Backup:** TDK T5838, a PDM mic with an ultrasonic mode, characterized only to **50 kHz**. It covers the bat band. JLC C7230692, 684 in stock.
- ⚠️ **Don't buy the RAK18032** "ultrasonic SPH0641" board. It actually carries the SPH0655, which is audio-only.

### D14. Clock tree and sample rates `[Med]` — **Rewritten v0.5**
- **Everything from one 80 MHz clock:**
  - mic clock 80 MHz ÷ 20 = **4.0 MHz** (even divider);
  - DFSDM sinc5 ÷10 → **400 kS/s**;
  - CPU half-band ÷2 → **200 kS/s** (Nyquist 100 kHz; usable to ~80–85 kHz);
  - DSP output at **12.5 kS/s**;
  - ×16 interpolation → **200 kHz** PWM update.
  - Stays in voltage Range 1: Range 2 caps peripheral clocks at 26 MHz.
- **Why synchronous:** switching interference coupling into the mic path folds to 0 Hz, where the band-floor high-pass removes it (T6).
- **Per-mode system clock (v0.6, power):** the tree works at any clock that's a multiple of 8 MHz. The mic divider becomes f/4 MHz (always even) and the PWM period ARR = f/400 kHz: 48 MHz → ARR 120; 64 MHz → ARR 160; 80 MHz → ARR 200.
  - Algorithm A runs at **48–64 MHz**, saving ~0.8–1 mA. Algorithm B needs **80 MHz**.
  - Mic clock and PWM rate stay the same; only the PWM step count changes (121–201 levels, fine with the 3rd-order shaper). Switch clocks only at mode changes, since DFSDM must restart.
- **DFSDM details** (RM0394; `A3-clock-and-peripherals.md` §3):
  - The CKOUT divider can only change with DFSDM disabled. The standard→ultrasonic mode switch is therefore stop, re-divide, restart; the µs gap is harmless `[Med]`.
  - Use **filter 0** (DMA1 channel 5). Filter 1 shares channel 6 with TIM1's update request.
- **v0.13, STM32U575 (`A3-u575-plan.md`):**
  - Clock: MSI locked to the 32.768 kHz crystal, **80 MHz in voltage Range 2** (allows up to 110 MHz). Actual 80.009 MHz; mic clock 4.0004 MHz; PWM period 200 counts; dead time in 12.5 ns steps, set separately for rising and falling edges.
  - Mic decimation in hardware: ADF sinc5 ÷5 → 800 kS/s, then its reshape filter ÷4 → **200 kS/s** (passes to ~89 kHz, rejects ~70 dB above ~120 kHz). The CPU half-band disappears. Fallback: ÷10 + CPU half-band, as before. ST publishes no response at this rate, so S1 sweeps it.
  - GPDMA takes any request on any channel, so the L452's DMA conflict is gone.
  - **Errata firmware rules (ES0499 Rev 12, checked 2026-09-30):**
    - handle the MSI PLL unlock interrupt by disabling and re-enabling PLL mode (spurious unlocks, §2.2);
    - switch PLL2/PLL3/HSI48/SHSI off before Stop 2 (§2.2.5);
    - never use TIM1 ocref_clr with combined or asymmetric PWM (no workaround); faults go through BKIN.
  - Idle mode: ADF + low-power DMA keep filling a ~40 ms look-back buffer in Stop 2. The ADF's built-in sound-activity detector is broadband: speech and footsteps trip it as easily as bats. So band detection stays in software (C9).
- **⚠️ Duty-cycle risk:** DFSDM's clock output is characterized at 45–55% on a sister chip. The mic needs 48–52%. Typical is 50%, and **S1 scopes it**. Fallback: a timer-generated clock into DFSDM's CKIN pin.
- **Decimation choice (S1 measures both):**
  - default ÷10 + CPU half-band (5–10 MHz of CPU, cleaner top octave);
  - power-saving option: DFSDM ÷20 alone (0 CPU, ~12 dB droop at 80 kHz, more folded noise near the top).
- **Band-edge note (MVP says "roughly 20–96 kHz"):** realistic top is ~80–85 kHz. The mic is characterized only to 80 kHz.
  - Option if the top octave matters: 80 MHz ÷ 18 = 4.44 MHz mic clock → 247 kS/s, for +23% CPU.

### D15. Firmware toolchain: bare C with CMake, CMSIS + ST LL drivers, CMSIS-DSP `[Med]` — **Decided v0.4 (delegated to Claude)**
- **Stack:**
  - C11 built with `arm-none-eabi-gcc` and CMake from the command line.
  - ST's CMSIS device headers plus LL (thin register-level) drivers.
  - CMSIS-DSP for FFT, FIR and vector math.
  - CubeMX only as a read-only pinout and clock checker.
- **Why:** the design is timing-critical glue (DFSDM → DMA → CPU → TIM1 DMA). Register-level control keeps timing explicit. CMSIS-DSP is also what the C2 benchmarks measure. The build is reproducible.
- **Owner side:** flash and debug through the Nucleo's ST-LINK (STM32CubeProgrammer, OpenOCD, or VS Code + Cortex-Debug).
- **Rejected:**
  - CubeIDE + HAL: heavy, and hides timing.
  - Rust: immature DFSDM support.
  - Zephyr: heavyweight.

### D16. Crystal clock reference `[High]` — **New v0.5**
- **Why:** the internal oscillators are off by up to ~1–2% between units. Heterodyne output = input − oscillator frequency, so a 1% error on a 38 kHz oscillator plays the same bat call **380 Hz apart** in the two ears.
- **Recommended:** a **32.768 kHz crystal** (LSE, "watch crystal") auto-trimming the MSI oscillator, which feeds the PLL.
  - About 0.3 µA, one crystal and two capacitors.
  - JLC options: Seiko Epson **Q13FC13500004** (FC-135, 3.2×1.5 mm), C32346, **Basic part (no setup fee)**, 467k in stock, $0.17. Or Seiko Epson **X1A0000610002** (2.0×1.2 mm), C55208, Extended, 22.5k in stock, $0.24.
- **Fallback:** 8 MHz crystal (HSE). Lower clock jitter, but +0.44 mA and a slightly larger part. S1 compares the noise floor with each on the Nucleo.
- **Residual:** crystals leave ~1–2 Hz between sides in heterodyne mode. That can cause a slow level wobble on *steady* tones through bone crosstalk. Transient-only mode removes steady tones, and bat calls last milliseconds. Accepted.

### D17. Output safety: fixed ceiling and pop-free start `[High]` as requirements — **New v0.5**
- A **fixed output ceiling** (soft clip), identical on both sides. With fixed gain (D3), a loud nearby source would otherwise become a loud output. Examples: an ultrasonic pest repeller, or the HC-SR04 up close.
- Power-up, mode changes and squelch transitions must not click (D6 soft start).
- **Owner ruling 2026-10-08 (decisions-log #2): "A + L".** The limiter ceiling rises from -12 dBFS to the firmware current clamp (look-ahead limiter on by default, `lim_lookahead` 1); the loud toggle is live (`loud_db` 12; HOLD2 in gesture option A, triple press in B) and loud mode is OFF at every boot. The ceiling is still fixed and identical on both sides. Cost: `docs/proof/electrical/d17-cost.md`. Battery saver (idle doze) stays off by default with a manual toggle (knob `idle_enable`).

### D18. Runtime and weight balance `[High]` as requirements — **New v0.6 (owner, 2026-09-30)**
- **Runtime:** ≥8 h per charge, target ~12 h. Nightly charging.
- **Battery:** bay sized for a ~150 mAh cell (~4.5 g); a ~105 mAh cell is the minimum. The exact cell is picked after E4 current measurements (§7).
- **Balance (owner: "design for balance as needed"):** the cell sits along the temple arm behind the front module, centred as far back as the Ear Open hook allows. This splits the added weight between nose pads and ears instead of loading the nose (§8 table).
- **Interpretation of §1.2.4** ("bulk at the front near the hinges, never near the neck or behind the ears"): nothing goes behind the ear or toward the neck. The electronics stay at the hinge; only the cell moves rearward along the arm, in front of the ear. §1 text unchanged. **The owner should confirm this reading** (O4).

### Parked or rejected ideas
- **Forward "gaze distance" sensing:** redundant with stereo vision.
- **Haptic channel for >60 kHz:** optional future layer. Anything vibrating on the head is also heard by bone conduction.
- **Blindspot Proximity on the glasses:** parked. Long hair blocks rear-facing ToF sensors.
- **Link between the two sides** (for phase-locking, shared volume, or crosstalk cancellation). Parked; revisit only if the S4 shared-clock A/B shows free-running phase hurts direction.
- **Bone-conducted ultrasound as the output** (skipping the frequency shift). Rejected: it needs ~55–60 dB more drive, has ~18 dB of usable range, and is always heard at one fixed pitch (Nakagawa 2020).

---

## 5. DSP

### 5.1 Input chain
- 200 kS/s single channel (D14). Usable band ~20–85 kHz; the mic is characterized to 80 kHz.
- **Mic EQ:** flatten the measured response (D13: a 13 dB tilt across 10–25 kHz and a +15 dB peak at 25 kHz). Free per-band gains in B; in A, one gain per oscillator setting. Final curve comes from S1 coupon measurements.
- **Band floor:** a high-pass at the D10 frequency removes audible-band content.
- Local bats (big brown, eastern red) call at roughly 25–50 kHz `[Med]`; verify in C6.

### 5.2 Algorithms (both built in simulation; chosen by listening)
- **A. Heterodyne (low CPU, ~23–48% of the MCU):**
  - Multiply by an oscillator (LO), low-pass, decimate to 12.5 kS/s.
  - Clean and tonal, one band at a time; the oscillator frequency is tunable.
- **B. Log frequency compression ("pretty" mode) — restructured v0.5 (~55–81% of the MCU):**
  - **Analysis:** a 256-point FFT at 50% overlap (0.64 ms hop, 781 Hz bins).
  - **Grouping:** bins go into ~32 log-spaced bands across ~20–85 kHz, each with its own noise floor, gate, and EQ gain. The 781 Hz bin width limits how narrow the lowest bands can be.
  - **Synthesis:** ~32 sine oscillators at 12.5 kS/s. Each band plays at its mapped frequency in ~1.5–4 kHz with the band's envelope.
  - Keeps timing and relative loudness across the whole band. The frequency map is fixed and identical on both sides.
  - *Why the change:* STFT + inverse STFT at 200 kS/s needs 85–119% of the CPU against published Cortex-M4 FFT timings (`C2-cpu-budget.md`).
  - *Sound difference:* a smooth "channel vocoder" rather than a phase-vocoder rebuild of the waveform. Phase 1 renders both for comparison.
  - **Levers if tight:** q15 FFT (~1.5× faster), 128-point FFT, fewer bands, DFSDM ÷20. The C2 budget assumed 48 oscillators, so ~32 adds margin.
- **Transient-only gate:**
  - In B, per-band spectral subtraction against a slowly updated floor.
  - In A, an envelope squelch with a slow floor.

### 5.3 Latency
- Target ≤20 ms end to end `[Med]`. Analysis frames are 1.28 ms with 0.64 ms hops, so there's plenty of room.

### 5.4 Controls
- One button: short press cycles modes; press-and-hold steps volume with tick feedback; long press resets that side (D3). Both reset at power-on.

---

## 6. Output stage: noise and linearity — **rewritten v0.5** (details: `docs/research/C3-output-stage.md`)

- **Noise is fine.** Quantization noise with the 3rd-order shaper sits ~90 dB below full scale across 0.2–20 kHz, and zero when squelched.
  - Bone-conducted ultrasound needs ~55–60 dB more drive than the 2–4 kHz band, so 20–40 kHz residue at −72 dB is irrelevant.
  - The band to protect is **8–16 kHz**: bone-conduction thresholds there track normal hearing (Popelka 2010), and the owner hears high. That's why the shaper's zeros sit near 13 kHz.
  - *v0.3 overstated this as the top risk. It was wrong.*
- **Linearity at low levels is the real risk.** Handled by 2-level modulation (D6), which is exactly clean while the ripple current exceeds the signal current. Quiet listening (≲ −30 dBFS at 0.3 mH) falls in that range. Louder signals get some distortion, masked by their own loudness.
- **Measured in S2, not assumed:**
  - idle silence (T6) with the bridge running;
  - low-level distortion via a 1 Ω sense resistor and a sound card;
  - 8–16 kHz noise by ear with squelch forced open.
- **Capacitor rule:** keep audio-rate voltage ripple off Class-2 ceramic caps on the bridge rail (they can "sing"), or use low-acoustic-noise types.

---

## 7. Power (per side) — **v0.6: sized for 8 h minimum, ~12 h target (owner, O1)**

**Requirement (D18):** at least 8 h of wear per charge, ideally ~12 h. Nightly charging.

**Budget after v0.6 optimizations** (tragus site, low-gate-charge MOSFETs, per-mode clock):

| Block | Current | Basis |
|---|---|---|
| Mic, ultrasonic mode | ~0.9–1.1 mA | 845 µA typ at 1.8 V; rises with supply and clock load `[High]` |
| MCU, algorithm A at 48–64 MHz | ~2.4–3.9 mA | 19–39 M cycles/s; 84 µA/MHz run, 27 µA/MHz sleep (`C2-cpu-budget.md`, D14) `[Med]` |
| MCU, algorithm B at 80 MHz | ~4.7–5.8 mA | 44–65 M cycles/s `[Med]` |
| Peripherals (TIM1, DFSDM, DMA) | ~0.6–1.0 mA | TIM1 8.1 µA/MHz `[Med]` |
| Bridge: gate charge + idle ripple | ~0.4–0.6 mA | 4 FETs × ~0.5 nC × 200 kHz with a low-gate-charge pair (B1); ripple loss 0.04–0.4 mW `[Med]` |
| Transducer, average at listening level | ~0.6–1.7 mA | was 2–5 mA; the tragus site needs ~10 dB less drive (D1) `[Low]`, measure (E4) |
| LDO, crystal, battery protection | <0.05 mA | `[Med]` |
| **Total** | **~5–8.5 mA (A), ~7.5–10.5 mA (B)** | `[Low]` until E4 |

**Runtime** (usable ≈ 85% of rated capacity):

| Cell | Algorithm A | Algorithm B | Meets |
|---|---|---|---|
| ~105 mAh | ~10.5–18 h | ~8.5–12 h | 8 h everywhere; 12 h in A |
| ~120 mAh | ~12–20 h | ~9.5–13.5 h | 12 h in A, most of B |
| **~150 mAh** | **~15–25 h** | **~12–17 h** | **12 h everywhere, even at the pessimistic end** |

**Recommendation:** design the battery bay for a ~150 mAh cell (≈4×12×40–45 mm, ≈4.5 g). Fit anything from ~105 mAh up once E4 measures real current.
- The estimates are `[Low]`, and the extra ~1.5 g costs little when placed for balance (§8).
- Charge at ≤0.5C (MCP73831 set to ~50–75 mA): ~2.5–3 h, overnight.

**Power levers, most effective first:**
1. Transducer at the tragus (D1, done).
2. Squelch with CPU sleep.
3. Algorithm choice (A is ~2.5 mA cheaper).
4. Lower clock for A (D14).
5. Low-gate-charge MOSFETs (B1).
6. DFSDM ÷20 (saves 0.3–0.6 mA of CPU).
7. **Idle-listening mode** (C9, `[Low]` estimate): when nothing ultrasonic is happening, run only a cheap band-energy detector at a low clock and keep a ~10 ms look-back buffer. Wake to full processing on activity, with the buffer covering the wake-up, so call onsets aren't clipped. Could save ~1–2 mA in quiet periods. Evaluate in S3.

**v0.10 power findings (2026-09-30):**
- ~~STM32U575: 19.5 µA/MHz on its internal SMPS … MCU ~3.8 → ~0.9 mA~~ **Corrected v0.13:** that figure is Range 4 only. At 80 MHz in Range 2 on the SMPS the MCU draws ~2.5–3 mA with algorithm B (DS13737 Rev 8 Table 39; `A3-u575-plan.md` §5) `[Med]`.
- **The big allowed lever is the idle-listening mode (C9), now the top power item.**
  - When the ultrasonic band is quiet, the CPU clock is divided down, a few band-energy detectors (each with a slowly tracking floor, so steady whines don't count) run on the DFSDM stream, and the bridge stops. The mic clock never changes, so there's no DFSDM restart.
  - A ~10 ms look-back buffer covers the wake-up, so call onsets aren't clipped.
  - Estimated draw at 75% quiet time: ~3.3 mA (A) and ~3.7 mA (B), against 7.2 and 8.8 mA always-on, so 8 h needs ~35 mAh instead of ~70–85 mAh `[Low]`.
  - Worst case, when the band is always busy, falls back to full draw. So the cell should still be sized for the always-on case, or for a measured duty cycle from E4.

**v0.14 budget: supersedes v0.13 below** (`sim/checks/power.py` rev 2; audit PWR-01..04, dsp-1/2/8):
- **Mic current re-derived at our 3.0 V / 4 MHz:** 1.1 / 1.35 / 2.15 mA. It was quoted at the datasheet's 1.8 V / 3.072 MHz point. Bridge 0.77 mA from our own SPICE; gate pulls added; transducer range widened (still an untraced guess until E1/E4).
- **The pessimistic case now also shrinks capacity:** 90% / 85% / 75% usable.
- **Full chain awake:** 5.0 / 6.8 / 9.8 mA. **Idle:** 1.7 / 2.2 / 3.4 mA.
- **Idle detector rev 2** (FFT snapshot every 5 ms plus a narrowband test; `sim/checks/idle_detector.py`). The old detector woke on audible speech: 95% awake on speech alone, and 67% in a room without electronics. Its 14% was the synthetic whines masking this. Rev 2 results:
  - awake time: speech only 5%, quiet room 18%;
  - Port Meadow (real AudioMoth recordings, 270 files): 95.5% of 10,024 annotated bat calls caught within 10 ms, and no pass missed entirely;
  - CPU: ~3.4 Mcycle/s, down from ~12. It fits the 16 MHz idle clock.
- **Runtime with 105 mAh:**
  - awake all the time: **8.0–13.2 h**;
  - half the time: 11.9–19.9 h;
  - quiet room: 17–30 h.
- **So the 8 h minimum holds even never sleeping, with no margin.** The idle mode is now load-bearing; keep 105 mAh (O5).

**v0.13 budget (superseded by v0.14 above; U575 on SMPS + idle-listening mode; `sim/checks/power.py`):**
- **Full chain awake:** 4.6 / 6.0 / 7.5 mA (low / nominal / high). **Idle:** 1.5 / 1.9 / 2.4 mA; the mic (~1 mA) is now the biggest idle load.
- **Awake time** from the Phase-1 DSP model (`sim/dsp/run_phase1.py`): **14%** on a simulated quiet evening, with all 4 events caught within 10 ms; 93% on a deliberately busy scene.
- **Runtime with a 105 mAh cell:**
  - awake all the time: **11.9–15 h**;
  - half the time: 18–23 h;
  - quiet evening: 29–37 h.
  - So 105 mAh meets 8 h everywhere and 12 h at nominal draw even if the chain never sleeps. An 80 mAh cell drops to 9.1 h at the pessimistic always-awake end, so keep 105 mAh (O5).

**Supply rail** `[Med]`:
- **3.0 V from a low-dropout LDO**, leaving ~300 mV of headroom at the LiPo's 3.3–3.4 V knee.
- Bridge supply stays on the regulated rail. Running it from the battery would make gain track charge by ≈1.8 dB and unbalance the sides.
- 2-level modulation *prefers* the full 3.0 V: more ripple means a wider clean range.

---

## 8. Physical layout (per side) — **v0.6: split along the arm for balance (D18)**

> **v0.8 (owner, 2026-09-30): one pod between the eye and the ear, swept-back arm.**
> Measured on the owner's photos (`docs/research/ear-open-fit.md`; scale ±20% until the ruler shot):
> - **Pod:** a single pod on the temple arm, from just behind the hinge to ≥5 mm ahead of the
>   Ear (open) hook. That's **~60 mm** of usable length, and it holds both the electronics and the battery.
> - **Arm (owner's aesthetic request):** swept **back** from the pod's rear-lower edge to the pad.
>   - Any sweep of 11° or more clears the Ear (open) by ≥5 mm.
>   - **25–35°** looks clearly swept and clears by 8–9 mm; the arm is ~22–24 mm long.
>   - Starting the arm further forward lengthens it (softer spring, more snag risk) without adding clearance.
> - **Fit:** PCB (~20 mm) + ~105 mAh cell (~30 mm) + walls ≈ 54 mm fits in line. A 150 mAh cell
>   (40–45 mm) does not fit in line; it would sit beside or under the PCB (a thicker pod), or
>   needs a shorter, fatter cell. B4 decides.
> - **Balance:** with the pod centred ~35 mm behind the hinge, the nose pads carry 3.9 g per side
>   (105 mAh) or 4.9 g (150 mAh), against 3.1–3.7 g for the cell-further-back layout below.
>   That's the price of keeping everything in front of the ear hook. The owner's call (O5).
>
> The v0.6 text below remains the fallback.
>
> **v0.14: CAD rev 2** (`hw/mech/pod.py`; sketches `hw/mech/out/pod_sketches.png`):
> - **Pod grows to 38 × 10 × 15 mm** (was 35 × 9 × 14). The cell is now modelled at the EEMB LP401230 spec sheet's **maximum** envelope (31 × 4.3 × 12.5), plus a ~3 mm protection board `[Low]`, with 0.3 mm assembly clearance. The v0.13 box fitted only the nominal cell with zero clearance. All 8 checked part pairs clear by ≥0.2 mm. ~7.1 g per side.
> - **Arm drawn as the real NiTi wire** in two variants for the reopened O7 (A: 20 mm on the plateau; B: 30 mm elastic, anchor moved forward, pad unchanged). Owner kept A's geometry (O7b).
> - **Exterior, owner 2026-09-30: "Blade"** (`hw/mech/blade.py`):
>   - gunmetal armour plate with an engraved circuit-trace groove (airbrush chrome if wanted);
>   - a tapered dorsal fin growing out of the plate, and a matching heel under the rear that holds the arm root;
>   - a hex pad whose ring is either LED-lit (O8) or chrome.
>   - **No UV or glow prints** (owner). Pod shell, plate, fin and heel print as one part.
> - **Frame adapter is a separate print (owner requirement: swap it for new frames without reprinting the pod).**
>   - It slides onto a dovetail rail on the pod's inner face from the front, stops at the rear, and a printed snap tab clicks over a ramp.
>   - To release it, push the tab's foot with a fingernail and slide it forward.
>   - It is parametric in the temple-arm section (`pod.TEMPLE_T/H`).
>   - Cost: **1.8 mm more stand-off** between temple and pod. The pad position is unchanged.
> - **Exterior history:** not final (owner): 3D-printed, cyberpunk ("Night City"), not a brick. Three concepts on the same insides: `hw/mech/styles.py`, rendered by `hw/mech/render_styles.py` (Blender, CPU). Glow parts are separate prints (UV-reactive/glow filament, no power).
>
> **v0.13: first CAD and spring study** (`hw/mech/pod.py`, `sim/checks/tragus_spring.py`, `docs/research/tragus-arm.md`):
> - **Pod:** 35 × 9 × 14 mm. The 105 mAh cell sits against the inner wall; the 0.8 mm PCB (**20 × 11.5 mm**, raised from 10 mm so the MCU's wiring can escape; `hw/pod/place.py` routes it completely, DRC clean) is outboard, with the mic porting outward at the front. Zero interference.
> - **Mass:** 7.75 g per side, centre of mass 52 mm behind the hinge: **nose pads 3.7 g, ear 4.1 g**.
> - **Spring:** a one-piece steel strip can't hold 1 N at this length without fatigue. **Recommended: rigid arm on a pivot with a preloaded torsion spring** (Ø0.65 mm wire, 7 turns, Ø5.2 mm): 0.99–1.26 N over ±2 mm of jaw travel. Alternative: superelastic NiTi wire, ~1.0 N settled, ~2.3 N while putting the glasses on. **O7 resolved: the owner chose NiTi.**
> - **Transducer orientation:** the RC-BC02 housing (~14 mm long) must lie **along the arm**. Stood vertically, its top end comes within ~2 mm of the Ear (open) hook junction; along the arm it clears by ~5.8 mm.
> - **Reaction:** the pad's 1 N pushes the temple arm outward and twists it (~25 N·mm). The clip needs ~5 N of grip on the arm's top and bottom edges. New E12 measures her temple arm's stiffness.
>
> **v0.9 (owner): peripheral vision is a hard no-go zone. No part of the device may be visible
> with the eyes looking straight ahead.**
> - **Estimate:** the temporal visual field reaches ~100–110° from straight ahead. For an object
>   ~35 mm out to the side of the pupil, that's visible up to ~6–13 mm *behind* the pupil plane.
>   The design limit is a 110° field plus a 5 mm margin: **nothing forward of ~18 mm behind the
>   pupil plane.** On the owner's photo that leaves **~35 mm** of temple arm for the pod, not 60 mm.
> - **Consequences:**
>   - The in-line PCB + cell layout no longer fits. The pod becomes ~35 mm long, with the PCB
>     stacked beside or under a ~30 mm (~105 mAh) cell, so it's thicker (~8–10 mm).
>   - Balance improves: the pod is centred ~47 mm behind the hinge, putting 3.2 g per side on
>     the nose pads (105 mAh) or 4.0 g (150 mAh).
>   - The swept-back arm (25–35°) is unchanged.
> - **Hard rule:** the owner's measured field (E10) overrides this estimate. The mic stays in
>   front of the hair (E9) *and* behind the vision line, so it goes at the pod's front end.

- **Front module, at the hinge:** PCB, mic, button, crystal.
  - **PCB size** `[Med]` (parts-area estimate): ~10×20 mm with parts on both sides (4-layer), or ~10×28 mm single-sided. The 7×7 mm MCU sets the ~10 mm width.
  - The mic faces outward here: the head-shadow cue needs it on the side of the head, and the front keeps it clear of hair and the Ear Open.
- **Battery bay, behind the front module along the temple arm:** the cell lies along the arm (long axis front-to-back), centred ~50–60 mm behind the hinge. It ends before the Ear Open hook, so nothing is behind the ear (§1.2.4). A 2-wire link runs from the front module.
- **Transducer arm (v0.7, `docs/research/ear-open-fit.md`):** an **"L" or "J" spring arm** attached to the temple arm ~10–15 mm in front of the ear.
  - It drops **in front of** the Ear (open)'s hook junction, then turns back to an ~8 mm pad on the skin just in front of the tragus, pressing inward with ≥1 N.
  - **Clearance:** ≥5 mm from every part of the Ear (open) in nominal fit; ≥8 mm for the vertical run. It must stay clear if the Ear (open) shifts ~3 mm.
  - If bumped, it deflects *away* from the Ear (open). Smooth, low profile against long hair (R16).
- **Balance** (`sim/checks/balance.py`; added load per side, estimated masses):

  | Layout | ~105 mAh cell (7.3 g) | ~150 mAh cell (8.8 g) |
  |---|---|---|
  | Everything in one pod at the hinge (v0.5) | nose 4.9 g · ear 2.4 g | nose 6.1 g · ear 2.7 g |
  | Cell centred mid-arm | nose 3.6 g · ear 3.6 g | nose 4.4 g · ear 4.4 g |
  | **Cell just before the Ear Open hook** | **nose 3.1 g · ear 4.2 g** | **nose 3.7 g · ear 5.1 g** |

  Moving the cell back lets the bigger battery load the nose pads *less* than the small one did at the hinge. **Nose-pad pressure is the usual comfort failure for glasses**, so this is the main lever.
- **Acoustic path rules (v0.5):**
  - The mic ports through the PCB, so use a **thin board (≤0.8 mm)**.
  - Keep the port hole short and wide (~0.6–1.0 mm, larger than the mic's Ø0.325 mm port).
  - No gasket cavity; the clasp opening directly over the hole; thin mesh, never foam.
  - The S1 coupons test real geometries.
- **Wiring along the arm:** battery (2 wires) and transducer (2 wires, a 200 kHz switching waveform). Route the transducer pair away from the mic port and clock/data lines.
- **Skin isolation:** transducer metal and solder joints fully insulated (silicone pad plus sealed housing).
- **Programming:** SWD pogo pads. **Charging:** magnetic pogo connector plus a nightly dock.
- **Mass:** ~7.3–8.8 g per side total `[Low]`, near the ~8 g target and well under the ~15 g "glasses start hurting" level, with the load split between nose and ear as above.

---

## 9. Parts (candidates; nothing ordered)

Stock and price as of 2026-09-30 from the JLC parts API unless noted.

| Function | Part (what it is) | JLC | Status |
|---|---|---|---|
| MCU | **STM32U575CIU6Q**: 160 MHz Cortex-M33 with internal core SMPS and MDF/ADF PDM filters, QFN-48 7×7 mm (v0.12; was STM32L452CEU6) | C5271013 · Extended · 8 · $8.93 | **Chosen** (D5, D11); re-verify MDF plan (A1/A3) |
| Mic | **SPH0641LU4H-1**: digital MEMS mic with ultrasonic mode, 3.5×2.65 mm | C2879853 · Extended · 1,076 · $1.99 | **Chosen** (D13); lifecycle OK |
| Mic backup | **TDK T5838**: PDM mic, ultrasonic mode to ~50 kHz | C7230692 · Extended · 684 · $3.47 | Backup only |
| Crystal | **Q13FC13500004**: 32.768 kHz watch crystal, 3.2×1.5 mm (or X1A0000610002, 2.0×1.2 mm) | C32346 · **Basic** · 467k · $0.17 (C55208 · Extended · 22.5k) | Recommended (D16) |
| H-bridge | 2× complementary N+P MOSFET pair, SOT-563 1.6×1.6 mm: **NTZD3155C** (onsemi, ~2.5 nC) or **DMC2400UV** (Diodes Inc., ~0.5 nC) | C236117 · Ext · 8,788 · $0.17 / C177025 · Ext · 113 (clone C2940616 · 3,836) | B1: on-resistance at 3.0 V gate drive and gate charge |
| Gate pulls | 4× resistors (P-gate pull-ups, N-gate pull-downs) | Basic | Mandatory (D6) |
| Charger | **MCP73831**: single-cell LiPo linear charger, SOT-23-5 | C424093 · Extended · 9,478 · $0.78 | B3: set ~50–75 mA (≤0.5C) |
| LDO | Low-noise 3.0 V linear regulator, low dropout, low idle current | — | B2 |
| Transducer | RC-BC02 / GD02 bone exciter (8 or 12 Ω, to be measured) | not JLC; hand-soldered | E1 |
| Battery | ~105–150 mAh LiPo with protection circuit, long and low (≈4×12×40–45 mm) to lie along the arm | not JLC; hand-soldered | B4 (after E4) |

---

## 10. Phase plan

### Phase 1: DSP simulation (Claude, no hardware) ← **current**
1. **Test corpus:** licensed full-spectrum recordings (≥192 kS/s) of bats and katydids, plus synthetic signals (C1). S1 recordings of the owner's own environment join later.
2. **Front-end model:** digitized mic response + EQ, and DFSDM ÷10 + half-band vs ÷20.
3. **Algorithms:** A, restructured B (and the original STFT-B for a listening reference), and the transient gate. Render WAVs.
4. **Output model:** 3rd-order shaper + 2-level PWM + coil. Checks already in `sim/checks/`; refine after E1.
5. **Cycle counts** for the chosen design (C2); confirm on hardware in S3.
6. **Exit:** algorithm and parameters chosen by the owner.

### Phase 1b: Hearing calibration
- Tone-sweep WAVs (C5) on decent full-range headphones, not the Ear Opens. The result sets the D10 band floor.

### Phase 2: Bench prototype — **revised v0.5; superseded in part by O9 (rev 1 pod board = prototype, no separate test boards)**

| Stage | Build | Answers | Needs Phase 1? |
|---|---|---|---|
| **S1: Ears** | Elecrow mic board → Nucleo DFSDM at 4.0 MHz; stream 200 kS/s audio to the PC over USB (L452 USB device on PA11/PA12), not just RAM bursts | D14 clock plan; **mic-clock duty cycle on a scope**; crystal choice (LSE vs HSE noise floor); mic ultrasonic noise floor (R8); **acoustic coupons** (response vs port geometry); **real recordings of the owner's home and yard**, including self-noise (own speech, chewing, hair on the clasp, frame creaks) | No |
| **S2: Voice** | JLC discrete-bridge test board → transducer; tones and clips from flash | E1 (inductance, resistance); **E2 placement: tragus (primary) vs cheekbone-arch fallback, at ≥1 N, Ear Opens playing**; R1 (loud enough?); **low-level distortion (1 Ω sense resistor + sound card); idle silence (T6); 8–16 kHz noise by ear** | No |
| **S3: Brain** | S1 + S2 joined, chosen algorithm in real time | R3 (CPU, measured with the cycle counter), E4 (current per mode), latency, no clicks (D17) | Yes |
| **S4: Stereo** | Two full units on a rough head mount, battery-powered | **Exit: T1, T2, T3, T6 pass.** Plus **A/B: free-running vs shared clock** (does phase matter for direction? D2) | Yes |

**Bench rules:**
- Listening tests run on battery, never laptop USB. USB streaming is for recording only.
- Use **NUCLEO-U575ZI-Q** (SMPS variant, v0.12). E11: owner listens for whine with the board against her temple in a quiet room.
- Check whether the Nucleo's user LED shares PA5; if so, remove its solder bridge.

**Shopping list v0.5** (to price and verify before ordering; owner approves):
- 2× **NUCLEO-U575ZI-Q**: ST dev board with the new MCU and its SMPS (v0.12; replaces NUCLEO-L452RE). Check stock at order time.
- 2–3× **Elecrow CCB50641P** SPH0641LU4H-1 mic boards: $12.50 each, in stock.
- **One JLC order** (Claude designs it):
  - ~5× discrete-bridge test boards (final MOSFETs, gate pulls, sense resistor, headers);
  - ~5× acoustic coupons: the mic on 0.6/0.8/1.0 mm boards with different port-hole sizes.
- 3× **RC-BC02** (buy from two listings, since the specs disagree) + 1× **Dayton BCE-1**. Longest shipping, so **order first**.
- 2× small protected LiPo cells + 2× linear-regulator modules. A USB breakout cable for S1 streaming.
- Test sources: **HC-SR04** (40 kHz ultrasonic rangefinder) as a T3 emitter; keys.
- Owner's kit: LCR meter (E1), PPK2 power profiler (E4). A cheap USB scope or logic analyzer is needed for the duty-cycle check.
- *Removed from v0.4:* DRV8833 modules (far too slow, D6); custom mic breakouts (Elecrow exists).

**Split:**
- Claude: JLC board designs, all firmware (D15), capture and analysis scripts, test procedures.
- Owner: ordering, wiring, all listening and wear tests.

### Phase 3: PCB
- Schematic checked against JLC stock → owner lays out in KiCad → Claude reviews and runs DRC, generates BOM and placement files → order assembled boards.

### Phase 4: Mechanical and integration
- 3D-printed clasps and drop-arms; iterate on fit. **Exit:** T1–T6 pass while worn.

---
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

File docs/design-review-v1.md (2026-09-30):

# First design review: Stereo Ultrasound, one side

**Date:** 2026-09-30 · **Spec:** v0.13 · **Status:** a complete first design on paper and in simulation. Nothing is bought or built.

This is the whole design in one place: what it is, what the simulations say, what's still a guess, and what you need to decide.
Every number links back to the script or note that produced it. Diagrams are in `docs/diagrams/`; the renders regenerate from the scripts named below.

---

## 1. What one side is

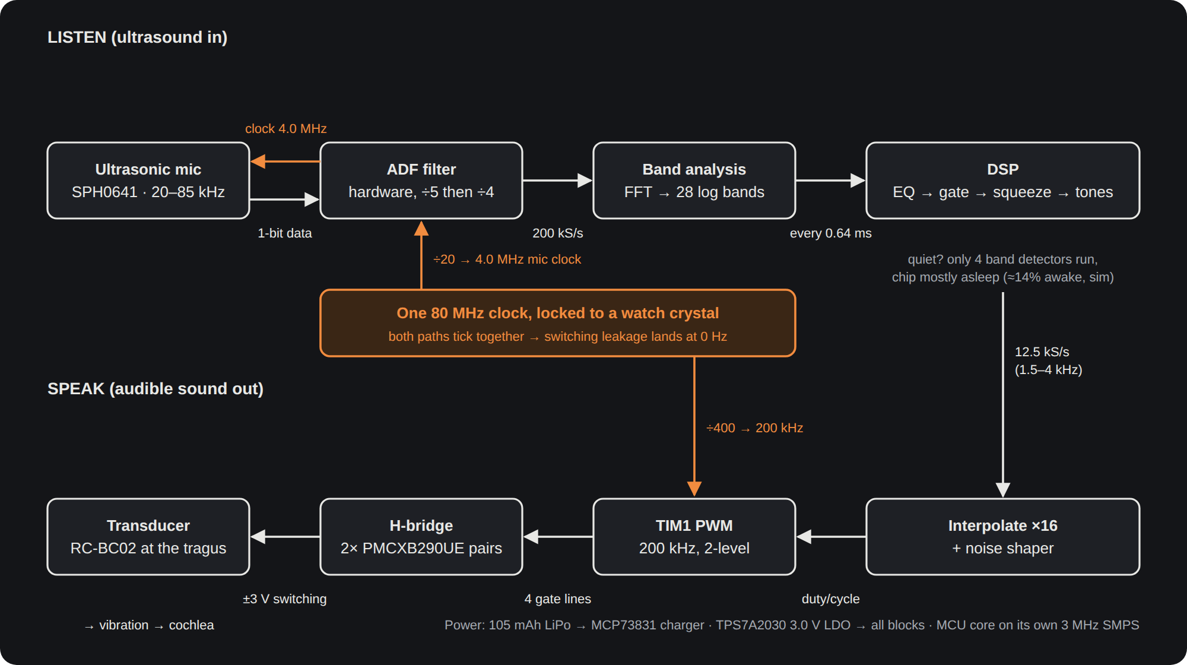
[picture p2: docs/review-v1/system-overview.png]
system


- **Listen:**
  - The **SPH0641LU4H-1** (an ultrasonic-capable digital MEMS microphone, 3.5×2.65 mm) hears 20–85 kHz.
  - The **STM32U575** (a low-power Arm Cortex-M33 microcontroller, 7×7 mm) turns the mic's 1-bit stream into samples in hardware, using its ADF filter.
  - Every 0.64 ms it measures 28 log-spaced bands.
- **Squeeze:**
  - Each band becomes a gentle tone. 20–85 kHz maps logarithmically onto 1.5–4 kHz, so every octave of ultrasound keeps its share of the audible range.
  - Steady whines (chargers, LED drivers) are gated out by default.
  - Only changing sounds come through: bats, insects, keys, rangefinders.
- **Speak:**
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

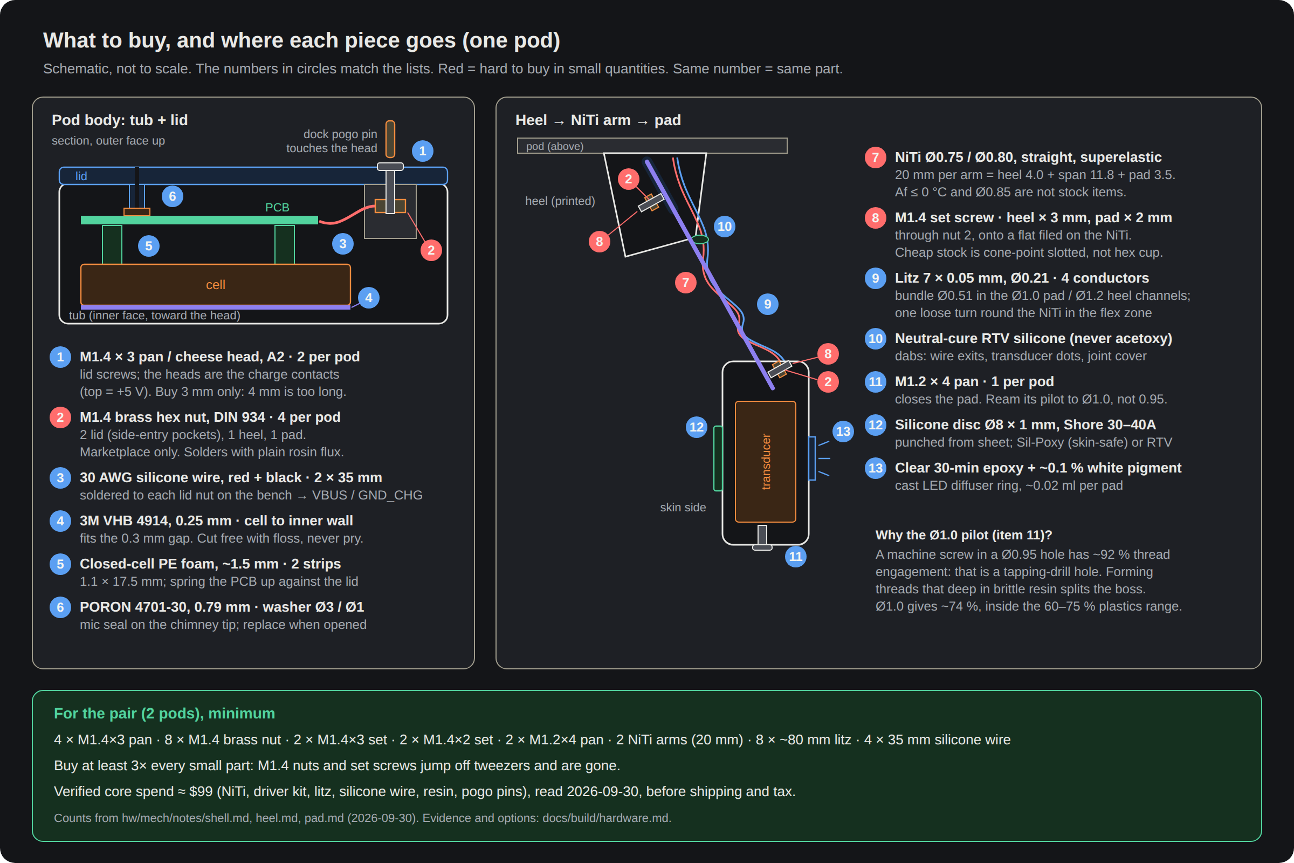
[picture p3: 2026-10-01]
docs/build/hardware-map.png

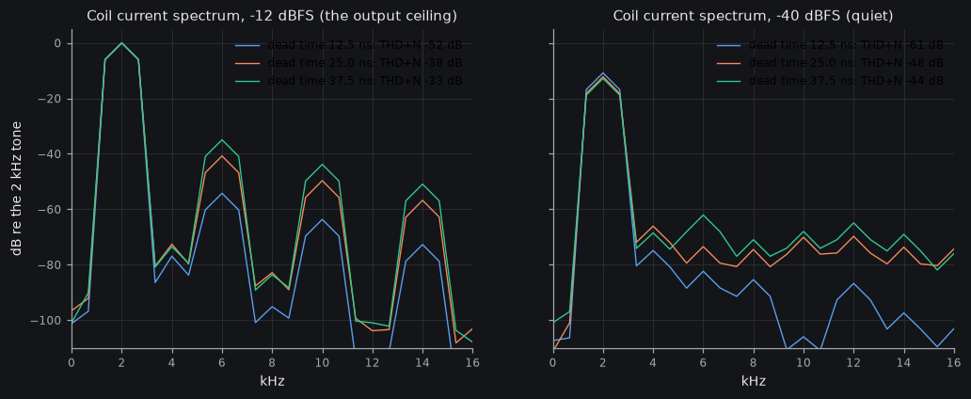
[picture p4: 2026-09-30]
docs/review-v1/bridge_spectrum.png

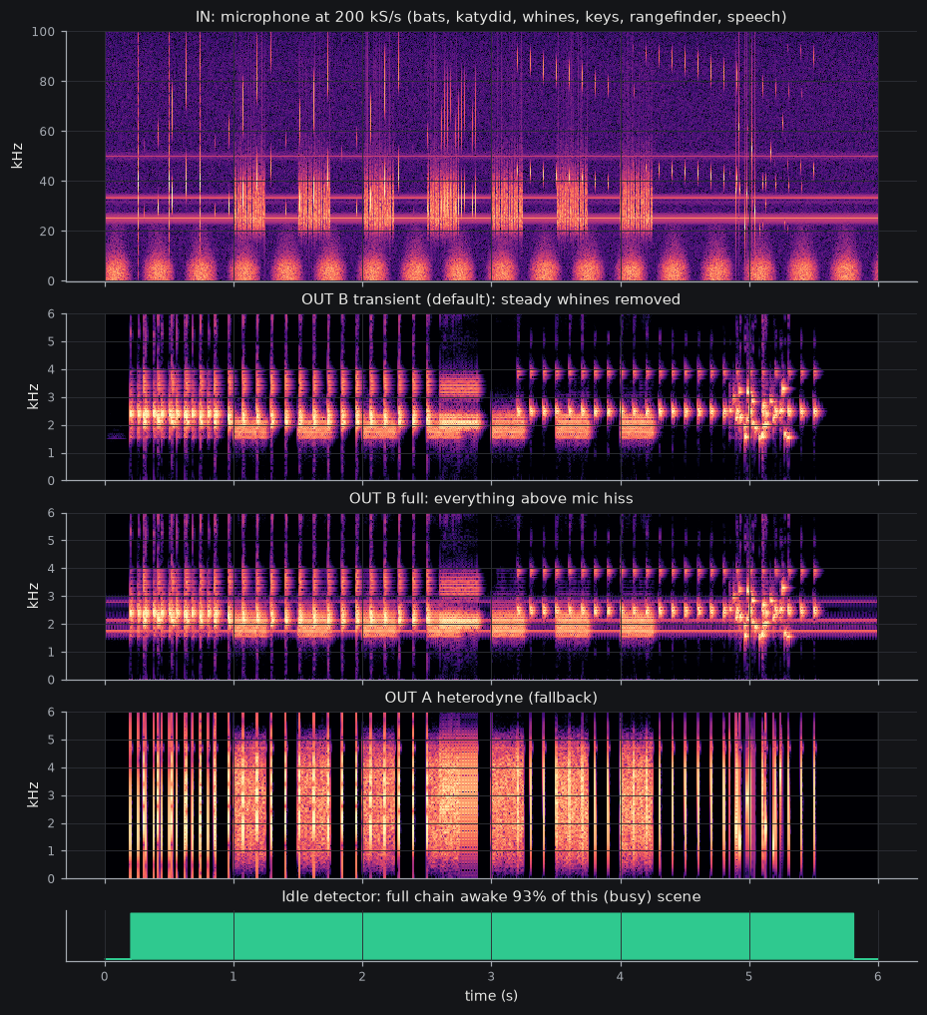
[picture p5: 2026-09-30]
docs/review-v1/spectrograms.png

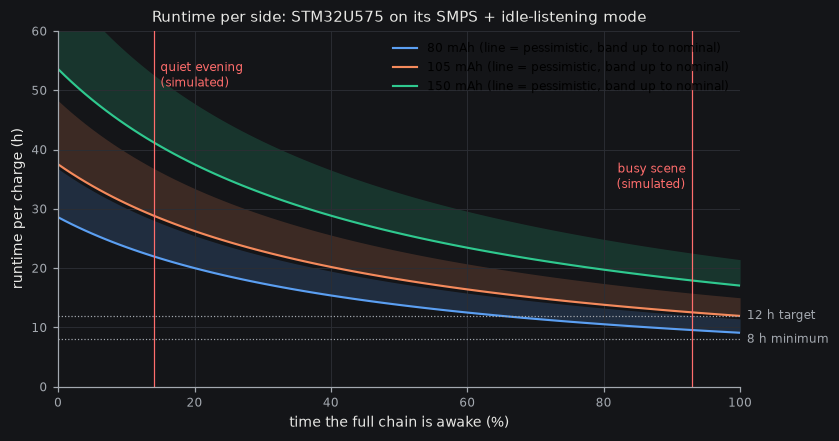
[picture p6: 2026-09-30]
docs/review-v1/runtime.png

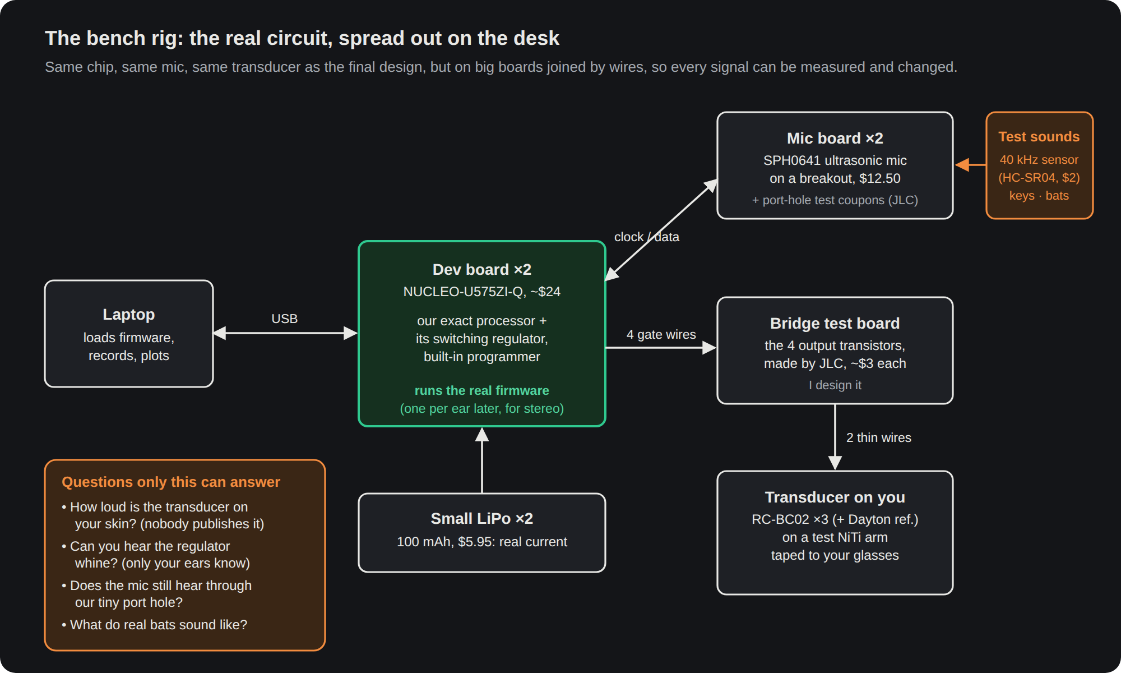
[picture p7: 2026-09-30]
docs/review-v1/bench-rig.png

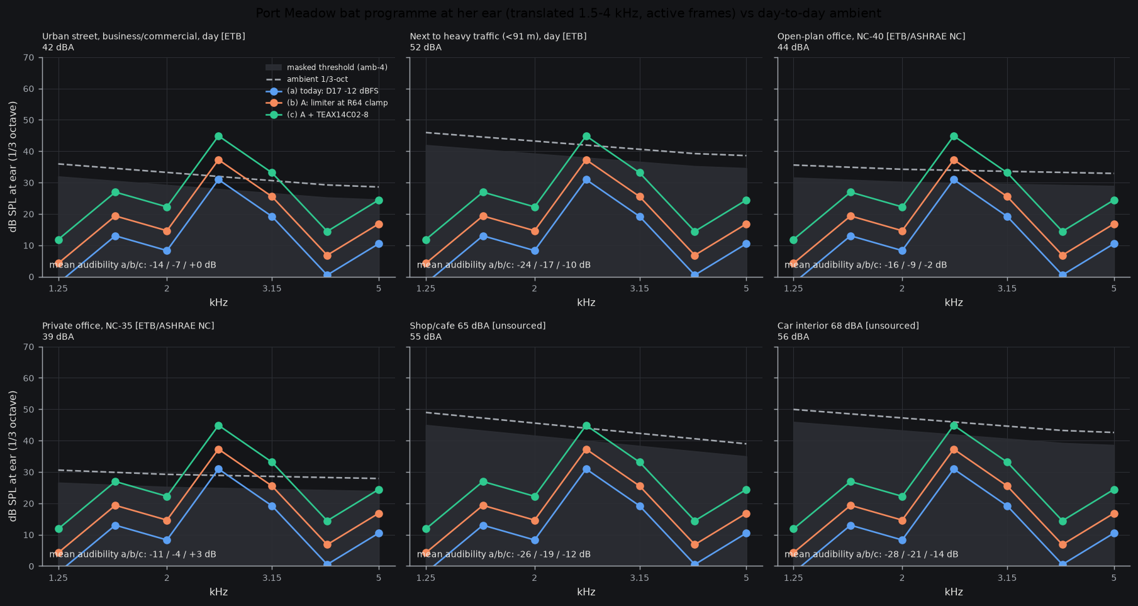
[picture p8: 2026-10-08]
docs/proof/electrical/programme_audibility.png

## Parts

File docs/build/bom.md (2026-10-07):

# Rev 1 BOM (flexible)

Generated by `docs/build/bom.py`; edit that file, not this one. Prices: JLC parts API 2026-10-01 or the sourcing lock 2026-09-30. Board parts are per pod; totals are for **one pair (2 pods)**.

| Block | Part | Ref | Source | Qty/pod | Unit $ | Per pod $ | Status | Note |
|---|---|---|---|---|---|---|---|---|
| MCU | STM32U575CIU6Q | U1 | C5271013 | 1 | 8.9281 | 8.93 | rev C | ONLY 8 IN STOCK at JLC 2026-10-01: buy/reserve early |
| Mic | SPH0641LU4H-1 | U2 | C2879853 | 1 | 1.9915 | 1.99 | rev C | ultrasonic PDM mic |
| Clock | 32.768 kHz crystal 2012 7 pF X1A0000610006 | Y1 | C99009 | 1 | 0.2125 | 0.21 | phase 2 | MZ-2 (ECR-0018); Rev G C32346 $0.1717; JLC API 2026-10-07T11:31Z, Extended, stock 23426 |
| MCU | 2.2 uH inductor DFE201610E | L1 (SMPS) | C337891 | 1 | 0.1366 | 0.14 | rev C |  |
| Bridge | PMCXB290UE N+P pair | Q1, Q2 | C19654206 | 2 | 0.1706 | 0.34 | rev C | footprint must be redrawn (Nexperia Fig. 32) |
| Charger | BQ25180YBGR (NTC/JEITA, power path, I2C) | U3 | C3682423 | 1 | 2.0419 | 2.04 | rev D | replaces MCP73832 |
| Charger | MCP73832-2-OT | U3 (old) | C38066 | 0 | 0.9492 | 0.00 | rev C (removed) | qty 0 after O16 |
| Charger | NTC 10k B3435 0201 NCP03XH103F05RL | RT1 (+ J9 pad for a cell NTC) | C98098 | 1 | 0.0166 | 0.02 | phase 2 | MZ-2 (ECR-0018); Rev G C77131 $0.0199; JLC API 2026-10-07T11:31Z, Extended, stock 175122 |
| Power | TPS7A2030 3.0 V LDO | U4 | C5220164 | 1 | 0.2175 | 0.22 | rev C | input moves to VSYS |
| Protect | PMEG3005EL SOD-882 (reverse docking) | D4 | C282565 | 1 | 0.1150 | 0.12 | phase 2 | MZ-2 (ECR-0018); Rev G 1N5819WS C191023 $0.0137; JLC API 2026-10-07T11:31Z, Extended, stock 43342 |
| Protect | TPD1E10B06DPYR (TI bidirectional ESD, 5.5 V working) at the J3 DOCK_VBUS contact | D5, D6 | C48260 | 2 | 0.0417 | 0.08 | rev G | D5 at J3 DOCK_VBUS replaces D3 (Rev F); D6 at J12 CC (Rev G, O24); JLC API 2026-10-02T23:48Z, 299k stock |
| Protect | PESD5V0S1BL (bridge outputs) | D1, D2 | C84374 | 0 | 0.0334 | 0.00 | rev F removed | Rev F: DNP footprints deleted (OUT-04) |
| USB | TPD2E2U06DRLR (D+/D- ESD) | U6 | C1972959 | 1 | 0.3224 | 0.32 | rev D | USB FS on PA11/PA12 |
| UI | C&K KMT022NGJLHS IP68 switch, 1.6 N, 600k cycles | SW1 | C221707 | 1 | 0.3902 | 0.39 | rev D | replaces KXT321; 2.2k pull-down for >= 1 mA contact current |
| Test | 0.1 ohm 1% 0402 bridge shunt ERJ2BSFR10X | R21 | C409058 | 1 | 0.0732 | 0.07 | phase 2 | MZ-2 (ECR-0018); Rev G 1206 C25334 $0.0055 Basic; JLC API 2026-10-07T11:31Z, Extended, stock 15878; lift it to disconnect the bridge |
| Test | 0 ohm 0402 link (LDO -> 3V0) | R20 | C17168 | 1 | 0.0025 | 0.00 | rev E | lift it to meter or inject the 3V0 rail |
| Passives | 0402/0603 capacitors (Basic) | C* | various | 18 | 0.0120 | 0.22 | rev G | 18 parts (Rev F: C20 removed; C15, C8/C9 itemised below) |
| Passives | Samsung CL05A225KP5NSNC 2.2 uF 10 V X5R 0402 (VDD11; ST DS13737 Rev 10 p.153: rated >= 10 V) | C8, C9 | C107369 | 2 | 0.0129 | 0.03 | rev G | Extended; was 6.3 V C12530 (O24); sourcing-lock 2026-09-30, 878k stock |
| Passives | Murata GRM155R61E475ME15D 4.7 uF 25 V X5R 0402 (charger IN, TI 25 V recommendation) | C15 | C2858031 | 1 | 0.0833 | 0.08 | rev F | Extended; JLC API 2026-10-02T23:50Z, 135k stock |
| Passives | 0402 resistors (Basic) | R* | various | 17 | 0.0030 | 0.05 | rev F | 17 parts (Rev F: R11, R17, R19 removed; R20 and R21 itemised under Test; +R23 100k I_SENSE offset, Phase 2 2026-10-07) |
| Pad board | Everlight 16-213/BHC-AN1P2 blue 0402 LED | LED1 | C131223 | 1 | 0.0291 | 0.03 | O8 | on the tiny pad board |
| Cell | Renata ICP501233PA-02, 175 mAh, PCM | BT1 | Renata distributor quote | 1 | TBD | TBD | O16 | NO public price: not on Digi-Key, Mouser blocks reads, Renata shows no price (2026-10-01); request a quote |
| Cell | Adafruit #1570 105 mAh (bench stand-in) | BT1 alt | Adafruit / Digi-Key | 0 | 5.9500 | 0.00 | option | set qty 1 for early bench tests |
| Transducer | RC-BC02 bone-conduction exciter | XDCR | marketplace | 1 | TBD | TBD | rev C | listing URLs were never saved; price unknown; buy 3+ from two listings |
| Connector | Xinyangze YZT0675 5-pin magnetic TARGET (pod side, magnets built in) | J-dock | LCSC C5126848 | 1 | 2.4000 | 2.40 | O16 | 21.2 x 6.86 x 2.8 mm; 51 in stock 2026-10-01; fits the bigger rev-1 bottom face |
| Connector | Xinyangze YZP0048-20048-05025-01 5-pin magnetic POGO head (cable side; mates the 5-pin YZT0675 target) | dock | LCSC C5126847 | 0.5 | 1.3900 | 0.69 | O16 | one per cable; JLC stock 0 (JLC API 2026-10-07T17:14Z): buy from LCSC/Xinyangze at order time; was wrongly C5126845 = the 4-pin -04025-03 head (DK-01) |
| Connector | Adafruit 5358 + 5412 magnetic pair (bench alt) | J-dock alt | adafruit.com | 0 | 11.4500 | 0.00 | option | $6.50 + $4.95, 21 x 7 face; for early tests |
| Connector | sealed USB-C receptacle (fallback, space reserved) | J-usbc | Same Sky UJ32-C-H-G-MSMT IP68 | 0 | TBD | TBD | option | 6.75 x 8.55 x 2.76; price not retrieved |
| Arm | NiTi superelastic wire 0.75 mm | arm | Kellogg's W-NITI-0.75-SE | 0.1 | 13.4900 | 1.35 | O7b | $13.49 per 5 ft (~76 arms) |
| Arm | Litz 7/44 served, 0.21 mm | 4 conductors | elecify.com | 0.05 | 0.7100 | 0.04 | O11 | $0.71 per 10 m |
| Arm | M1.4 set screw | NiTi lock | Polar Bear / FastenerMart | 2 | 0.1600 | 0.32 | O16 | pack price spread |
| Pad | M1.2 cup screw | cup closure | micro-screw kit | 1 | 0.1000 | 0.10 | O16 | screws OK on the cup |
| Pad | Sugru (or pre-made pad) | contact face | retail | 0.1 | 20.0000 | 2.00 | O16 | ~$20 per pack; tiny amount per pad |
| Housing | Tough/ABS-like resin | tub, lid, adapter, pad | Siraya Tech Blu 1 kg | 0.01 | 32.6500 | 0.33 | O16 | owner already prints resin |

**Priced parts: $22.50 per pod, $45.01 per pair**, plus TBD items: Renata ICP501233PA-02, 175 mAh, PCM, RC-BC02 bone-conduction exciter.

## One-time costs per JLC order (rough estimate, not a quote)

| Item | Low $ | High $ |
|---|---|---|
| JLC 4-layer PCB, 5 boards, 0.8 mm | 15 | 35 |
| JLC assembly setup + stencil (double-sided) | 25 | 60 |
| JLC loading fee per Extended part type (11 types x ~$3, after the 2026-10-01 audit) | 33 | 40 |
| Shipping (+ duties, country-dependent) | 20 | 60 |
| **Total** | **93** | **195** |

Rough rev-1 milestone: one JLC order (5 boards, 2-3 assembled) + one pair's parts. Known parts $45 + one-time $93-195 + TBD items (cells, transducers, connector).

**Risk: the STM32U575CIU6Q had only 8 in stock at JLC on 2026-10-01.**

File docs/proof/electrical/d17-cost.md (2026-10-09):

# D17 loudness options: battery and heat cost on the real programme (2026-10-08)

Answer: **option A as shipped (limiter, ceiling 0.5203) costs ~2.5 mA and still meets 8 h with margin. A with +12 dB drive into the limiter (the variant that gets the cafe/car margin) costs ~12 mA extra: 8 h is MISSED in the continuous-calls and cell-pessimistic cases (4-6 h), met only for sparse scenes. U4/cell heat is a non-issue (+3.6 K worst realistic).** TEAX14C02-8 (7.8 ohm vs 8 ohm exciter) adds only ~2 % current.

**SCOPE (2026-10-08, reconciled: current-models-reconciled.md):** this table is the cost of PLAYING A LOUD PROGRAMME (the 75-dB-per-call translated nature file, calls at the top of the level range, 51 % active frames) or its continuous worst case. It is NOT the cost of wearing the pod outdoors: for that, `sim/perf/port_meadow.py` (real clips, relative levels, gated by the squelch) gives loud12 +3.1 mA over today, not +12. The 14.5-25 mA figures are a cafe/car loud-mode ceiling; use them only for hours spent in that mode.

## Method
- Programme: `sim/out/nature/2_translated_only.wav` (20 s, 51 % of 100 ms frames active), same chain/limiter port as `sim/acoustics/audibility_reconciled.py` (`lahead`, `tp_limit`, ceilings 0.251 / 0.5203). Sample = bridge duty fraction; supply current = mean |x| x 327 mA (full-scale 3.0 V into 8 ohm + FETs + 0.1 ohm, audibility-requirement.md l.7). The H-bridge draws |i| from +3V0 (U4 passes it 1:1 from VSYS).
- The `bats*.npz` vectors are mic PDM input words, not output; no firmware run was made (limiter port used, as in the audibility doc). Scenes: dense = the file as is; continuous = active-frame mean held 100 % of the time (worst); sparse = 18 % active (rail-budget "quiet room", sub-power.md l.176), background from the file's inactive frames.
- Runtime = 130 mAh / (awake base without exciter + exciter + 0.73 mA LED worst). Base from sub-power.md l.173 `full_chain_awake_mA` [5.0, 6.8, 9.8] minus the budget's exciter term [0.4, 1.1, 2.5] = [4.6, 5.7, 7.3] (rail-budget.yaml, sim/checks/power.py). 130 mAh nominal, no derating (as thermal/electrical row 1).
- TEAX: 3.0/(7.8+1.2+0.1) vs 3.0/9.3 = x1.022 current for the same duty. The 208 mA clamp still bounds it; A+12 peaks 166-170 mA, under it. (The Bl gain is acoustic; it is the +7.6 dB, not extra current.)

## Mean transducer current (mA) and runtime (h, low / nom / high base load, LED on)
| Option | peak mA | dense | continuous | sparse 18 % | runtime dense | continuous | sparse |
|---|---|---|---|---|---|---|---|
| today a, -12 dBFS | 82 | 2.4 | 4.2 | 1.1 | 16.9 / 14.8 / 12.5 | 13.6 / 12.2 / 10.6 | 20.2 / 17.2 / 14.2 |
| A, limiter idle, 0.5203 | 145 | 4.9 | 8.7 | 2.3 | 12.7 / 11.5 / 10.1 | 9.3 / 8.6 / **7.8** | 17.0 / 14.9 / 12.6 |
| A, +12 dB into limiter | 166 | 14.5 | 24.9 | 7.5 | **6.5 / 6.2 / 5.8** | **4.3 / 4.1 / 3.9** | 10.2 / 9.4 / 8.4 |
| A + TEAX 7.8 ohm, +12 dB | 170 | 14.9 | 25.5 | 7.6 | **6.4 / 6.1 / 5.7** | **4.2 / 4.1 / 3.9** | 10.0 / 9.3 / 8.3 |

Bold = misses the 8 h spec. Today's dense figure (2.4 mA) sits at the top of the budget's guessed 0.4-2.5 mA exciter band, so that guess is about right for a busy file.

## Heat (thermal README row 8 case (b) redone)
U4 power = (VSYS - 3.0) x I, drop 1.2-1.5 V docked/full cell, theta-JA 166 C/W (README). Old case (b): 2.5 mA -> 3.8 mW -> +0.6 K.
| Option | U4 mW (dense / continuous) | dT U4 K (dense / continuous) |
|---|---|---|
| today | 2.8-3.5 / 5.0-6.3 | 0.5-0.6 / 0.8-1.0 |
| A, limiter idle | 5.9-7.3 / 10.4-13.0 | 1.0-1.2 / 1.7-2.2 |
| A, +12 dB | 17.4-21.8 / 29.9-37.4 | 2.9-3.6 / 5.0-6.2 |
| A + TEAX, +12 dB | 17.8-22.3 / 30.6-38.2 | 3.0-3.7 / 5.1-6.3 |
U4 junction worst ~35 + 3 (shell) + 6.3 = ~45 C vs 125 C limit. Cell: I_rms 34-41 mA x Rint 0.34 ohm = under 1 mW, negligible. Bound (a) (continuous full-clamp sine, +33 K) unchanged.

## Verdict
- Heat: PASS for every option (largest realistic +6.3 K, shell/touch unchanged within 0.1 K).
- Runtime: A (limiter, no extra drive) PASS: >= 7.8 h worst, 10-17 h typical. **A + 12 dB drive FAILS 8 h** unless scenes are sparse (>= 8.3 h at 18 % active); dense/continuous calls give 4-6 h. TEAX does not change this.
- Recommendation (owner decides): ship A (+TEAX if bought, which gives +7.6 dB acoustically for ~2 % current, the cheapest loudness); treat +12 dB drive as a user "loud" mode, or use the slow AGC variant (gain only on quiet calls) which raises mean current far less than blanket +12 dB (not simulated here for current). Needs a 4-6 h runtime caveat if +12 dB is default. OPEN: 130 mAh derating (cold, age) would worsen every row; bench current log (PWR-I12) not done.

## Adversarial check of ledger I-019 (TEAX + 4.4 dB drive = current driver + 12 dB), 2026-10-08
Script `sim/acoustics/teax_drive_check.py` (reuses audibility_reconciled.py chain, limiter, 5-call margins; current as above with TEAX x1.022; scenes dense / continuous / sparse 18 %; runtime nominal base, LED on). Margin = per-call dB over masked threshold, median (worst call).
| Config | pk mA | mean mA dense / cont / sparse | runtime h dense / cont / sparse | Private office | Open office | Heavy traffic | Cafe 67 | Car 68 |
|---|---|---|---|---|---|---|---|---|
| A + 12 (current driver) | 166 | 14.5 / 24.9 / 7.6 | 6.2 / 4.1 / 9.3 | +23.3 (+12.5) | +18.3 (+7.5) | +10.2 (-0.5) | +8.6 (-2.1) | +6.2 (-4.5) |
| A + TEAX +0 | 148 | 5.0 / 8.9 / 2.4 | 11.4 / 8.5 / 14.7 | +24.7 (+8.1) | +19.7 (+3.1) | +11.7 (-4.9) | +10.1 (-6.5) | +7.7 (-8.9) |
| A + TEAX +4.4 | 161 | 7.8 / 13.8 / 3.8 | 9.1 / 6.4 / 12.7 | +27.6 (+12.5) | +22.6 (+7.5) | +14.6 (-0.5) | +13.0 (-2.1) | +10.6 (-4.5) |
| A + TEAX +6 | 164 | 9.1 / 16.0 / 4.5 | 8.4 / 5.8 / 11.9 | +28.5 (+14.1) | +23.5 (+9.1) | +15.4 (+1.1) | +13.8 (-0.5) | +11.4 (-2.9) |
| A + TEAX +12 | 170 | 14.9 / 25.5 / 7.7 | 6.1 / 4.1 / 9.2 | +30.9 (+20.1) | +25.9 (+15.1) | +17.8 (+7.1) | +16.2 (+5.5) | +13.8 (+3.1) |
(Street-day row omitted; it tracks open office +2.)

Verdict: **PARTLY CONFIRMED.** Audibility: TEAX+4.4 has the SAME worst-call margin as current+12 in every scene (identical to 0.1 dB; the limiter ceiling sets the worst call) and a median 4.4 dB better. Current: the ~8 mA / 9 h figure holds for the dense file only (7.8 mA, 9.1 h). Continuous calls give 13.8 mA and 6.4 h (misses 8 h), so "8.5-9 h" is not general. Savings vs current+12: 46 % in mean mA (14.5 -> 7.8), +2.9 h dense.
Drive keeping >= 8 h: dense scenes TEAX +6 (8.4 h; worst-call +1.1 heavy traffic, -0.5 cafe, -2.9 car, best of those that pass); continuous scenes only TEAX +0 (8.5 h nominal, 7.7 h high base; worst-call -4.9 heavy traffic). Sparse: any drive up to +12 passes. No drive meets 8 h continuous AND the +12 worst-call margin; that needs a larger cell or a loud mode (owner decides).

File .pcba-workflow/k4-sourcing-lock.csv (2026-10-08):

reference | function | quantity_per_board | assembly_quantity | required_quantity | order_quantity | manufacturer | requested_mpn | mpn | supplier_part_number | package | package_verified | footprint | pinout_verified | cad_status | model_3d_status | lifecycle | stock_checked_at | stock_quantity | moq | unit_price | currency | assembly_class | line_parts_cost | setup_fee | extended_fee | line_total_cost | datasheet_url | approved_alternates | substitution_approved | substitution_approval_evidence | design_critical | approval_required | status | evidence_url
C13;C19 | 100n decoupling 10V X5R | 2 | 5 | 10 | 10 | Murata Electronics | GRM033R61A104KE15D | GRM033R61A104KE15D | C76934 | 0201 | yes | C_0201_0603Metric | yes | verified | not-required | active | 2026-10-08T12:19Z | 571587 | 1 | 0.0039 | USD | Extended | 0.039 | 0 | 3.0 | 3.039 | https://www.lcsc.com/product-detail/C76934.html | CL03A104KP3NNNC (C49062, Samsung, 0201 100n 10V X5R) | no |  | no | no | PASS | https://www.lcsc.com/product-detail/C76934.html
C15 | 4u7 25V C15 0402 | 1 | 5 | 5 | 5 | Murata Electronics | GRM155R61E475ME15D | GRM155R61E475ME15D | C2858031 | 0402 | yes | C_0402_1005Metric | yes | verified | not-required | active | 2026-10-08T12:19Z | 117272 | 1 | 0.0833 | USD | Extended | 0.4165 | 0 | 3.0 | 3.4165 | https://www.lcsc.com/product-detail/C2858031.html | none qualified: 25V 4u7 X5R 0402 only via Murata GRM155R61E475ME15D (Extended); re-search at freeze | no |  | no | no | PASS | https://www.lcsc.com/product-detail/C2858031.html
C16 | 2u2 10V C9/C16 0201 | 1 | 5 | 5 | 5 | Samsung Electro-Mechanics | CL03A225MP3CRNC | CL03A225MP3CRNC | C318539 | 0201 | yes | C_0201_0603Metric | yes | verified | not-required | active | 2026-10-08T12:19Z | 74441 | 1 | 0.0179 | USD | Extended | 0.0895 | 0 | 3.0 | 3.0895 | https://www.lcsc.com/product-detail/C318539.html | GRM033R61A225ME47D (C319184, Murata 0201 2u2 10V; same 0.39 max per K4 B6) | no |  | yes | yes | PASS | https://www.lcsc.com/product-detail/C318539.html
C17 | 1u 16V C17 0201 | 1 | 5 | 5 | 5 | Samsung Electro-Mechanics | CL03A105MO3NRNC | CL03A105MO3NRNC | C318540 | 0201 | yes | C_0201_0603Metric | yes | verified | not-required | active | 2026-10-08T12:19Z | 18491 | 1 | 0.0183 | USD | Extended | 0.0915 | 0 | 3.0 | 3.0915 | https://www.lcsc.com/product-detail/C318540.html | Murata 0201 1u equivalent C335102 (K4 B6; verify 16V before swap) | no |  | yes | yes | PASS | https://www.lcsc.com/product-detail/C318540.html
C18 | 1u 0402 | 1 | 5 | 5 | 5 | Samsung Electro-Mechanics | CL05A105KA5NQNC | CL05A105KA5NQNC | C52923 | 0402 | yes | C_0402_1005Metric | yes | verified | not-required | active | 2026-10-08T12:19Z | 8284207 | 1 | 0.0107 | USD | Basic | 0.0535 | 0 | 0.0 | 0.0535 | https://www.lcsc.com/product-detail/C52923.html | none needed: Basic, 8.2M stock | no |  | no | no | PASS | https://www.lcsc.com/product-detail/C52923.html
C21 | 10u 0402 C21 | 1 | 5 | 5 | 5 | Samsung Electro-Mechanics | CL05A106MP5NUNC | CL05A106MP5NUNC | C315248 | 0402 | yes | C_0402_1005Metric | yes | verified | not-required | active | 2026-10-08T12:19Z | 384040 | 1 | 0.0298 | USD | Extended | 0.149 | 0 | 3.0 | 3.149 | https://www.lcsc.com/product-detail/C315248.html | GRM155R61A106ME11D (C408132, Murata 10u 10V X5R 0402, 559k stock) | no |  | no | no | PASS | https://www.lcsc.com/product-detail/C315248.html
D4 | D4 Schottky 30V 0.5A SOD-882 | 1 | 5 | 5 | 5 | Nexperia | PMEG3005EL,315 | PMEG3005EL,315 | C282565 | SOD-882 | yes | D_SOD-882 | yes | verified | not-required | active | 2026-10-08T12:19Z | 43332 | 1 | 0.115 | USD | Extended | 0.575 | 0 | 3.0 | 3.575 | https://www.lcsc.com/product-detail/C282565.html | none in SOD-882 in stock (PMEG3005AEL not stocked); fallback RB521S30T1G (C145179, SOD-523, larger: layout change) | no |  | yes | yes | USER_REVIEW | https://www.lcsc.com/product-detail/C282565.html
D5 | D5 TVS 1-ch X1SON-2 | 1 | 5 | 5 | 5 | Texas Instruments | TPD1E10B06DPYR | TPD1E10B06DPYR | C48260 | X1SON-2 | yes | X1SON-2_L1.0-W0.6-P0.65-BI-1 | yes | verified | not-required | active | 2026-10-08T12:19Z | 299308 | 1 | 0.0417 | USD | Extended | 0.2085 | 0 | 3.0 | 3.2085 | https://www.lcsc.com/product-detail/C48260.html | TPD1E10B06DPYR (C2937015, DFN1006-2, same MPN other package listing: footprint differs, verify) | no |  | yes | yes | USER_REVIEW | https://www.lcsc.com/product-detail/C48260.html
J20 | J20 BM28 receptacle 30P 0.35 (M) | 1 | 5 | 5 | 5 | HRS(Hirose) | BM28B0.6-30DS/2-0.35V(51) | BM28B0.6-30DS/2-0.35V(51) | C424571 | BM28 30P 0.35mm | yes | BM28B0.6-30DP_2-0.35V | yes | verified | not-required | active | 2026-10-08T12:19Z | 717 | 1 | 0.2096 | USD | Extended | 1.048 | 0 | 3.0 | 4.048 | https://www.lcsc.com/product-detail/C424571.html | none: Hirose-only mating family; stock 717 is low but covers 5 boards | no |  | yes | yes | USER_REVIEW | https://www.lcsc.com/product-detail/C424571.html
R10;R14 | R10/R14 2k2 | 2 | 5 | 10 | 10 | UNI-ROYAL(Uniroyal Elec) | 0201WMF2201TEE | 0201WMF2201TEE | C473508 | 0201 | yes | R_0201_0603Metric | yes | verified | not-required | active | 2026-10-08T12:19Z | 299733 | 1 | 0.0015 | USD | Extended | 0.015 | 0 | 3.0 | 3.015 | https://www.lcsc.com/product-detail/C473508.html | any 2k2 1% 0201 (R10 carries >=1mA, 2.2mW of 50mW) | no |  | no | no | PASS | https://www.lcsc.com/product-detail/C473508.html
R12;R13 | 100k 0201 | 2 | 5 | 10 | 10 | UNI-ROYAL(Uniroyal Elec) | 0201WMF1003TEE | 0201WMF1003TEE | C270364 | 0201 | yes | R_0201_0603Metric | yes | verified | not-required | active | 2026-10-08T12:19Z | 400705 | 1 | 0.0015 | USD | Extended | 0.015 | 0 | 3.0 | 3.015 | https://www.lcsc.com/product-detail/C270364.html | any 100k 1% 0201 | no |  | no | no | PASS | https://www.lcsc.com/product-detail/C270364.html
R15;R16 | R15/R16 10k | 2 | 5 | 10 | 10 | UNI-ROYAL(Uniroyal Elec) | 0201WMF1002TEE | 0201WMF1002TEE | C473048 | 0201 | yes | R_0201_0603Metric | yes | verified | not-required | active | 2026-10-08T12:19Z | 9807421 | 1 | 0.0014 | USD | Extended | 0.014 | 0 | 3.0 | 3.014 | https://www.lcsc.com/product-detail/C473048.html | any 10k 1% 0201 | no |  | no | no | PASS | https://www.lcsc.com/product-detail/C473048.html
R20 | R20 0 ohm link 0402 | 1 | 5 | 5 | 5 | UNI-ROYAL(Uniroyal Elec) | 0402WGF0000TCE | 0402WGF0000TCE | C17168 | 0402 | yes | R_0402_1005Metric | yes | verified | not-required | active | 2026-10-08T12:19Z | 8655595 | 1 | 0.0025 | USD | Basic | 0.0125 | 0 | 0.0 | 0.0125 | https://www.lcsc.com/product-detail/C17168.html | any 0R 0402 (Basic) | no |  | no | no | PASS | https://www.lcsc.com/product-detail/C17168.html
R30 | R30 33R mic supply filter | 1 | 5 | 5 | 5 | UNI-ROYAL(Uniroyal Elec) | 0402WGF330JTCE | 0402WGF330JTCE | C25105 | 0402 | yes | R_0402_1005Metric | yes | verified | not-required | active | 2026-10-08T12:19Z | 1794255 | 1 | 0.0012 | USD | Basic | 0.006 | 0 | 0.0 | 0.006 | https://www.lcsc.com/product-detail/C25105.html | RC0402FR-0733RL (C138002, Yageo 33R 1% 0402) | no |  | yes | yes | PASS | https://www.lcsc.com/product-detail/C25105.html
R8;R9 | 1M 0201 | 2 | 5 | 10 | 10 | UNI-ROYAL(Uniroyal Elec) | 0201WMF1004TEE | 0201WMF1004TEE | C473482 | 0201 | yes | R_0201_0603Metric | yes | verified | not-required | active | 2026-10-08T12:19Z | 315085 | 1 | 0.0015 | USD | Extended | 0.015 | 0 | 3.0 | 3.015 | https://www.lcsc.com/product-detail/C473482.html | any 1M 1% 0201 | no |  | no | no | PASS | https://www.lcsc.com/product-detail/C473482.html
RT1 | RT1 NTC 10k B3435 | 1 | 5 | 5 | 5 | Murata Electronics | NCP03XH103F05RL | NCP03XH103F05RL | C98098 | 0201 | yes | R_0201_0603Metric | yes | verified | not-required | active | 2026-10-08T12:19Z | 85467 | 1 | 0.0166 | USD | Extended | 0.083 | 0 | 3.0 | 3.083 | https://www.lcsc.com/product-detail/C98098.html | NCU03XH103F60RL (C43469141, 80 stock: too thin) : none practical; keep | no |  | no | no | PASS | https://www.lcsc.com/product-detail/C98098.html
SW1 | SW1 tact switch KMT022 | 1 | 5 | 5 | 5 | C&K | KMT022NGJLHS | KMT022NGJLHS | C221707 | SMD-4P 3.0x2.6 | yes | SW-SMD_4P-L3.0-W2.6-P1.85-LS3.4 | yes | verified | not-required | active | 2026-10-08T12:19Z | 4884 | 1 | 0.3902 | USD | Extended | 1.951 | 0 | 3.0 | 4.951 | https://www.lcsc.com/product-detail/C221707.html | none: stroke 0.15 mm is the design (K4-SW1-PRESS); PTS810 (C221895) is 4.2x3.2, does not fit | no |  | yes | yes | USER_REVIEW | https://www.lcsc.com/product-detail/C221707.html
U2 | U2 PDM mic SPH0641LU4H-1 | 1 | 5 | 5 | 5 | Knowles | SPH0641LU4H-1 | SPH0641LU4H-1 | C2879853 | LGA-5 3.5x2.65 | yes | Knowles_LGA-5_3.5x2.65mm_Port0.65 | yes | verified | not-required | active | 2026-10-08T12:19Z | 1037 | 1 | 1.9915 | USD | Extended | 9.9575 | 0 | 3.0 | 12.9575 | https://www.lcsc.com/product-detail/C2879853.html | none: ICS-43434 (C5656610) is I2S not PDM and LGA-6; not a swap | no |  | yes | yes | USER_REVIEW | https://www.lcsc.com/product-detail/C2879853.html
U3 | U3 BQ25180 charger | 1 | 5 | 5 | 5 | Texas Instruments | BQ25180YBGR | BQ25180YBGR | C3682423 | DSBGA-8 0.4mm | yes | DSBGA-8_L1.6-W0.9-R2-C4-P0.40-BL | yes | verified | not-required | active | 2026-10-08T12:19Z | 4234 | 1 | 2.0419 | USD | Extended | 10.2095 | 0 | 3.0 | 13.2095 | https://www.lcsc.com/product-detail/C3682423.html | none: single-source, no pin-compatible charger | no |  | yes | yes | USER_REVIEW | https://www.lcsc.com/product-detail/C3682423.html
U4 | U4 TPS7A2030 LDO 3.0V | 1 | 5 | 5 | 5 | Texas Instruments | TPS7A2030PDQNR | TPS7A2030PDQNR | C5220164 | X2SON-4 1x1 | yes | X2SON-4_L1.0-W1.0-P0.65-TL-EP | yes | verified | not-required | active | 2026-10-08T12:19Z | 3271 | 1 | 0.2176 | USD | Extended | 1.088 | 0 | 3.0 | 4.088 | https://www.lcsc.com/product-detail/C5220164.html | TLV75530PDQNR (C2860044, same X2SON-4 1x1; 3.0 V; 844 stock; Iq/noise differ: re-run LDO check) | no |  | yes | yes | USER_REVIEW | https://www.lcsc.com/product-detail/C5220164.html
U6 | U6 TPD2E2U06 USB ESD | 1 | 5 | 5 | 5 | Texas Instruments | TPD2E2U06DRLR | TPD2E2U06DRLR | C1972959 | SOT-553-5 | yes | SOT-553-5_L1.6-W1.2-P0.50-LS1.6-TL-1 | yes | verified | not-required | active | 2026-10-08T12:19Z | 7346 | 1 | 0.3224 | USD | Extended | 1.612 | 0 | 3.0 | 4.612 | https://www.lcsc.com/product-detail/C1972959.html | none checked: single-source SOT-553 footprint | no |  | yes | yes | USER_REVIEW | https://www.lcsc.com/product-detail/C1972959.html
C1;C10;C2;C3;C6 | 100n decoupling 10V X5R | 5 | 5 | 25 | 25 | Murata Electronics | GRM033R61A104KE15D | GRM033R61A104KE15D | C76934 | 0201 | yes | C_0201_0603Metric | yes | verified | not-required | active | 2026-10-08T12:19Z | 571587 | 1 | 0.0039 | USD | Extended | 0.0975 | 0 | 0.0 | 0.0975 | https://www.lcsc.com/product-detail/C76934.html | CL03A104KP3NNNC (C49062, Samsung, 0201 100n 10V X5R) | no |  | no | no | PASS | https://www.lcsc.com/product-detail/C76934.html
C11;C12 | 8p2 C0G crystal load | 2 | 5 | 10 | 10 | Murata Electronics | GRM0335C1H8R2BA01D | GRM0335C1H8R2BA01D | C161441 | 0201 | yes | C_0201_0603Metric | yes | verified | not-required | active | 2026-10-08T12:19Z | 23841 | 1 | 0.0043 | USD | Extended | 0.043 | 0 | 3.0 | 3.043 | https://www.lcsc.com/product-detail/C161441.html | none: C0G 8.2p 0201 value fixes CL=7pF; re-pick only with a calculated CL | no |  | no | no | PASS | https://www.lcsc.com/product-detail/C161441.html
C14 | 22u bulk 0603 | 1 | 5 | 5 | 5 | Samsung Electro-Mechanics | CL10A226MQ8NRNC | CL10A226MQ8NRNC | C59461 | 0603 | yes | C_0603_1608Metric | yes | verified | not-required | active | 2026-10-08T12:19Z | 7805483 | 1 | 0.0311 | USD | Basic | 0.1555 | 0 | 0.0 | 0.1555 | https://www.lcsc.com/product-detail/C59461.html | none needed: Basic, 7.8M stock; any 22u 10V X5R 0603 after DC-bias check | no |  | no | no | PASS | https://www.lcsc.com/product-detail/C59461.html
C22 | 10n X7R 25V | 1 | 5 | 5 | 5 | Murata Electronics | GRM033R71E103KE14D | GRM033R71E103KE14D | C85930 | 0201 | yes | C_0201_0603Metric | yes | verified | not-required | active | 2026-10-08T12:19Z | 511797 | 1 | 0.0047 | USD | Extended | 0.0235 | 0 | 3.0 | 3.0235 | https://www.lcsc.com/product-detail/C85930.html | none: non-critical, any 10n X7R 0201 >=16V | no |  | no | no | PASS | https://www.lcsc.com/product-detail/C85930.html
C4;C7 | 10u 0603 SMPS/bulk | 2 | 5 | 10 | 10 | Samsung Electro-Mechanics | CL10A106KP8NNNC | CL10A106KP8NNNC | C19702 | 0603 | yes | C_0603_1608Metric | yes | verified | not-required | active | 2026-10-08T12:19Z | 11872730 | 1 | 0.0304 | USD | Basic | 0.304 | 0 | 0.0 | 0.304 | https://www.lcsc.com/product-detail/C19702.html | none needed: Basic, 11.8M stock | no |  | no | no | PASS | https://www.lcsc.com/product-detail/C19702.html
C5 | 1u 0402 | 1 | 5 | 5 | 5 | Samsung Electro-Mechanics | CL05A105KA5NQNC | CL05A105KA5NQNC | C52923 | 0402 | yes | C_0402_1005Metric | yes | verified | not-required | active | 2026-10-08T12:19Z | 8284207 | 1 | 0.0107 | USD | Basic | 0.0535 | 0 | 0.0 | 0.0535 | https://www.lcsc.com/product-detail/C52923.html | none needed: Basic, 8.2M stock | no |  | no | no | PASS | https://www.lcsc.com/product-detail/C52923.html
C8 | 2u2 10V SMPS loop C8 | 1 | 5 | 5 | 5 | Samsung Electro-Mechanics | CL05A225KP5NSNC | CL05A225KP5NSNC | C107369 | 0402 | yes | C_0402_1005Metric | yes | verified | not-required | active | 2026-10-08T12:19Z | 821016 | 1 | 0.0129 | USD | Extended | 0.0645 | 0 | 3.0 | 3.0645 | https://www.lcsc.com/product-detail/C107369.html | GRM155R61A106ME11D is 10u not 2u2: none qualified; keep Samsung, DC-bias curve per K4 B6 | no |  | no | no | PASS | https://www.lcsc.com/product-detail/C107369.html
C9 | 2u2 10V C9/C16 0201 | 1 | 5 | 5 | 5 | Samsung Electro-Mechanics | CL03A225MP3CRNC | CL03A225MP3CRNC | C318539 | 0201 | yes | C_0201_0603Metric | yes | verified | not-required | active | 2026-10-08T12:19Z | 74441 | 1 | 0.0179 | USD | Extended | 0.0895 | 0 | 0.0 | 0.0895 | https://www.lcsc.com/product-detail/C318539.html | GRM033R61A225ME47D (C319184, Murata 0201 2u2 10V; same 0.39 max per K4 B6) | no |  | yes | yes | PASS | https://www.lcsc.com/product-detail/C318539.html
J21 | J21 BM28 plug 30P 0.35 (P) | 1 | 5 | 5 | 5 | HRS(Hirose) | BM28B0.6-30DP/2-0.35V(51) | BM28B0.6-30DP/2-0.35V(51) | C424570 | BM28 30P 0.35mm | yes | BM28B0.6-30DP_2-0.35V | yes | verified | not-required | active | 2026-10-08T12:19Z | 19972 | 1 | 0.1829 | USD | Extended | 0.9145 | 0 | 3.0 | 3.9145 | https://www.lcsc.com/product-detail/C424570.html | none: Hirose-only mating family (mates only with the C424571 receptacle) | no |  | yes | yes | USER_REVIEW | https://www.lcsc.com/product-detail/C424570.html
L1 | L1 2u2 DFE201610E | 1 | 5 | 5 | 5 | Murata Electronics | DFE201610E-2R2M=P2 | DFE201610E-2R2M=P2 | C337891 | 0806 | yes | L0806 | yes | verified | not-required | active | 2026-10-08T12:19Z | 2537 | 1 | 0.1366 | USD | Extended | 0.683 | 0 | 3.0 | 3.683 | https://www.lcsc.com/product-detail/C337891.html | none: ST DCR/ISAT rule; 2537 stock | no |  | yes | yes | PASS | https://www.lcsc.com/product-detail/C337891.html
Q1;Q2 | Q1/Q2 H-bridge MOSFET | 2 | 5 | 10 | 10 | Nexperia | PMCXB290UEZ | PMCXB290UEZ | C19654206 | DFN1010B-6 | yes | Nexperia_SOT1216_DFN1010B-6 | yes | verified | not-required | active | 2026-10-08T12:19Z | 5000 | 1 | 0.1706 | USD | Extended | 1.706 | 0 | 3.0 | 4.706 | https://www.lcsc.com/product-detail/C19654206.html | none: footprint-specific; covers 5 boards (5000 stock) | no |  | yes | yes | USER_REVIEW | https://www.lcsc.com/product-detail/C19654206.html
R1 | R1 10k 0402 | 1 | 5 | 5 | 5 | UNI-ROYAL(Uniroyal Elec) | 0402WGF1002TCE | 0402WGF1002TCE | C25744 | 0402 | yes | R_0402_1005Metric | yes | verified | not-required | active | 2026-10-08T12:19Z | 19716989 | 1 | 0.0034 | USD | Basic | 0.017 | 0 | 0.0 | 0.017 | https://www.lcsc.com/product-detail/C25744.html | any 10k 1% 0402 (Basic) | no |  | no | no | PASS | https://www.lcsc.com/product-detail/C25744.html
R2 | R2 33R 0201 | 1 | 5 | 5 | 5 | UNI-ROYAL(Uniroyal Elec) | 0201WMF330JTEE | 0201WMF330JTEE | C473457 | 0201 | yes | R_0201_0603Metric | yes | verified | not-required | active | 2026-10-08T12:19Z | 5253 | 1 | 0.0017 | USD | Extended | 0.0085 | 0 | 3.0 | 3.0085 | https://www.lcsc.com/product-detail/C473457.html | any 33R 5% 0201 | no |  | no | no | PASS | https://www.lcsc.com/product-detail/C473457.html
R21 | R21 0.1R sense | 1 | 5 | 5 | 5 | PANASONIC | ERJ2BSFR10X | ERJ2BSFR10X | C409058 | 0402 | yes | R_0402_1005Metric | yes | verified | not-required | active | 2026-10-08T12:19Z | 15678 | 1 | 0.0732 | USD | Extended | 0.366 | 0 | 3.0 | 3.366 | https://www.lcsc.com/product-detail/C409058.html | none qualified; Kelvin pads depend on this 0402; ERJ2BSFR10X only | no |  | yes | yes | PASS | https://www.lcsc.com/product-detail/C409058.html
R22 | R22 1k 0201 | 1 | 5 | 5 | 5 | UNI-ROYAL(Uniroyal Elec) | 0201WMF1001TEE | 0201WMF1001TEE | C270365 | 0201 | yes | R_0201_0603Metric | yes | verified | not-required | active | 2026-10-08T12:19Z | 1646570 | 1 | 0.0013 | USD | Extended | 0.0065 | 0 | 3.0 | 3.0065 | https://www.lcsc.com/product-detail/C270365.html | any 1k 1% 0201 | no |  | no | no | PASS | https://www.lcsc.com/product-detail/C270365.html
R23 | 1M 0201 | 1 | 5 | 5 | 5 | UNI-ROYAL(Uniroyal Elec) | 0201WMF1004TEE | 0201WMF1004TEE | C473482 | 0201 | yes | R_0201_0603Metric | yes | verified | not-required | active | 2026-10-08T12:19Z | 315085 | 1 | 0.0015 | USD | Extended | 0.0075 | 0 | 0.0 | 0.0075 | https://www.lcsc.com/product-detail/C473482.html | any 1M 1% 0201 | no |  | no | no | PASS | https://www.lcsc.com/product-detail/C473482.html
R3;R4;R5;R6 | 100k 0201 | 4 | 5 | 20 | 20 | UNI-ROYAL(Uniroyal Elec) | 0201WMF1003TEE | 0201WMF1003TEE | C270364 | 0201 | yes | R_0201_0603Metric | yes | verified | not-required | active | 2026-10-08T12:19Z | 400705 | 1 | 0.0015 | USD | Extended | 0.03 | 0 | 0.0 | 0.03 | https://www.lcsc.com/product-detail/C270364.html | any 100k 1% 0201 | no |  | no | no | PASS | https://www.lcsc.com/product-detail/C270364.html
U1 | U1 STM32U575CIU6Q | 1 | 5 | 5 | 5 | STMicroelectronics | STM32U575CIU6Q | STM32U575CIU6Q | C5271013 | UFQFPN-48 7x7 | yes | QFN-48-1EP_7x7mm_P0.5mm_EP5.6x5.6mm | yes | verified | not-required | active | 2026-10-08T12:19Z | 14 | 1 | 9.024 | USD | Extended | 45.12 | 0 | 3.0 | 48.12 | https://www.lcsc.com/product-detail/C5271013.html | none: STM32U575CIU6Q only; stock 14 on 2026-10-08, buy-at-freeze (see note) | no |  | yes | yes | USER_REVIEW | https://www.lcsc.com/product-detail/C5271013.html
Y1 | Y1 32.768k 7pF | 1 | 5 | 5 | 5 | Seiko Epson | X1A0000610006 | X1A0000610006 | C99009 | 2.0x1.2mm | yes | Crystal_SMD_2012-2Pin_2.0x1.2mm | yes | verified | not-required | active | 2026-10-08T12:19Z | 22874 | 1 | 0.2125 | USD | Extended | 1.0625 | 0 | 3.0 | 4.0625 | https://www.lcsc.com/product-detail/C99009.html | none: 7pF 2012 crystal; re-pick only with C11/C12 recalculated | no |  | yes | yes | PASS | https://www.lcsc.com/product-detail/C99009.html

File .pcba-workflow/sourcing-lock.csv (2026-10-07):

ref_role | mpn | lcsc | manufacturer | package | library_class | stock | price_usd | queried_utc | datasheet_url | status | notes
U_LDO 3.0V main rail | TPS7A2030PDQNR | C5220164 | Texas Instruments | X2SON-4(1x1) | Extended | 3286 | 0.2175 | 2026-09-30T06:49Z | https://www.ti.com/lit/ds/symlink/tps7a20.pdf | RECOMMENDED | TPS7A20 fixed 3.0 V, P = active discharge. 6.5 uA Iq typ; 7 uVrms; 140 mV max dropout @300 mA (~70 mV @150 mA scaled); ICL 360 mA min; SBVS338H Jul 2024
U_LDO 3.0V main rail | RT9080-30GJ5 | C965900 | Richtek Tech | TSOT-23-5 | Extended | 3329 | 0.161 | 2026-09-30T06:48Z | https://www.lcsc.com/datasheet/lcsc_datasheet_2012102110_Richtek-Tech-RT9080-30GJ5_C965900.pdf | ALTERNATE | RT9080: 2 uA Iq; 42 uVrms; 310 mV typ/530 mV max @600 mA; ILIM 610 mA min; use if bridge peaks exceed ~300 mA; DS9080-07 May 2018
Q_BRIDGE N+P pair x2 | PMCXB290UEZ | C19654206 | Nexperia | DFN1010B-6 | Extended | 5000 | 0.1706 | 2026-09-30T06:48Z | https://assets.nexperia.com/documents/data-sheet/PMCXB290UE.pdf | RECOMMENDED | Nexperia 1.1x1.0 mm. Rds typ @3.0 V (interp.) N 0.34 / P 0.88 ohm; Qg 0.6/0.6 nC @4.5 V (~0.37 each @3 V est.); Vth 0.45-1.0 V. EasyEDA has no footprint for this LCSC no.: draw SOT1216 per datasheet Fig.32 (EasyEDA SOT1216 pads 0.16x0.20 are smaller than Nexperia). SPICE model: manual download (site bot-wall)
Q_BRIDGE N+P pair x2 | DMC2400UV-7 | C177025 | Diodes Incorporated | SOT-563 | Extended | 113 | 0.0764 | 2026-09-30T06:48Z | https://www.diodes.com/assets/Datasheets/DMC2400UV.pdf | ALTERNATE | Genuine Diodes Inc. Lowest Qg (0.5 nC @4.5 V; model 0.24 nC N @3 V). Rds @3.0 V N 0.43 / P 0.85 typ. STOCK ONLY 113. SPICE model in sim/spice/models/DMC2400UV.lib. C2940616 is a TECH PUBLIC clone, not Diodes
Q_BRIDGE N+P pair x2 | NTZD3155CT1G | C236117 | onsemi | SOT-563 | Extended | 8788 | 0.1684 | 2026-09-30T06:48Z | https://wmsc.lcsc.com/wmsc/upload/file/pdf/v2/lcsc/2208241700_onsemi-NTZD3155CT1G_C236117.pdf | ALTERNATE | onsemi. Rds @3.0 V N 0.48 / P 0.58 typ (lowest); Qg 1.5/1.7 nC @4.5 V = ~0.8 mA gate-drive at 200 kHz vs ~0.2-0.3 mA. SPICE model blocked by onsemi site
L_SMPS 2.2uH VLXSMPS-VDD11 | DFE201610E-2R2M=P2 | C337891 | Murata Electronics | 0806 | Extended | 2786 | 0.1366 | 2026-09-30T06:48Z | https://www.lcsc.com/datasheet/lcsc_datasheet_2304140030_Murata-Electronics-DFE201610E-2R2M-P2_C337891.pdf | RECOMMENDED | Murata metal-alloy, shielded, 2.0x1.6x1.0 mm. DCR ~140 mOhm, Isat 2.4 A (ST: L 2.2 uH +-20%, Isat>0.5 A, DCR<200 mOhm, DS13737 Rev 8 5.1.6). Magnetostriction not published
L_SMPS 2.2uH VLXSMPS-VDD11 | TFM201610ALM-2R2MTAA | C695610 | TDK | 0806 | Extended | 401 | 0.3253 | 2026-09-30T06:48Z | https://www.lcsc.com/datasheet/lcsc_datasheet_2009111607_TDK-TFM201610ALM-2R2MTAA_C695610.pdf | ALTERNATE | TDK thin-film metal 2.0x1.6x1.0; DCR 130 typ/146 max mOhm; Isat 2.4/2.6 A. Only 401 stock
C_VDD11 2x2.2uF | CL05A225KP5NSNC | C107369 | Samsung Electro-Mechanics | 0402 | Extended | 877991 | 0.0129 | 2026-09-30T06:48Z | https://datasheet.lcsc.com/lcsc/1811151158_Samsung-Electro-Mechanics-CL05A225KP5NSNC_C107369.pdf | RECOMMENDED | 2x per MCU; ST requires >=10 V rating, ESR<20 mOhm @3 MHz. 0402 10 V X5R (Extended); Basic 0402 C12530 is only 6.3 V
C_VDD11 2x2.2uF | CL10A225KO8NNNC | C23630 | Samsung Electro-Mechanics | 0603 | Basic | 2605124 | 0.0181 | 2026-09-30T06:48Z | https://www.lcsc.com/datasheet/lcsc_datasheet_2304140030_Samsung-Electro-Mechanics-CL10A225KO8NNNC_C23630.pdf | ALTERNATE | Basic option: 0603 16 V X5R (bigger)
C_VDDSMPS 10uF | CL10A106KP8NNNC | C19702 | Samsung Electro-Mechanics | 0603 | Basic | 10519935 | 0.0319 | 2026-09-30T06:48Z | https://www.lcsc.com/datasheet/lcsc_datasheet_2304140030_Samsung-Electro-Mechanics-CL10A106KP8NNNC_C19702.pdf | RECOMMENDED | ST: 10 uF +-20%, >=10 V, ESR<10 mOhm @3 MHz. Basic 0603 10 V X5R
C_VDDSMPS 10uF | CL05A106MP5NUNC | C315248 | Samsung Electro-Mechanics | 0402 | Extended | 524766 | 0.0288 | 2026-09-30T06:48Z | https://wmsc.lcsc.com/wmsc/upload/file/pdf/v2/lcsc/2312201433_Samsung-Electro-Mechanics-CL05A106MP5NUNC_C315248.pdf | ALTERNATE | 0402 10 V X5R, Extended (smaller)
Y_LSE 32.768kHz | Q13FC13500004 | C32346 | Seiko Epson | SMD3215-2P | Basic | 467179 | 0.1717 | 2026-09-30T06:48Z | https://www.lcsc.com/datasheet/lcsc_datasheet_2404180925_Seiko-Epson-Q13FC13500004_C32346.pdf | SUPERSEDED | Epson FC-135 3.2x1.5, CL 12.5 pF, ESR 70 k max, C0 1 pF. gm_crit 2.16 uA/V -> needs LSEDRV=11 (high, Gmcritmax 2.7). Load caps 2x15 pF C0G (C1548); superseded 2026-10-07: not in the MZ-2 schematic (CHK-STOCK)
Y_LSE 32.768kHz | Q13FC13500002 | C48615 | Seiko Epson | SMD3215-2P | Extended | 34217 | 0.1858 | 2026-09-30T06:48Z | https://www.lcsc.com/datasheet/lcsc_datasheet_2304140030_Seiko-Epson-Q13FC13500002_C48615.pdf | ALTERNATE | FC-135 CL 7 pF: gm_crit 0.76 uA/V, runs at medium-high drive with 2.2x margin. Load caps ~2x5.6 pF (bench-trim). Extended
Y_LSE 32.768kHz | X1A0000610002 | C55208 | Seiko Epson | SMD2012-2P | Extended | 22457 | 0.2386 | 2026-09-30T06:49Z | https://www.lcsc.com/datasheet/lcsc_datasheet_1810051107_Seiko-Epson-X1A0000610002_C55208.pdf | REJECTED | FC-12M 2.0x1.2, CL 12.5 pF, ESR 90 k: gm_crit ~2.9 uA/V > U575 Gmcritmax 2.7 at highest drive
C_LSE load 2x15pF C0G | 0402CG150J500NT | C1548 | FH (Guangdong Fenghua Advanced Tech) | 0402 | Basic | 1445152 | 0.0038 | 2026-09-30T06:48Z | https://www.lcsc.com/datasheet/lcsc_datasheet_2304140030_FH--Guangdong-Fenghua-Advanced-Tech-0402CG150J500NT_C1548.pdf | SUPERSEDED | C = 2x(CL - Cstray); CL 12.5 pF, Cstray ~3 pF CS_PARA + ~1.5 pF board -> 16 pF -> 15 pF; superseded 2026-10-07: not in the MZ-2 schematic (CHK-STOCK)
SW_BUTTON | KXT321LHS | C221821 | C&K | SMD,3x2mm | Extended | 6982 | 0.1672 | 2026-09-30T06:48Z | https://www.lcsc.com/datasheet/lcsc_datasheet_2304140030_C-K-KXT321LHS_C221821.pdf | SUPERSEDED | C&K KXT321LHS 3.0x2.0x0.6 mm top-actuated, 1.6 N; superseded 2026-10-07: not in the MZ-2 schematic (CHK-STOCK)
SW_BUTTON | B3U-1000P | C231329 | Omron Electronics | SMD,3x2.5mm | Extended | 143617 | 0.1865 | 2026-09-30T06:48Z | https://omronfs.omron.com/en_US/ecb/products/pdf/en-b3u.pdf | ALTERNATE | Omron B3U-1000P 3.0x2.5x1.6 mm top-actuated, 1.53 N; huge stock
SW_BUTTON | TS-1086E-AC03526 | C720473 | XUNPU | SMD,4.6x1.8mm | Extended | 4171 | 0.0634 | 2026-09-30T06:48Z | https://www.lcsc.com/datasheet/lcsc_datasheet_2008141237_XUNPU-TS-1086E-AC03526_C720473.pdf | ALTERNATE | XUNPU TS-1086E side-actuated 4.6x1.8 mm, 2.6 N; for a push through the pod side wall
D_ESD VBUS pogo | ESD9X5.0ST5G | C87910 | onsemi | SOD-923 | Extended | 43942 | 0.0478 | 2026-09-30T06:48Z | https://www.lcsc.com/datasheet/lcsc_datasheet_1809201305_onsemi-ESD9X5-0ST5G_C87910.pdf | SUPERSEDED | onsemi ESD9X5.0ST5G unidirectional 5 V, SOD-923 1.0x0.6; clamps a reversed supply to ~-0.7 V; superseded 2026-10-07: not in the MZ-2 schematic (CHK-STOCK)
D_REVERSE VBUS series | 1N5819WS | C191023 | Guangdong Hottech | SOD-323 | Basic | 4845364 | 0.0137 | 2026-09-30T06:48Z | https://www.lcsc.com/datasheet/lcsc_datasheet_2409300937_Guangdong-Hottech-1N5819WS_C191023.pdf | ALTERNATE | Only if the magnetic connector is not polarity-keyed: Schottky in series, ~0.3 V drop at 45 mA; Basic. Maker is Hottech (Chinese); check Vf at 50 mA on bench
D_ESD transducer leads x2 | PESD5V0S1BL,315 | C84374 | Nexperia | DFN1006-2 | Extended | 122523 | 0.0334 | 2026-09-30T06:48Z | https://www.lcsc.com/datasheet/lcsc_datasheet_2407241045_Nexperia-PESD5V0S1BL-315_C84374.pdf | SUPERSEDED | Nexperia PESD5V0S1BL bidirectional 5 V, 5 nA leakage, 35 pF (~60 uW CV2f at 200 kHz per lead), DFN1006 1.0x0.6; superseded 2026-10-07: not in the MZ-2 schematic (CHK-STOCK)
D_ESD transducer leads x2 | TPD1E10B06DPYR | C48260 | Texas Instruments | X1-SON-2(0.6x1) | Extended | 286460 | 0.0417 | 2026-09-30T06:48Z | https://www.ti.com/lit/ds/symlink/tpd1e10b06.pdf | RECOMMENDED | TI TPD1E10B06 bidirectional 6 V, 12 pF, 100 nA max leak, 0.6x1.0; promoted 2026-10-07: used as D5/D6 in MZ-2 (CHK-STOCK)
U_CHARGER | MCP73831T-2ACI/OT | C424093 | Microchip Tech | SOT-23-5 | Extended | 9477 | 0.7818 | 2026-09-30T06:49Z | https://www.lcsc.com/datasheet/lcsc_datasheet_1912111437_Microchip-Tech-MCP73831T-2ACI-OT_C424093.pdf | SUPERSEDED | Carried from spec B3; RPROG 22k -> 45 mA (IREG = 1000 V / RPROG, DS20001984H); superseded 2026-10-07: not in the MZ-2 schematic (CHK-STOCK)
R_PROG 22k | 0402WGF2202TCE | C25768 | UNI-ROYAL(Uniroyal Elec) | 0402 | Basic | 849822 | 0.0024 | 2026-09-30T06:49Z | https://www.lcsc.com/datasheet/lcsc_datasheet_2206010100_UNI-ROYAL-Uniroyal-Elec-0402WGF2202TCE_C25768.pdf | SUPERSEDED | MCP73831 45.5 mA = 0.41-0.45C for 100-110 mAh; superseded 2026-10-07: not in the MZ-2 schematic (CHK-STOCK)
R_GATE_PULL 100k x4 | 0402WGF1003TCE | C25741 | UNI-ROYAL(Uniroyal Elec) | 0402 | Basic | 8385624 | 0.0024 | 2026-09-30T06:49Z | https://www.lcsc.com/datasheet/lcsc_datasheet_2206010100_UNI-ROYAL-Uniroyal-Elec-0402WGF1003TCE_C25741.pdf | SUPERSEDED | P-gate pull-ups, N-gate pull-downs (D6). Costs ~60 uA while switching (4 x 30 uA x 50%). Do not go to 1M: max IGSS 0.5-1 uA x 1M = 0.5-1 V, near Vth min; superseded 2026-10-07: not in the MZ-2 schematic (CHK-STOCK)
C_DECOUPLE 100nF | CL05B104KO5NNNC | C1525 | Samsung Electro-Mechanics | 0402 | Basic | 22343254 | 0.0045 | 2026-09-30T06:48Z | https://www.lcsc.com/datasheet/lcsc_datasheet_2304140030_Samsung-Electro-Mechanics-CL05B104KO5NNNC_C1525.pdf | SUPERSEDED | 0402 16 V X7R Basic; superseded 2026-10-07: not in the MZ-2 schematic (CHK-STOCK)
C_DECOUPLE 1uF | CL05A105KA5NQNC | C52923 | Samsung Electro-Mechanics | 0402 | Basic | 5748905 | 0.0099 | 2026-09-30T06:48Z | https://www.lcsc.com/datasheet/lcsc_datasheet_2304140030_Samsung-Electro-Mechanics-CL05A105KA5NQNC_C52923.pdf | RECOMMENDED | 0402 25 V X5R Basic (LDO in/out, VDDA)
C_DECOUPLE 4.7uF | CL05A475MP5NRNC | C23733 | Samsung Electro-Mechanics | 0402 | Basic | 2398766 | 0.0166 | 2026-09-30T06:49Z | https://www.lcsc.com/datasheet/lcsc_datasheet_2304140030_Samsung-Electro-Mechanics-CL05A475MP5NRNC_C23733.pdf | RECOMMENDED | 0402 10 V X5R Basic (MCU VDD bulk)
C_DECOUPLE 10uF | CL05A106MQ5NUNC | C15525 | Samsung Electro-Mechanics | 0402 | Basic | 9181307 | 0.0256 | 2026-09-30T06:49Z | https://www.lcsc.com/datasheet/lcsc_datasheet_2208231630_Samsung-Electro-Mechanics-CL05A106MQ5NUNC_C15525.pdf | SUPERSEDED | 0402 6.3 V X5R Basic; at 3 V bias expect ~40-50% of nominal; superseded 2026-10-07: not in the MZ-2 schematic (CHK-STOCK)
C_BULK 22uF 3.0V rail | CL10A226MQ8NRNC | C59461 | Samsung Electro-Mechanics | 0603 | Basic | 8045146 | 0.0311 | 2026-09-30T06:49Z | https://www.lcsc.com/datasheet/lcsc_datasheet_2304140030_Samsung-Electro-Mechanics-CL10A226MQ8NRNC_C59461.pdf | RECOMMENDED | 0603 6.3 V X5R Basic; covers bridge current peaks above the LDO limit
C_C0G 22pF | 0402CG220J500NT | C1555 | FH (Guangdong Fenghua Advanced Tech) | 0402 | Basic | 1581573 | 0.0042 | 2026-09-30T06:49Z | https://www.lcsc.com/datasheet/lcsc_datasheet_2304140030_FH--Guangdong-Fenghua-Advanced-Tech-0402CG220J500NT_C1555.pdf | SUPERSEDED | Class-1 C0G for filters near the mic (PDM clock/data RC); superseded 2026-10-07: not in the MZ-2 schematic (CHK-STOCK)
C_C0G 100pF | 0402CG101J500NT | C1546 | FH (Guangdong Fenghua Advanced Tech) | 0402 | Basic | 3253806 | 0.0042 | 2026-09-30T06:49Z | https://www.lcsc.com/datasheet/lcsc_datasheet_2304140030_FH--Guangdong-Fenghua-Advanced-Tech-0402CG101J500NT_C1546.pdf | SUPERSEDED | Class-1 C0G, Basic; superseded 2026-10-07: not in the MZ-2 schematic (CHK-STOCK)
R_0201 33R (mic clock series R2) Phase 2 | 0201WMF330JTEE | C473457 | UNI-ROYAL(Uniroyal Elec) | 0201 | Extended | 10383 | 0.0017 | 2026-10-03T04:04Z | https://wmsc.lcsc.com/wmsc/upload/file/pdf/v2/lcsc/2205312145_UNI-ROYAL-Uniroyal-Elec-0201WMF330JTEE_C473457.pdf | RECOMMENDED | 33 ohm 1% 50 mW 25 V 0201. MZ2 R2. Max height 0.26 mm (Uni-Royal chip series sheet, 0201 H 0.23+-0.03). ECR-0018
R_0201 100k (gate pulls R3-R6, VBUS divider R12/R13) Phase 2 | 0201WMF1003TEE | C270364 | UNI-ROYAL(Uniroyal Elec) | 0201 | Extended | 449703 | 0.0015 | 2026-10-03T04:04Z | https://wmsc.lcsc.com/wmsc/upload/file/pdf/v2/lcsc/2205311945_UNI-ROYAL-Uniroyal-Elec-0201WMF1003TEE_C270364.pdf | RECOMMENDED | 100k 1% 50 mW 25 V 0201. MZ2 R3 R4 R5 R6 R12 R13. Max height 0.26 mm. ECR-0018
R_0201 1M (battery-sense divider R8/R9) Phase 2 | 0201WMF1004TEE | C473482 | UNI-ROYAL(Uniroyal Elec) | 0201 | Extended | 331066 | 0.0015 | 2026-10-03T04:04Z | https://wmsc.lcsc.com/wmsc/upload/file/pdf/v2/lcsc/2205312030_UNI-ROYAL-Uniroyal-Elec-0201WMF1004TEE_C473482.pdf | RECOMMENDED | 1M 1% 50 mW 25 V 0201. MZ2 R8 R9. Max height 0.26 mm. ECR-0018
R_0201 2k2 (button pull-down R10, LED series R14) Phase 2 | 0201WMF2201TEE | C473508 | UNI-ROYAL(Uniroyal Elec) | 0201 | Extended | 278179 | 0.0016 | 2026-10-03T04:04Z | https://wmsc.lcsc.com/wmsc/upload/file/pdf/v2/lcsc/2205312145_UNI-ROYAL-Uniroyal-Elec-0201WMF2201TEE_C473508.pdf | RECOMMENDED | 2.2k 1% 50 mW 25 V 0201. MZ2 R10 R14 (R10 carries >= 1 mA = 2.2 mW of 50). Max height 0.26 mm. ECR-0018
R_0201 10k (I2C pull-ups R15/R16) Phase 2 | 0201WMF1002TEE | C473048 | UNI-ROYAL(Uniroyal Elec) | 0201 | Extended | 9974334 | 0.0014 | 2026-10-03T04:04Z | https://wmsc.lcsc.com/wmsc/upload/file/pdf/v2/lcsc/2205312145_UNI-ROYAL-Uniroyal-Elec-0201WMF1002TEE_C473048.pdf | RECOMMENDED | 10k 1% 50 mW 25 V 0201. MZ2 R15 R16. Max height 0.26 mm. ECR-0018
R_0201 5k1 (USB-C CC Rd R18) Phase 2 | 0201WMF5101TEE | C270344 | UNI-ROYAL(Uniroyal Elec) | 0201 | Extended | 75963 | 0.0015 | 2026-10-03T04:04Z | https://wmsc.lcsc.com/wmsc/upload/file/pdf/v2/lcsc/2205311945_UNI-ROYAL-Uniroyal-Elec-0201WMF5101TEE_C270344.pdf | RECOMMENDED | 5.1k 1% 50 mW 25 V 0201. MZ2 R18. Max height 0.26 mm. ECR-0018
R_0201 1k (current-sense filter R22) Phase 2 | 0201WMF1001TEE | C270365 | UNI-ROYAL(Uniroyal Elec) | 0201 | Extended | 1764850 | 0.0013 | 2026-10-03T04:04Z | https://wmsc.lcsc.com/wmsc/upload/file/pdf/v2/lcsc/2205311945_UNI-ROYAL-Uniroyal-Elec-0201WMF1001TEE_C270365.pdf | RECOMMENDED | 1k 1% 50 mW 25 V 0201. MZ2 R22. Max height 0.26 mm. ECR-0018
RT_NTC 10k B3435 0201 (battery temperature RT1) Phase 2 | NCP03XH103F05RL | C98098 | Murata Electronics | 0201 | Extended | 175655 | 0.0166 | 2026-10-03T04:04Z | https://wmsc.lcsc.com/wmsc/upload/file/pdf/v2/lcsc/2401270400_Murata-Electronics-NCP03XH103F05RL_C98098.pdf | RECOMMENDED | 10k +-1% NTC 0201, B 3380 K / 3434 K / 3455 K (LCSC description), 100 mW. MZ2 RT1; same XH family as NCP15XH103 C77131. Max height 0.33 mm (Murata NCP03 0.3+-0.03). ECR-0018
R_SHUNT 0.1R 0402 (bridge low-side current sense R21) Phase 2 | ERJ2BSFR10X | C409058 | PANASONIC | 0402 | Extended | 15928 | 0.0732 | 2026-10-03T04:04Z | https://wmsc.lcsc.com/wmsc/upload/file/pdf/v2/lcsc/2012021738_PANASONIC-ERJ2BSFR10X_C409058.pdf | RECOMMENDED | Panasonic ERJ2BSFR10X 100 mOhm 1% 166 mW, 0 to +300 ppm/degC, 0402. MZ2 R21 (OUT-02). Max height 0.40 mm (ERJ2B T 0.35+-0.05). ECR-0018
C_0201 100n 10V X5R (VDD/VDDA/mic decoupling, ADC hold) Phase 2 | GRM033R61A104KE15D | C76934 | Murata Electronics | 0201 | Extended | 849307 | 0.0039 | 2026-10-03T04:04Z | https://www.lcsc.com/datasheet/lcsc_datasheet_1811081532_Murata-Electronics-GRM033R61A104KE15D_C76934.pdf | RECOMMENDED | 0.1 uF 10 V X5R +-10% 0201. MZ2 C1 C2 C3 C6 C10 C13 C19. Max height 0.33 mm (T 0.3+-0.03). ECR-0018
C_0201 8p2 C0G (LSE crystal load C11/C12) Phase 2 | GRM0335C1H8R2BA01D | C161441 | Murata Electronics | 0201 | Extended | 23861 | 0.0043 | 2026-10-03T04:04Z | https://www.lcsc.com/datasheet/lcsc_datasheet_1811081551_Murata-Electronics-GRM0335C1H8R2BA01D_C161441.pdf | RECOMMENDED | 8.2 pF +-0.1 pF 50 V C0G 0201. MZ2 C11 C12 for the 7 pF crystal (CL = C/2 + ~3 pF). Max height 0.33 mm (T 0.3+-0.03). ECR-0018
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

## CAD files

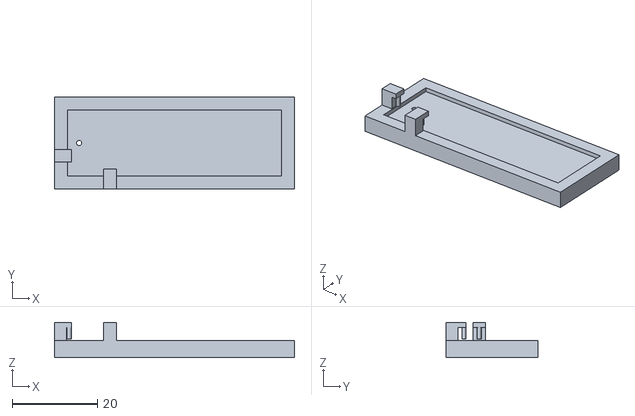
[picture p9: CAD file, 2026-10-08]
hw/mech/out/jigs/jig_lidstack.stl
56.2 x 21.6 x 8.25

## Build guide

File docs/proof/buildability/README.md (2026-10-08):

# Proof: buildability (K4 pod, owner assembles by hand)

Status 2026-10-08. Source: `docs/build/k4-assembly.md` (steps, checks), ECR-0023 add.2 (post + epoxy), `docs/diagrams/k4-assembly/`. Times are estimates [T], not measured: nothing is built yet. Verdict: buildable; **two steps are hard** and each has a cheap fix below.

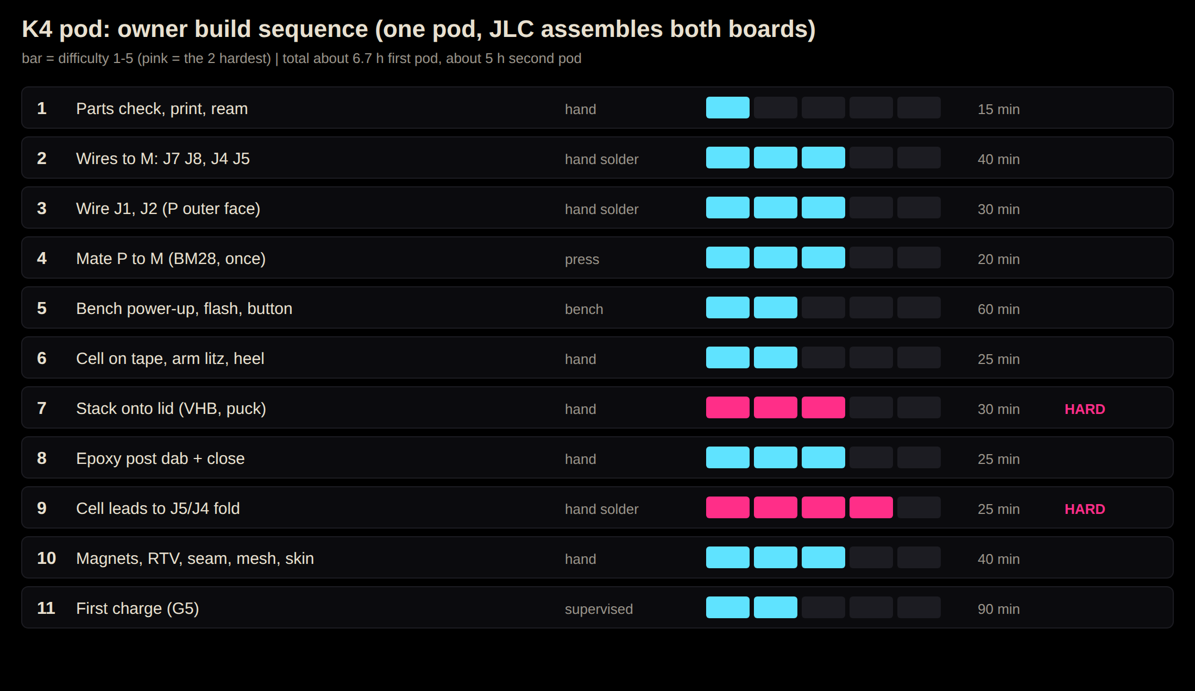
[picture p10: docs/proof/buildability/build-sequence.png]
sequence


## Split of work
- **JLC (reflow, both boards):** every SMD part on M and P, incl. BM28 J20/J21, mic, SW1, U1 QFN. Not JLC: pad J9 stays empty.
- **Owner:** wires to pads (reflow impossible, litz and cell leads), mate, cell, stack, close, charge.

## Build sequence (per pod)

| # | Step | Tools / consumables | Method | Diff | Min |
|---|---|---|---|---|---|
| 1 | Parts check: print tub/lid/pucks, ream mic bore D1.0, pin-gauge bore and M's hole (0.60 pass / 0.70 fail), dry-fit cell, check magnet pitch | FDM/resin printer, 1.0 reamer, pin gauges, calipers, compass | hand | 1 | 15 |
| 2 | Wires to M lid face: J7, J8 (litz), then cell leads J4, J5 (J5 last); leave J9 empty. Gate: no shorts, then 3.5-4.2 V | Iron 300 C, flux, wick, loupe, multimeter, tweezers, 7/44 litz | hand solder | 3 | 40 |
| 3 | Wires to P: J1 (OUT_A) and J2 (OUT_B), both D1.0 pads on P's outer face (file B.Cu, same face as U1/L1; verified in routed_P.kicad_pcb 2026-10-08), reachable before and after the mate; joint under 0.4 mm high | same + Kapton | hand solder | 3 | 30 |
| 4 | Mate P to M: pin-1 dots, photo check, press once at the connector (BM28, 10 cycles, no key) | paint pen, phone camera, flat press tool | press | 3 | 20 |
| 5 | Bench power-up: DFU tack on R1, flash over dock pads, button test, gate G3 | bench supply 50 mA, USB dock head, dfu-util, tack wire | hand solder (tack) | 2 | 60 |
| 6 | Cell on 0.10 tape in tub; pull arm litz through heel exit; M1.4 set screw, RTV dot | transfer tape, hex key, neutral RTV, floss | hand | 2 | 25 |
| 7 | Stack onto lid: VHB ledge, 0.60 pin through bore, 30 N foam press 30 s, button puck by depth gauge, Kapton on U1 | die-cut VHB 4914, depth gauge, puck kit, foam | hand | 3 | 30 |
| 8 | Epoxy post dab (ECR-0023): 10 uL on post, close within 15 min, clamp 1 h | 30-min low-shrink epoxy, syringe, clamp | hand | 3 | 25 (+1 h cure) |
| 9 | Fold cell leads forward and solder to J5/J4 lead stubs; arm wires in 0.9 mm lane | iron, Kapton, tweezers | hand solder | 4 | 25 |
| 10 | Magnets (polarity), RTV at 4 dock windows, seam bead, hex mesh, skin over button | N52 D2.5, neutral RTV, mesh, silicone skin | hand | 3 | 40 |
| 11 | First charge G5: fire-safe bag, tile, thermocouple, USB meter, log every 5 min | bag, tile, logger | supervised | 2 | 90 |

Per-step Check / If-it-fails lines are in `docs/build/k4-assembly.md` sections 2-10; do not skip the gates.

## The hardest steps and an easier alternative

(Correction 2026-10-08, lead check: the first draft put J2 on P's inner face. Both J1 and J2 are on the outer face (B.Cu), so step 3 is a normal small-pad joint, difficulty 3; the 1.0 mm pads sit near L1, so tin the pad and the litz first and keep the iron off L1.)

1. **Step 9, folding cell leads to J5/J4 inside a closed-up tub (diff 4).** Two cell leads next to a live LiPo, tight space.
   - Alt A: **solder cell leads to J4/J5 in step 2 only, and never re-solder** (route the 8 mm leads in a service loop). Needs the cell pre-placed, so check lead length first.
   - Alt B (checked 2026-10-08, public sources): the ICP401230UPR is **already sold with wire leads, not tabs**: contact method "wire, AWG 30", with a safety circuit (PCM) ([manualshelf mirror of the Renata datasheet](https://www.manualshelf.com/manual/renata-sa/icp401230upr/owner-manual-english.html); [Mouser lists Termination Style: Wire Leads](https://www.mouser.com/ProductDetail/Renata/ICP401230UPR?qs=WtvvTbtNXq9vjpvRLNtg1g%3D%3D); Renata page [renata.com](https://www.renata.com/en-us/products/lithium-polymer-batteries/icp401230upr/) returned HTTP 500 today). So no iron touches the cell body: step 9 is a wire-to-pad joint, no welded-tab order needed. **Lead length not found in any public source I could open**; open the Renata spec PDF or ask Renata/Mouser before ordering, and compare with the 8 mm service loop in Alt A. If too short: ask Renata for a custom lead length, or any tab-welding/PCM service (quote needs her login, not done).
   - Do it on a ceramic tile, one lead taped at all times.
2. **Step 7, stack onto lid: the VHB press with the mic pin (diff 3 but misalign = rework).** Pad notches, mic tube and pin must line up at once.
   - Alt A: **printed alignment jig, built 2026-10-08**: `hw/mech/jig_lidstack.py` -> `hw/mech/out/jigs/jig_lidstack.stl` (56.1 x 21.6 x 8.2 mm, 3.5 cm3), render `docs/diagrams/jig-lidstack.png`. Lid sits outer face down in a 0.15-clearance pocket, inner face flush; M drops onto the VHB and two D1.0 pins (hung from bridges outside the lid outline) stop its front (x 18.5) and lower (z -8.075) edges; the 0.60 gauge pin goes up from below through a D1.2 jig hole (mic at x 20.25, z -2.075) into the lid bore and M's 0.65 hole. Not yet printed or fit-tested [T]; print 0.1 layer, check pin gap 0.05 with M.
   - Alt B: ask JLC to supply the VHB die-cut on a **pre-registered carrier** (or laser-cut from a bought sheet by a service).
   - (Runner-up: step 4 BM28 reversed mate; the pin-1 dot rule handles it.)

## Tools (FOSS / cheap)

| Tool | Note |
|---|---|
| Iron with fine tip + flux + wick | any temperature-controlled, about 40-80 EUR |
| Loupe or USB microscope | needed for steps 2, 3, 9; about 50 EUR; viewer software FOSS (guvcview) |
| Hot-air station | alt for step 3 only; optional |
| Multimeter (diode, mA), bench supply 50 mA limit | about 30-60 EUR; supply in lab already |
| Pin gauges 0.60/0.70/1.0, calipers, depth gauge | about 30 EUR |
| 3D printer + build123d/OpenSCAD for jigs | all FOSS (build123d, repo CAD) |
| dfu-util, tools/env.sh | FOSS |
| Fire-safe bag, ceramic tile, thermocouple logger | safety, about 25 EUR |
| Consumables: litz 7/44, VHB 4914, tape, neutral RTV, epoxy, Kapton | per pod, a few EUR |

## Her total time
- Hands-on: about 400 min = **6.7 h for the first pod** (incl. 90 min supervised charge, 60 min bring-up), **about 5 h for the second** (mirror, learning curve gone). Add about 1 h epoxy cure wait and 24 h seam cure, unattended.
- Whole pair: about 12 h over 2-3 sessions. Rework budget: +30 percent.

## Open
- Cell lead exit position and wire gauge are [T] (k4-assembly.md open items).
- Pin 1 orientation of J20/J21 must be confirmed on silkscreen.
- Step 3 Alt B needs an ECR through `tools/plm.py impact`; not done here.

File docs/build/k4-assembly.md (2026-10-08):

# K4 pod: hand assembly guide (right pod, left-pod mirror at the end)

For the owner, by hand. One pod = tub + lid, board M + board P (stacked, joined by the BM28 connector), a 130 mAh cell, 4 arm wires, a button puck and a mic duct. Status: **drawn from the repo as of 2026-10-08, nothing built yet.** Items marked **[T]** are not measured yet. Read "Open items" before you start.

order

Gates (red boxes): do not go on until the test passes. Every step has **Do**, **Check** (multimeter) and **If it fails**.

## 0. What is what

stack

1. **Lid** carries the stack. **Tub** carries the cell. Seam = lid underside.
2. **M** (against the lid): mic, SW1 button, charger U3, regulator U4, dock pads on a tab, wire pads J5 J4 J7 J8 on its lid face.
3. **P** (below M): MCU U1, coil L1, H-bridge Q1/Q2, exciter pads J1 J2.
4. **BM28**: 30-pin 0.35 mm board-to-board connector, 0.6 mm mated gap. M = receptacle J20, P = plug J21.
5. **Dock**: 4 gold half-hole pads on M's tab show through 4 belly windows; 2 magnets in belly pockets. No dock wires.

## 1. Tools and parts

| Tools | Parts (per pod) |
|---|---|
| Soldering iron, fine tip, flux, wick, loupe/microscope | Boards M and P (JLC), parts from `hw/pod/k4/bom_jlc_M.csv`, `bom_jlc_P.csv` |
| Multimeter (diode mode, mA range), thermocouple + logger | Tub, lid, 5-puck kit (1.03 to 1.23 mm), printed and reamed |
| Calipers, depth gauge, pin gauges 0.60/0.70 and a 1.0 pin | Renata ICP401230UPR 130 mAh cell (4.5 x 12.7 x 31 max) |
| Bench supply 3.70 V, 50 mA limit; USB dock head + cable | 4 x 7/44 served litz, 0.21 mm OD (arm wires) |
| Tweezers, spudger, floss, new blades | 3M VHB 4914 0.25 (die-cut), 0.10 transfer tape under the cell |
| Fire-safe LiPo bag, ceramic tile | 2 x N52 magnets D2.5 x 1.0, dock head YZP0048 (C5126845) |
| Neutral-cure RTV (never acetoxy), Kapton tape | Silicone skin 0.1, hydrophobic open mesh [T: product not chosen], M1.4 set screw (heel) |

Cell wire gauge for the 401230 is **[T]**: the repo only states AWG30 for the bigger 501233 cell. Use the cell's own leads, cut to about 8 mm of free length at the pad end.

## 2. Parts check (no electricity)

1. **Do:** print tub, lid, pucks. Ream the lid mic bore to D1.0. Measure and label every puck.
2. **Check:** 1.00 pin enters the bore, 1.03 does not. Mic hole in M: 0.60 pin enters, 0.70 does not.
3. **Do:** dry-fit the cell in the tub. Note where its leads leave (the repo does not know, PWR-I10).
4. **Do:** caliper a dock head sample: magnet pitch (design guess 13.2 mm), polarity with a compass. Fit the pod magnets opposite to the head's.
5. **If it fails:** reprint with compensation; a closed bore gets a fresh ream.

## 3. Solder the joints to M (before P exists on it)

pads

Why now: P sits below M and has no solder window over M. After mating you cannot reach what is inside.

| # | Pad (board, face) | Net | Wire | Notes |
|---|---|---|---|---|
| 1 | J5 (M, lid face) | cell BAT+ | cell lead, red | route length about 8 mm (dims_k4 wire_lengths) |
| 2 | J4 (M, lid face) | GND, cell minus | cell lead, black | same 8 mm |
| 3 | J7 (M, lid face) | LED+ (LED_A via R14) | 7/44 litz #1 | arm wire, cut about 60 mm + 5 mm loop |
| 4 | J8 (M, lid face) | LED- (LED_K, MCU sink) | 7/44 litz #2 | cut about 50 mm + 5 mm loop |
| - | J9 (M) | NTC | **leave empty** | RT1 is on M; charger reads one NTC, never both |

1. **Do:** pre-tin each pad and wire end. Iron at about 300 C, under 3 s per joint; litz strands burn their enamel off in the solder, so check that all 7 strands wet.
2. **Do, order:** J7, J8 first (arm wires). **Cell leads J4 then J5 last** (see gate below). Keep the free cell end taped, never let the two leads touch.
3. **Check, bare M (before the cell leads):** diode mode and ohms: J5-J4, J4-J7, J8-J7, J5-J8 all above 1 kohm or a diode drop (0.3 to 0.8 V), none under 5 ohm (bringup B2).
4. **Check, after the cell leads:** J5 to J4 reads 3.5 to 4.2 V. 0 V means the cell's protection circuit tripped: stop.
5. **If it fails:** a short = bridge under the loupe, wick it off. Lifted pad: stop, use the other board.

## 4. Solder the joints to P

| # | Pad (board, face) | Net | Wire | Notes |
|---|---|---|---|---|
| 6 | J1 (P, outer face, away from M) | OUT_A, exciter | 7/44 litz #3 | cut about 58 mm + 5 mm loop |
| 7 | J2 (P, **inner** face, faces M) | OUT_B, exciter | 7/44 litz #4 | cut about 57 mm + 5 mm loop; **solder it before the mate** |

1. **Do:** solder J2 first (inner face, hardest), then J1. Dress both wires flat and out toward the board edge. Keep each joint under about 0.4 mm of height (gap is 0.6 mm and M parts hang in it).
2. **Check:** J1 to J2 above 1 kohm (a bridge and its 8 to 12 ohm exciter will read low only once the exciter is on). Neighbour pair J2-J8 is across boards: check after the mate.
3. **If it fails:** if J2's wire will not lie flat under 0.6 mm, stop and read Open items 1.

## 5. Mate P to M

**BM28 warning (Hirose catalogue, per coordinator b18670c):** no polarity key, so it can mate 180 degrees reversed. Rated for only **10 mating cycles**. **Mate it once**, after testing each board alone where you can (M alone: step 3 checks; P alone: loupe + shorts only, it has no supply pad of its own).

1. **Do (marks):** before anything else, put a pin-1 dot (paint pen or marker) on M next to J20 pin 1 and on P next to J21 pin 1, on the board edge where you can see it from the side. Pin n mates pin n. Which end is pin 1 comes from the KiCad footprint, so confirm it on the board silkscreen or in KiCad first **[T]**.
2. **Do (photo check before pressing):** lay P over M with the dots on the same side, 2 mm apart, not touching. Take a photo from above and one from the side. Both dots must be on the same end. Wrong = turn P around. Only then press.
3. **Do:** press with a flat tool at the connector only. Soft stop; mated gap about 0.6 mm. Do not unplug and re-mate for casual probing.
4. **Check:** loupe along the gap: even all round. Then meter J5-J4 again (cell connected, board now live): 3.5 to 4.2 V, no warm part by touch after 30 s.
5. **Check:** TP4 (+3V0) to TP5 (GND) on M: 0 V or about 3.0 V, never a short (above 1 kohm unpowered).
6. **Gate G1/G2:** no 5 V on the dock pads until the cell side is quiet.
7. **If it fails:** unplug, re-seat (counts as a cycle); a part getting warm = unplug the cell lead at J5 and look for a short.

## 6. Bench power-up and bring-up (stack on the mat, no lid)

Follow `docs/build/bringup.md` stages B to E. Short version for this pod:

1. **Flash (D1):** P's R1 pad (outer face) is the DFU tack point: tack it to +3V0, 5 V at a 100 mA limit on M's dock pads J3/J4, D+/D- on J10/J11, power-cycle, `dfu-util`, remove the tack.
2. **SWD is gone:** P's SWD pads TP1 to TP3 face the gap. Firmware goes in over the dock only. Write and protect the boot stub (G3).
3. **Button (E3):** press SW1 directly; LED lights on J7/J8 (test with any LED).
4. **Gate G3:** no lid bond until the boot stub passes ROM DFU and a full re-flash (bringup D4).

## 7. Cell into the tub

1. **Do:** 0.10 transfer tape on the cavity floor, press the cell on (front end at pod x 31.0, 4.5 thick max). Wire gap behind the stack is 0.8 mm; the cell's own 0.2 mm lid clearance is for swell.
2. **Do:** dock tab: set the M tab onto the belly windows later with the stack (step 8). Dummy-check it now: the 4 pads must sit behind the 4 windows (1.3 x 1.2).
3. **Do:** pull the arm litz (4 wires) out of the heel channel exit (pod x 66.2, z -5.5) with the tub empty, set screw M1.4 in the heel, RTV dot at the exit. See `hw/mech/notes/heel.md`.
4. **Check:** cell flat, heel exit not covered, no wire pinched.

routes

## 8. Stack onto the lid

lid

1. **Do:** die-cut VHB onto the lid ledge tip only (ledge 0.70 high, 0.5 wide, with notches round J5/J7/J8 and the mic tube). Mic: slide a 0.60 pin gauge through the lid bore, VHB hole and M's hole; press M down; pull the pin last.
2. **Do:** press through a foam pad over P (about 30 N), hold 30 s. M's pads stay in the ledge notches.
3. **Do (button):** depth-gauge from the skin recess floor to SW1's top, puck length = depth - 0.07, pick from the kit (1.03 to 1.23). Skin on unbonded, press 10 times: one click each, none at rest. Then bond the skin.
4. **Do (peel layer):** stick a 3 x 3 mm square of Kapton tape on U1's top (the big QFN on P's outer face, centre of the BM28 line). The post dab will bond to this, never to the chip.
5. **Check:** J5-J4 still 3.5 to 4.2 V; mic hole clear to a 0.60 pin.
6. **If it fails:** puck too long = click at rest, take the next shorter; peel VHB (warm 60 to 80 C, floss).

## 9. Close and seal (O12, IPX4 minimum, IPX5 preferred)

0. **Do (gap-filling post, ECR-0023 add.2, final build only):** the tub post is printed 0.59 short of U1 on purpose (air gap 0.05 to 1.125 mm). Mix about 10 uL (a 3 mm blob) of 30-minute low-shrink two-part epoxy and put it on the post top; keep it off the cell side. Close the pod (step 9.1 to 9.4) within 15 min; the dab squeezes out to the real gap against the Kapton. Clamp the closed pod 1 h flat, no press on SW1 for 24 h. Check: epoxy skirt visible only at the post, nothing on the BM28. Rework: warm the pod to 60 to 80 C and the dab lets go from the Kapton, not from U1. Dry-close builds get no dab.

post

1. **Do:** fold the cell leads forward to the cell front lead and solder them (cell + to J5's lead, cell - to J4's). Arm wires run flat under the cell in the 0.9 mm lane (z -8.8), then up to the heel exit. Kapton tape across.
2. **Do:** dry-close first with tape round the seam (test build). Look through the seam that nothing is pinched.
3. **Do:** 2 magnets into the belly pockets (opposite to the head), plus one RTV dab at each of the 4 dock windows. Neutral-cure RTV only (acetoxy corrodes copper).
4. **Do (final build):** RTV bead in the tongue/groove and at each corner, bond the seam, hex mesh in the seat, skin over the button last.
5. **Check:** cell + to J5 and the arm wires still read as in steps 3 and 4. Docs: `docs/research/sealing-and-service.md`. Test plan: IPX4 spray 5 min with indicator tape inside.

## 10. First charge (gate G5, supervised)

charge

1. **Do:** pod in the fire-safe bag, bag on the ceramic tile, thermocouple taped to the cell through the open seam. Lid taped, not bonded yet.
2. **Do:** dock head on, USB source with a USB meter in line. Defaults: charge 10 mA, 4.20 V end; cell limit 65 mA normal (130 mA max).
3. **Check, every 5 min:** write time, cell temp, VBAT, USB current, LED. Pass: cell 45 C or less, ends at 4.20 V.
4. **Stop:** above 45 C, any swelling, hiss or sweet smell. Unplug, close the bag, take it outside.
5. **Then:** firmware charger plan (E6): TS_HOT 45 C. Only after it passes do you bond the seam and wear it.

## 11. How to reopen or rework

Same cut-and-rebond pattern as `docs/build/reopen.md`. K4 differences:

1. Score the rebate (0.1 deep x 0.4 high, with a 0.1 inward ridge so the wall stays 0.6): 2 to 3 light passes, 0.3 mm total depth at most.
2. Open from the rear straight run with a spudger. The stack hangs on the lid and lifts with it on the wires (slack: 5 mm loops).
3. **Cell swap:** desolder J5/J4, peel the 0.10 tape (floss), new cell on new tape. **Arm swap:** desolder J7 J8 (M) and J1 J2 (P), release the heel set screw.
4. **P off M:** costs one of the 10 BM28 cycles; needs the lid off the tub first, then pull P from the BM28 (it is not glued). Re-solder J2 before re-mating.
5. **Always replace:** seam adhesive, cell tape; **sometimes:** lid (stack VHB is destroyed on a board swap, 60 to 80 C and floss).

## 12. Left pod (mirror)

mirror

1. Same boards. Print the mirrored tub and lid.
2. Mic, SW1, BM28 are on the board centre line, so nothing moves; pad heights flip (J5 J4 J7 J8 J1 J2 trade up/down).
3. Arm wire order at the heel changes; the repo's left-pod wire route is not valid for K4. Redo the dry fit (step 7).
4. Dock pad order runs along x and stays the same; the magnets and head key identically.

## Open items (blunt)

1. **J2 sits on P's inner face** (placement_P.yaml, `J2: [1.68, 3.58, 0, F]`), inside the 0.6 mm gap, where M parts reach 0.5 to 0.7 mm. The gap side already fails the height check (C16 -0.10, C17/C9 -0.05). A wire may not fit. Needs a layout call before ordering.
2. **Pads J5 J4 J7 J8 are on M's lid face (B), so P does not cover them** in the current layout (reg-board and k4_heights). The "solder before mating" order is safe anyway; the safer option is **cell leads last** (after step 6 on a 3.70 V / 50 mA bench supply at J5/J4, bringup C1). Recommended: use the cell-last order. Owner decides.
3. **Arm wire route under the cell is a placeholder** (dims_k4 wire_routes; reg-pod-body K4 note: 0.111 / 0.140 mm3 clash with tub and cell). Dry-fit first.
4. **Not measured:** cell lead gauge, lead exit position, dock head magnet pitch/polarity, mesh product, RTV product, mated BM28 height 0.6 [T].

<!-- NOTES (hidden; sources, read 2026-10-08)
stack/layers: hw/mech/dims_k4.py (LID_STANDOFF 0.70, LEDGE_W 0.5, F_GAP, STACK_T 3.2, STACK_L from routed boards 15.5, PCB_T 0.8, TAPE 0.10, CELL_SPEC, CELL_X0 31.0, PUCK_KIT, DUCT, wire_routes/wire_lengths 8.1/7.8/58.4/57.3/60.5/50.0).
ECR-0020 (BM28 split, J20/J21, pin map, P/M parts), ECR-0021 (dock pads, magnets D2.5x1.0, windows 1.3x1.2), ECR-0022 (ledge, notches J3 J5 J9 RT1 TP5, C21 0402, gap-side fail).
Pad faces: hw/pod/k4/placement_M.yaml (J5 J4 J7 J8 J9 B), placement_P.yaml (J1 B, J2 F). Face meaning: sim/checks/k4_heights.py header (M file-B = LID face, P file-B = OUTER).
LED O8: docs/spec.md O8 (R14 + J7/J8 on PB7); reg-arm.md (LED_A J7, LED_K J8, 4 x 7/44 litz 0.21 OD).
Seal: docs/research/sealing-and-service.md (neutral RTV, no acetoxy, IPX4/5, indicator tape); physical.md assembly order + DBG-16 gate.
Bring-up gates/steps: docs/build/bringup.md (G1-G5, B2, C1, D1, D4, E3, E6: ICHG 10 mA, VBATREG 4.20, TS_HOT 45 C, thermocouple).
Cell: docs/research/V2-cells.yaml ICP401230UPR (charge 65/130 mA, 4.2 V, PCM, 3.5 g).
Reopen: docs/build/reopen.md pattern; dims_k4 REBATE 0.1x0.4; shell_k4.py seam_ridge; physical.md Service (60-80 C, floss).
Left pod: physical.md coordinate frame mirror note; reg-pod-body.md line 195 (left pod, K4 wire route placeholder).
Assembly order cross-check: hw/mech/shell_k4.py docstring (steps 1-6).
Diagrams: docs/diagrams/k4-assembly/make_k4_assembly.py.
-->

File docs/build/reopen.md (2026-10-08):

# Reopening a bonded pod (RPB-12, O19 service)

For the owner, by hand. Applies to cell swap, arm swap, board swap. Source: `docs/system/physical.md` Service; geometry `hw/mech/shell_r2.py` (seam_rebate, 2026-10-07). Each reopening uses one cut-and-rebond cycle; the cycle count the seam survives is unproven until the spray coupon is opened and rebonded 3x (issue 14).

## Where the cut line is

| Run | Marker | Size |
|---|---|---|
| Straight runs at y 12.1 (top, rear, bottom, front above the step) | rebate in the tub, round the outside | 0.2 deep x 0.4 high |
| Belly step (z -8.9, x < 55.0, below the lid face) | witness groove on the outer face, just under the step | 0.1 deep x 0.4 high |

The two meet at the corner of the step. Cut along the groove/rebate: the lid skirt is above it, the tub below. The tongue (0.35 x 0.5) sits inside the joint, so do not go deeper than ~0.5 mm.

## Tools

- Fine razor blade or hobby knife (new blade), thin spudger (plastic), floss, tweezers
- Hot-air gun at 60-80 C only for a board swap
- Soldering iron, flux, wick; isopropyl alcohol; the seam adhesive used at assembly (same product, physical.md step 12)

## Steps

1. **Power off, undock, unplug nothing yet.** Discharge-safe: cell stays connected until step 6.
2. **Score the line.** Run the blade point along the rebate/groove, 2-3 light passes, 0.3 mm deep at most. Do not twist; the wall behind the rebate is 0.6 mm.
3. **Open the seam.** Start at the rear straight run (the lid hinges about the rear seam edge). Slide the spudger into the scored line, work forward a few mm at a time. Never pry on the belly: the dock window and the magnet target are tub.
4. **Lift the lid and the hanging board together,** hinged about the rear edge, no more than 180 degrees. The wires have the slack for this (arm 2.65/3.04 mm, dock 0 mm worst, so keep the dock loops).
5. **Cell:** desolder J5/J4 (J9 if the NTC is fitted). Free the cell with floss through the VHB; never pry a pouch. New cell on new VHB.
6. **Arm:** desolder J1/J2/J7/J8 on B, release the M1.4 heel set screw, draw the bundle out, new arm per assembly steps 2-5.
7. **Board only:** warm to 60-80 C and saw the board VHB from the rear with floss. Accept a lid reprint (about 1 g resin).
8. **Clean the joint.** Remove old adhesive with the blade and alcohol; the tongue and groove faces must be bare resin. Re-measure: the lid must seat on the tongue dry.
9. **Rebond** per physical.md step 12, then check the seam again (spray test when available).

## What to replace

| Part | Always | Sometimes |
|---|---|---|
| Seam adhesive | yes | |
| Cell VHB (0.25) | when the cell comes out | |
| Board VHB (4914) and its D1.0 mic-duct hole | board swap | |
| Lid | | board swap (reprint) |
| Cell | | cell swap only |

## Fail lines

- Blade slips into the tub wall: stop, check wall thickness before the next pass (min 0.6).
- Belly dock wires tense when the lid lifts: stop, re-cut the wires 2 mm long as a loop (`hw/mech/dock_route.py`).
- Lid will not seat after cleaning: sand lightly the lid groove land only, not the tongue.

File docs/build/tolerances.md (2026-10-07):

# Rev-1 tolerance review (2026-10-01)

Every fit and clearance in the current design. Values come from the CAD checks (`shell_r1.py`,
`heel.py` checks.json, `pad.py` checks.json) or the dimensions in those files. The resin rules come from
`docs/build/hardware.md`: holes under ~0.8 mm may close; recesses under 0.4 mm may fuse; self-tapping
pilots ~85 % of nominal.
**Print critical holes undersize and drill them to size after curing.**

Legend: ✅ fine · ⚠️ tight, with a note on what to do · ❌ not yet designed.

## Housing (tub + lid, bonded, no screws)
| Fit | Value | Verdict |
|---|---|---|
| Lid locating lip ↔ tub opening | 0.15 mm per side; 0.5 mm lip, 0.8 mm deep | ✅ Tape-test, then bond. A 0.15–0.3 mm bond line suits MS-polymer and neutral RTV. |
| Seam cut-guide groove | 0.4 × 0.4 mm | ⚠️ At the 0.4 mm resin minimum. Open it with a blade if it prints shallow. |
| Cell (175 mAh) ↔ tub | 0.3 mm tape gap; 0.07 mm at the strut-relief corner fill | ⚠️ The pouch's rounded corner gives more real clearance. Dry-fit the cell first. |
| Board ↔ cavity walls | 0.3 mm front, top and bottom; 2.1 mm behind the rear edge (board grown to 34 mm, 2026-10-01) | ✅ The rear 2.1 mm is the arm wires' path from the heel channel up to the J pads: 4 litz in ≤ 1.1 mm shrink tube fits. |
| Board retention | Two lid ribs press the outer-face clamp bands (0.05 mm gap when seated); 1.5 mm closed-cell foam strips on the cell, compressed to 1.4 mm, push the board up | ✅ Added 2026-10-01. Keep the 0.6 mm top/bottom edge bands free of parts on both faces (the rough layout does). |
| Switch plunger head ↔ lid bore | 0.15 mm per side (Ø2.9 in Ø3.2) | ✅ |
| Plunger stem ↔ switch | KMT0 travel is only 0.15 ± 0.1 mm | ⚠️ Stack tolerance (board ±0.1, lid ±0.1) can pre-press or miss the switch. Print the stem 0.2 mm long and sand it to a light touch. The silicone skin over it is the spring. |
| Dock target ↔ floor window | +0.1 mm per side (21.4 × 7.06 window for a 21.2 × 6.86 part) | ✅ Glued in, back potted. |
| Mic port | Ø1.0 through the lid | ✅ Above the 0.8 mm limit. Drill it to Ø1.0 after printing. |
| Frame adapter dovetail | 0.15 mm per side | ✅ Resin. On FDM use 0.25. |
| Adapter snap tab | ~1.6 % bending strain at release | ✅ Tough resin. |

## Arm joint (the wiring path, owner: "no pinched wires")
| Fit | Value | Verdict |
|---|---|---|
| Wire route | Rear side all the way: heel channel → flex zone → strut bore → rear riser → pad-board pads. **No crossing over the NiTi.** | ✅ Fixed 2026-10-01: they used to cross in the flex zone. |
| Heel channel (static) | Ø1.0 for the bare 4 × 0.21 mm litz bundle (~0.5 mm); walls ≥ 0.62 mm | ✅ |
| Heel mouth counterbore | Ø1.6 × 1.0 deep; seats the shrink-tube end | ✅ |
| Strut bore (static) | Ø1.2 bare bundle; walls 0.6 (rear face) / 0.85 (inner face) | ✅ |
| Strut-top counterbore | Ø1.6 × 1.7 deep; seats the shrink-tube end | ✅ |
| Shrink tube in the flex zone | Use a thin-wall 2:1 polyolefin that recovers to ≤ 1.1 mm OD. Leave ~2 mm of slack as a gentle S across the 3 mm flex gap. | ⚠️ The tube must not be tight between the two counterbores, or it becomes a strut. |
| Strut ↔ heel land | 1.50 mm, all 4 states | ✅ |
| Strut ↔ housing (rev 1) | 1.18–1.34 mm, all 4 states; never touches | ⚠️ Target was 1.4 mm. Locally relieved from 0.65 mm. Fine for clearance; keep hair and debris out of the joint. |
| NiTi in its flare | ≥ 0.009 mm from the R8 flare, all states | ✅ That near-touch is the strain limiter doing its job. |
| NiTi sockets (heel and pad) | Ø0.85 for 0.80 wire, blind | ✅ Print undersize, ream with a 0.85 drill in a pin vise. Re-ream to wire + 0.05 if you switch to 0.75 wire. |
| NiTi set screws | M1.4. Heel: from the front, into a brass nut. Pad: now from the front flat too | ✅ File a small flat on the wire where the screw lands. |

## Transducer pod (cup + cap, screws OK here)
| Fit | Value | Verdict |
|---|---|---|
| Wall minimum | All walls ≥ 0.6 mm except one internal web of **0.56 mm** (nut pocket ↔ front solder pocket) | ⚠️ Internal and potted, no leak path. Accepted. |
| Pad-board solder joints ↔ cap | 0.05 mm gap | ⚠️ **Tight.** Keep the joints low (≤ 0.45 mm); trim and flatten blobs before closing the cap. |
| Strut wire slot | 0.9 mm (top, the direction the wire moves) → 0.15 mm (at the socket) | ✅ From the NiTi model's four states. |
| Hex collar | Grown from 5.9 to 7.4 mm across flats, to wall the rear wire bore | ✅ Slightly bulkier pad top. **Check the Ear (open) clearance on your photos (E9).** |
| Cup closure | One M1.2 self-tapping screw, pilot Ø1.0 | ✅ |

## Phase 2 (shell_r2 + 30 x 12 board), sourced rows (2026-10-07)
| Item | Value | Source | Used in |
|---|---|---|---|
| Board outline (CNC) | ±0.2 regular, ±0.1 precision option | JLC capabilities page fetched 2026-10-07, HTML SHA-256 62ffae95727c8b4e | dims_r2.duct_offsets outline_to_hole; x-stop 0.25 > 0.2 so the walls never fight the gauge pin |
| Drilled hole size | +0.13 / −0.08 (D0.6 → 0.52-0.73); "press-fit" option ±0.05 for 0.55-2.0 mm round holes on multilayer ENIG (ask in the PCB remark) | same | duct_offsets hole; gauge-pin worst 0.155 ≤ 0.20 ✅; spec §8 hole 0.6-1.0 ⚠️ (0.52 possible, sub-audio-in issue 15) |
| Hole position | ±0.075 | same | pin registers to the hole itself, so it drops out of the duct stack |
| Board thickness 0.8 | ±0.1 (0.7-0.9) | same | B gap margin 0.32 → 0.22 worst ✅; port-hole length 0.7-0.9 (acoustics) |
| VHB 4914 thickness | 0.25 ±15 % (±0.0375) | 3M TDS rev 2024-09, SHA-256 2fc355523c5e5dff | switch_stack ✅ selective fit unchanged; F-gap slack 0.0125 worst ✅ |
| Resin print ±0.05, KMT022 height | still [A] | – | switch_stack (C&K gives 0.65 nominal only) |

## Two things to measure before printing for real
1. Print a **tolerance coupon** with the actual resin and printer: holes of Ø0.8/0.85/1.0/1.2/1.6 mm, slots of 0.3/0.4/0.5 mm, and a 0.15 mm slide fit. Adjust the numbers above to what really happens.
2. **Dry-fit the real cell and board** before bonding anything. The CAD uses the cell datasheet's *maximum* envelope.

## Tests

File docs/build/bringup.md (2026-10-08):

# Bring-up plan (ECR-0010)

Generated from `docs/build/bringup.yaml` by `docs/build/make_bringup.py` (2026-10-07). Edit the YAML, not this file.

**How to use it.** Work top to bottom. Each step has what to do, the tools, the value our models predict (with tolerance), the pass line and what to do on a fail. Write every reading into the board's log (board 1 becomes the reference for boards 2-3). A red **gate** means: stop here until the step before it passed.

sequence

10 stages, 50 steps. `[A]` = assumed tolerance, refine on board 1.

## Gates (never skip)

- **G0**: stage A done before any board is powered (parts and prints known good)
- **G1**: no power until B2 (all short/continuity checks) passes
- **G2**: no 5 V dock power until C1 (current-limited cell-side power) passes
- **G3**: no lid bond (physical.md step 8) until D4 (boot stub + DFU re-flash over USB) passes: SWD is gone after the bond (DBG-16)
- **G4**: no exciter until E7 (|Z| on a resistor) and E8 (fault break) pass
- **G6**: K4 (two stacked boards P/M, ECR-0020/0021): no BM28 mate until K1 and K2 pass (each board alone, no shorts); no power through the mated stack until K4 passes (reversal table)
- **G7**: K4: no cell on the charger until K8 dock-pad/head check passes; first charge only fire-safe (K9)
- **G5**: no wear on the head until H2 (Off current) and the supervised first charge (E6) pass (ECR-0009)

## Tools

- **Have:** soldering iron + flux + fine tips (O13); oscilloscope (O13); multimeter with diode mode [A: assumed, 'etc.']; current-limited bench supply [A: assumed]; LCR meter (spec L575); Nordic PPK2 power profiler (spec L575); loupe / microscope [A]; calipers; kitchen scale (1 g); pin vise + drills 0.8/0.85/1.0; PC with USB
- **Buy with the freeze order (O21):** pin-gauge set 0.50-1.00 mm x 0.01 (RPB-16); 20G hypodermic tube (gauge-pin sleeve); USB-UART 3.3 V adapter for TP7 printf; dock cable: 5-pin YZP0048 head + USB-C plug with CC wired (DK-09); thermocouple for the charge log (PWR-I4) [A: if the multimeter has none]; SWD probe only if DFU-first fails (DBG-1 option C)
- **Software:** dfu-util (FOSS) [TBD: confirm U575 DFU support]; fw/tools/pod_test.py (FWSIM-R63); python3 sim/fw/fmac_model.py --bench (FMAC expected words)

## Stage A: Before the board: prints, parts, coupons (no electricity)

### A1. print the tolerance coupon + tub, lid, 5-puck kit; wash, cure; measure holes 0.8/0.85/1.0/1.2/1.6 and slots 0.3/0.4/0.5; dry-fit the pad cap + pad board + exciter, shim tight fits

| | |
|---|---|
| Tools | calipers, pin vise |
| Expect | printed holes close ~0.05-0.1 [A]; after reaming the D1.0 bore: 1.00-1.02 |
| Pass | bore admits a 1.00 pin, not a 1.03 |
| On fail | adjust print compensation, reprint |
| Closes | PAD-4, RB-TOL |
| Source | tolerances.md Phase-2 section; dims_r2.duct_offsets |

### A2. ream the heel exit D0.8 neck from the cavity side (straight along -y); fish a wire through the D1.0 channel

| | |
|---|---|
| Tools | pin vise 0.8 |
| Expect | outer wall 0.60 stays intact; 4 x 0.21 litz + fish pass |
| Pass | no breakthrough, fish passes both bends |
| On fail | reprint; if the neck cracks again: widen wall in heel.py (CH_EXIT) |
| Closes | ARM-1R |
| Source | notes/heel.md build order; heel.py checks |

### A3. dry-fit the real Renata ICP501233PA-02 in the printed tub; note where its leads/PCM exit

| | |
|---|---|
| Tools | calipers |
| Expect | cell 35 x 12 x <=5.3 sits on the 0.3 VHB gap; exit hole 0.20 behind the cell end, rim-corner 0.36 |
| Pass | cell flat, heel exit not covered |
| On fail | record lead exit; adjust J5/J4 route or CELL constants; re-run dock_route.py + heel.py |
| Closes | ARM-1R, PWR-I10 |
| Source | reg-arm issue 1; physical issue 10 |

### A4. dock target sample: caliper the body + tab, identify contact order and magnet keying

| | |
|---|---|
| Tools | calipers, multimeter |
| Expect | 21.2 x 6.86 x 2.8 body, 5.03 tab (LCSC drawing) |
| Pass | fits the belly window; order recorded in gen.py + sub-dock-usb |
| On fail | update dims_r2.DOCK and shell_r2 |
| Closes | DK-02, DK-03 |
| Source | sub-dock-usb DK-02/03 |

### A5. exciter E1: LCR meter R and L at 1 kHz (3+ samples, two listings)

| | |
|---|---|
| Tools | LCR meter |
| Expect | 8 or 12 ohm; L 0.3-1.3 mH (model placeholders) |
| Pass | R and L recorded; L < ~1 mH keeps 200 kHz PWM |
| On fail | L >= 1 mH: PWM-rate fallback 100 kHz (sub-output issue 2); 12 ohm clears ECR-0005 |
| Closes | ECR-0007 |
| Source | sub-output issues 2, 3 |

### A6. gauge pin kit: measure the 20G tube OD/ID and the pin gauges

| | |
|---|---|
| Tools | calipers, pin-gauge set |
| Expect | tube OD 0.88-0.92, ID 0.59-0.62 [A ISO 9626] |
| Pass | computed worst duct stack <= 0.175 (with the pin chosen to the actual board hole: ~0.12) |
| On fail | micro-turned stepped pin (RPB-16 option B) |
| Closes | RPB-16 |
| Source | reg-pod-body issue 16 |

### A7. VHB coupon: a bare FR-4 coupon on VHB to a printed lid piece; 1.6 N press (163 g on the kitchen scale) on a dummy SW1 spot; optional 600k-press rig

| | |
|---|---|
| Tools | kitchen scale |
| Expect | board deflection 1.4-20 um at 2 N (not visible); VHB 12-52 kPa vs 85 kPa design factor |
| Pass | no peel, no visible movement |
| On fail | back the switch (B back-stop) or a stiffer bond area |
| Closes | RPB-17 |
| Source | sim/checks/sw1_press_fem.py; sub-ui issue 2 |

### A8. NiTi coupons: wire 0.75/0.80/0.85 bend test at skin temperature, 100 on/off cycles; flare root under a loupe

| | |
|---|---|
| Tools | loupe, kitchen scale |
| Expect | plateau ~200 MPa [A]; force >= 0.5 N at jaw opening |
| Pass | pick the wire; no root crack after 100 cycles |
| On fail | STRUT_START 3 -> 4 mm (ARM-5) or the 0.85 wire (ARM-2 B) |
| Closes | ARM-3, ARM-4, ARM-5 |
| Source | reg-arm issues 3-5 |

### A9. body + wear: E9/E10/E12 measures on her glasses; weighted dummy pair 2 h with 11.2-13.2 g per side

| | |
|---|---|
| Tools | printed dummies, kitchen scale |
| Expect | comfortable for 2 h; temple give E12 |
| Pass | owner says yes |
| On fail | mass trims (PHYS-8D options B/C); set change ARM-2 |
| Closes | ECR-0006, ARM-2, ARM-9, Q-A-PHYSICAL-FIRSTWINS |
| Source | physical issue 8; reg-arm 2, 9 |

### A10. FMAC rounding read-back on any STM32U5 board (Nucleo-U575 if at hand, else at E10): FIR P=1, CLIPEN=1, 8 inputs

| | |
|---|---|
| Tools | U5 board, PC |
| Expect | TEST A1 under floor: 0,0,0,0,-1,-1,-1,-1; TEST A2: 0,0,1,1,-1,-1,-1,-2 (`python3 sim/fw/fmac_model.py --bench`) |
| Pass | matches floor (the firmware model) |
| On fail | change A1/A2 in fw/core/fmac_model.c + Python twin, re-run fwsim L0/L2/D17 |
| Closes | FMAC-RM-UNKNOWNS |
| Source | backlog FMAC-RM-UNKNOWNS |

## Stage B: Bare assembled board, unpowered

### B1. visual under the loupe: U3 balls, U1 QFN, Q1/Q2 (Nexperia land pattern), SW1, D5/D6, 0201 tombstones, R23 present, LED cathode mark on the pad board; mic hole clean

| | |
|---|---|
| Tools | loupe, pin gauges 0.60/0.70 |
| Expect | mic hole D0.65 press-fit: 0.60 enters, 0.70 does not |
| Pass | no bridge, no tombstone, hole in tolerance |
| On fail | photograph, rework with flux + iron or use board 2 |
| Closes | OUT-4, PAD-8 |
| Source | sub-debug-test step 0; SAI-15D |

### B2. short checks, ohms then diode mode both polarities: TP4-TP5 (+3V0-GND), TP6-TP5 (VSYS-GND), J5-J4 (VBAT-GND), J3-J4 (DOCK_VBUS-GND) and the 6 neighbour pairs J3-J4, J4-J5, J1-J2, J2-J8, J12-J9, J10-J11 (test-access-map.svg)

| | |
|---|---|
| Tools | multimeter |
| Expect | no pair < 5 ohm; J12-J9 ~15 kohm at 25 C (R18 5k1 + RT1 10k NTC, both to GND); others > 1 kohm in ohm mode, diode drops 0.3-0.8 V where a pin or body diode sits |
| Pass | no short, board 1 readings recorded as the reference for boards 2-3 |
| On fail | J4-J5 = cell short; J3-J4 = dock supply short; J12-J9 = CC on TS; J2-J8 = 200 kHz into PB7; J1-J2 = exciter shorted: find the bridge under the loupe, wick |
| Closes | RB-4 |
| Source | sub-debug-test step 1; reg-board issue 4 |

## Stage C: First power, current-limited, cell side

### C1. bench supply 3.70 V, current limit 50 mA, on J5(+)/J4(-) (cell pads); blank MCU

| | |
|---|---|
| Tools | bench supply, multimeter |
| Expect | TP6 VSYS ~3.7 V; TP4 +3V0 2.955-3.045 V (SBVS338H); supply current: record (blank U575 in reset/ROM, few mA [A]) |
| Pass | +3V0 in range, current < 15 mA [A], nothing warm |
| On fail | limit hit: lift R20 (LDO_OUT vs load), feed 3.0 V into TP4 at 30 mA to split; U3 battery POR needs VBAT > 3.46 V max |
| Closes | - |
| Source | sub-debug-test step 2; sub-power +3V0 |

## Stage D: Programming: DFU first, SWD backup, boot stub

### D1. first flash: tack R1.1 PH3 (2.58, 3.85) to +3V0 C1.1 (6.92, 0.83) (both B), 5 V at 100 mA limit on J3/J4, USB D+/D- on J10/J11, power-cycle, dfu-util flash the board-alive image, remove the tack

| | |
|---|---|
| Tools | iron, USB cable, PC, dfu-util |
| Expect | ROM DFU enumerates (ST DFU 0483:df11) WITHOUT PA9 VBUS sense (DK-17D option B test) |
| Pass | image runs after the tack is removed |
| On fail | no enumeration: DK-17 is real: SWD on TP1/TP2/TP3/TP5 (probe purchase decision, DBG-1 C), then R24 at the next placement round (DK-17D option C) |
| Closes | DK-17, DBG-1 |
| Source | sub-debug-test step 3; decisions-log DK-17D = B then C |

### D2. ST-HELLO + option-byte dump over USB CDC

| | |
|---|---|
| Tools | pod_test.py |
| Expect | build id = git sha of the image; RDP 0; nSWBOOT0/nBOOT0 defaults |
| Pass | matches the build |
| On fail | re-flash; record option bytes (CV-8) |
| Closes | - |
| Source | FWSIM rev1_telemetry; CV-8; HWC-12 |

### D3. SWD attach once while F is reachable (only if a probe exists)

| | |
|---|---|
| Tools | SWD probe (optional) |
| Expect | IDCODE read |
| Pass | attach + halt |
| On fail | note it; DFU stays the path |
| Closes | - |
| Source | sub-debug-test step 3 |

### D4. boot stub: jump to ROM DFU over USB and re-flash; repeat with 2.95 V on TP4 (R20 lifted); keep a DFU session > 160 s with the charger watchdog armed; with a cell fitted note charging pauses in DFU

| | |
|---|---|
| Tools | PC, bench supply |
| Expect | enumeration + full DFU at 2.95 V (DS13737 Table 150 fn 1: functional to 2.7 V); charger watchdog does not reset U3 mid-session (stub writes WATCHDOG_SEL 11); charging pauses (PA2 drives TS high) |
| Pass | all three |
| On fail | USB at 2.95 V fails: higher-V LDO option (DK-06 B); watchdog fires: fix the stub order |
| Closes | PWR-I7, DBG-8 |
| Source | sub-debug-test step 6; DK-06; PWR-I3 |

### D5. PB4 back-feed in reset and DFU: meter C13.1 (MIC_VDD) and TP10 (MIC_DATA)

| | |
|---|---|
| Tools | multimeter, PPK2 |
| Expect | record; ~60 uA class back-feed path (ECR-0013 F5) |
| Pass | recorded; Off-mode rule documented |
| On fail | firmware parks PB3/PB4; accept in reset/DFU only |
| Closes | SAI-11 |
| Source | sub-audio-in issue 11 |

## Stage E: Peripherals with the firmware's self-tests (bare board, F still reachable)

### E1. ST-CLK: LSE start, MSI-PLL lock, PLL1, HSI48+CRS, ADF kernel; scope MIC_CLK at R2.2 (B) and the SMPS node near L1

| | |
|---|---|
| Tools | oscilloscope, pod_test.py |
| Expect | all ready, DWT-timestamped; MIC_CLK duty 48-52 % (spec R13/D13); SMPS ~3 MHz free-running (PROC-9) |
| Pass | duty in range, clocks locked |
| On fail | duty out: MDF fallback via TP8/TP9/TP10 (sub-audio-in issue 5) |
| Closes | SAI-5 |
| Source | CV-4, CV-10; sub-debug-test step 4 |

### E2. ST-RAILS + ST-PINS: VDDA from VREFINT, VBAT (ADC4) vs multimeter, VBUS, TS, die temp, I_SENSE idle offset

| | |
|---|---|
| Tools | multimeter, pod_test.py |
| Expect | VDDA 2.955-3.045 V; VBAT within 1 % of the meter [A]; I_SENSE idle = R23 offset 3.0 mV +-0.3 mV (3.0 V x 1k / 1.001M) plus the Kelvin term |
| Pass | all plausibility rules pass (FWSIM-R58 ST-PINS) |
| On fail | R23 offset off: check R23 value / I_SENSE copper |
| Closes | - |
| Source | FWSIM-R58; R23 1M (OUT-1B) |

### E3. UI: LED on a pad board (or any LED) on J7/J8; press SW1; printf on TP7 via the USB-UART

| | |
|---|---|
| Tools | USB-UART 3.3 V, multimeter |
| Expect | LED current (VSYS - VF)/2.2k: 0.45-0.50 mA at 3.7 V; +1.36 mA while pressed; PA0 high; TP7 text |
| Pass | LED from PB7, button edges logged |
| On fail | LED dark = reversed (PAD-8) |
| Closes | UI-7 |
| Source | sub-debug-test step 5; sub-ui key numbers |

### E4. ST-USB: CDC enumerates, 16-bit mic-rate stream for 60 s

| | |
|---|---|
| Tools | PC, pod_test.py |
| Expect | 0 gaps over 60 s; 3.2 Mbit/s (33 % of USB FS bulk) |
| Pass | 0 gaps |
| On fail | drop to 8-bit or shorter frames; check D+/D- pads |
| Closes | - |
| Source | FWSIM-R60; CV-5 |

### E5. I2C2: read U3 at 0x6A at 100 and 400 kHz; scope SCL rise time

| | |
|---|---|
| Tools | oscilloscope |
| Expect | ACK; rise time with R15/R16 10k + ~10-20 pF bus [A]: 85-170 ns (< 300 ns for 400 kHz); exercises the In2 SCL run |
| Pass | ACK at 400 kHz and rise < 300 ns |
| On fail | run 100 kHz (TIMINGR table, FWSIM-R27); check the In2 bridge |
| Closes | - |
| Source | FWSIM-R27; sub-debug-test step 7 |

### E6. ST-CHG with the real cell: register dump at first power-up vs OTP defaults, write the register plan, read back; first charge SUPERVISED with a thermocouple on the cell

| | |
|---|---|
| Tools | thermocouple, multimeter, pod_test.py |
| Expect | defaults ICHG 10 mA, VBATREG 4.20 V, ILIM 500 mA, TS_HOT 60 C (then the plan: TS_HOT 45 C...); ILIM 100 mA until enumeration; U3 ~0.3 W at start of CC; RT1 reads hot (1.8 mm from U3) |
| Pass | read-back = plan; cell <= 45 C; charge ends at VBATREG |
| On fail | stop charge; reg plan or placement (RT1 lever, PWR-I4) |
| Closes | PWR-I4, PWR-I12, PWR-I10 |
| Source | FWSIM-R20, R62; CV-7; ECR-0009 item 3 |

### E7. bridge on an 8-12 ohm RESISTOR on J1/J2 (no exciter): low level tones, ST-ZSWEEP at -12 dBFS; scope OUT_A/OUT_B edges for dead time

| | |
|---|---|
| Tools | oscilloscope, 8-12 ohm resistor, pod_test.py |
| Expect | |Z| = R + 1.22 (Rds) + 0.1 (R21) within 2 % at -12 dBFS (selftest_lockin.py); dead time per knob 12.5-25 ns, no shoot-through spikes on the supply |
| Pass | |Z| within 2 %; no shoot-through |
| On fail | lift R21 to isolate the bridge; dead-time knob up |
| Closes | OUT-7 |
| Source | sub-debug-test step 9; sim/checks/selftest_lockin.py |

### E8. fault break (FWSIM-R65): with the resistor load, step the load to ~2 ohm through a current-limited supply rail or command an over-range test tone; confirm the MDF out-of-limit break fires and its polarity/threshold; record the MDF kernel clock

| | |
|---|---|
| Tools | oscilloscope, pod_test.py |
| Expect | TIM1 MOE cleared within 2 PWM periods [A], outputs to the safe state, BIF latched, event logged |
| Pass | break fires on both polarities of i*(2d-1); not on normal signals |
| On fail | fix BKOLD/threshold knobs; never ship without it (OUT-6 decided) |
| Closes | - |
| Source | FWSIM-R65; sub-processing issue 6 |

### E9. ST-PWMAB: PWM-noise A/B at 200/400/800 kHz vs stopped, mic streaming

| | |
|---|---|
| Tools | pod_test.py |
| Expect | 20-85 kHz band power difference per rate |
| Pass | lowest rate under the mic floor chosen |
| On fail | keep 400/800 kHz; MP-01 mitigations |
| Closes | OUT-8 |
| Source | FWSIM-R61; MP-01 |

### E10. ST-CYC micro-benchmarks + DWT per-hop stats; FMAC read-back if A10 had no Nucleo

| | |
|---|---|
| Tools | pod_test.py |
| Expect | cycles within the E1/E2 model bands (FWSIM-R47) |
| Pass | headroom >= the budget at the chosen clock |
| On fail | re-plan clock or algorithm (E2-ALGO) |
| Closes | FMAC-RM-UNKNOWNS |
| Source | FWSIM-R50; CV-2 |

## Stage F: Bond board to lid (gate G3), then the mic through the real duct

### F0. physical.md steps 6-8: solder wires, VHB die-cut, gauge pin through bore into the board hole, bond

| | |
|---|---|
| Tools | pin gauge + 20G tube, foam pad, kitchen scale (~30 N press [A]) |
| Expect | duct offset <= 0.14 (pin chosen to the hole) |
| Pass | pin slides out freely after the press |
| On fail | peel before cure |
| Closes | - |
| Source | physical.md steps 6-8; DBG-16 |

### F1. mic self-noise capture over USB: bridge on/off, SMPS vs LDO (REGSEL)

| | |
|---|---|
| Tools | pod_test.py |
| Expect | LN-M01 margin 26.5 dB modelled (worst 15.5 dB) |
| Pass | no line above the floor in 20-96 kHz |
| On fail | series R + C on MIC_VDD (sub-audio-in issue 7) |
| Closes | SAI-7 |
| Source | sim/noise smoke 2026-10-07 |

### F2. duct sweep: 40 kHz HC-SR04 + a swept ultrasonic source at a fixed distance, pod vs bare-board reference

| | |
|---|---|
| Tools | ultrasonic source, pod_test.py |
| Expect | mean 20-96 kHz +5.9 dB re flush (MC p05 +1.2); resonance ~61 kHz, +18.4 dB (~+14 dB with the floor mesh) |
| Pass | resonance found; EQ notch constant set (O18 knob) |
| On fail | mesh position / duct (sub-audio-in 3, 13) |
| Closes | SAI-13 |
| Source | acoustics MC60 2026-10-07 round 8 |

### F3. RSFLT response at 800 kHz: swept tone D1 vs D2 decimation

| | |
|---|---|
| Tools | ultrasonic source |
| Expect | record |
| Pass | decimation choice made |
| On fail | - |
| Closes | SAI-6 |
| Source | sub-audio-in issue 6 |

### F4. E11 whine: listen for SMPS / L1 whine, docked and undocked, RIGHT pod (dock magnets 5.5 mm from L1)

| | |
|---|---|
| Tools | ears |
| Expect | nothing audible |
| Pass | silent |
| On fail | LDO mode during listening (REGSEL) |
| Closes | DK-11 |
| Source | sub-dock-usb DK-11 |

## Stage G: Exciter and listening (gate G4)

### G1. exciter on J1/J2 via the arm; |Z| sweep low amplitude; listen for C14 'sing'

| | |
|---|---|
| Tools | pod_test.py, ears |
| Expect | |Z| close to A5's LCR values; no audible sing |
| Pass | both |
| On fail | C14 swap (OUT-5); PWM rate |
| Closes | OUT-5, PAD-11 |
| Source | sub-output issues 2, 5 |

### G2. E2 listening: translated nature files through the exciter at the tragus; pick the algorithm variant

| | |
|---|---|
| Tools | ears |
| Expect | spec B passes bat-call recall 0.83 in sim; slim B 0.65; A 0.39 |
| Pass | owner picks |
| On fail | - |
| Closes | E2-ALGO, ECR-0007 |
| Source | backlog E2-ALGO |

## Stage H: Close the pod, then current and feel

### H1. puck selective fit (physical.md step 9), skin, close with tape (test build)

| | |
|---|---|
| Tools | calipers |
| Expect | puck top -> skin 0.005-0.135 |
| Pass | one click per press, none at rest |
| On fail | next shorter / longer puck |
| Closes | - |
| Source | physical.md step 9 |

### H2. Off current: Stop 2, PPK2 in series with the cell

| | |
|---|---|
| Tools | PPK2 |
| Expect | 15.5-22.7 uA (off_D12) + R23 3.0 uA = 18.5-25.7 uA [derived] |
| Pass | <= ~26 uA |
| On fail | +1.36 mA = SW1 pre-pressed: refit the puck; else PB3/PB4 back-feed |
| Closes | PWR-I15 |
| Source | sub-power off_D12; CV-1 |

### H3. dock charge, LED, pad force T5 (kitchen scale under the pad)

| | |
|---|---|
| Tools | kitchen scale |
| Expect | pad force >= 0.5 N worn (preload model) |
| Pass | all |
| On fail | set change (ARM-2) |
| Closes | - |
| Source | physical.md step 14 |

## Stage I: Environment and wear (gate G5)

### I1. spray coupon IPX4 5 min, open along the rebate, inspect indicator tape; then IPX5; 3 open/rebond cycles

| | |
|---|---|
| Tools | spray nozzle, indicator tape |
| Expect | no water inside; mesh holds (Laplace ~2.7 kPa at 42 um) |
| Pass | dry inside |
| On fail | corner beads (RPB-13), mesh treatment, dock potting |
| Closes | - |
| Source | docs/research/sealing-and-service.md |

### I2. 2 h wear with the real pod pair, then a day

| | |
|---|---|
| Tools | - |
| Expect | comfortable; no rub |
| Pass | owner says yes |
| On fail | mass / force changes |
| Closes | ECR-0006 |
| Source | ECR-0006; PHYS-8D |

## Stage K: K4 two-board stack (P + M, ECR-0020/0021): each board alone, BM28 mate, dock, first charge (gates G6, G7)

### K1. board M bare (before any mate, cell, or head): meter on 0.1 ohm-resolution range, pads J3 VBUS / J4 GND / J5 BAT+ / J9 NTC / J7 LED+ / TP6 VSYS / TP4 +3V0 and BM28 J20 pins

| | |
|---|---|
| Tools | multimeter, loupe |
| Expect | J4(GND) to J5(BAT+): R8+R9 = 2 Mohm 1% (reads 1.6-2.0 Mohm with U3 BAT leakage, never <1 Mohm); J9(NTC) to GND: RT1 10 kohm 1% = 9.9-10.1 k at 25 C (Murata NCP03XH103F05RL); J3(+) to J4 diode mode: PMEG3005EL D4 forward into R12+R13 = 200 kohm, 0.2-0.35 V, reverse OL; J7 to TP6: R14 2.2 kohm 1% (2.18-2.22 k); BM28 pin25 (BTN) to GND: R10 2.2 kohm 1%, pin15 (+3V0) to pin7 (SCL) and pin9 (SDA): R15/R16 10 kohm 1%; pin27 (VBUS_SENSE) to GND: R13 100 kohm 1%; pin5 (VBAT_SENSE) to GND: R9 1 Mohm 1% (parallel R8 path = open); R20 0R: LDO_OUT to TP4 under 0.5 ohm; +3V0 to GND >100 kohm (C21/C17/C18 charge, the reading climbs: not a short); no VBUS/VSYS/+3V0 to GND under 1 kohm |
| Pass | all within tolerance, no short |
| On fail | hot-air or reflow touch-up of the named 0201; U3 DSBGA-8 0.4 mm bridge suspected if VSYS/VBUS < 1 kohm to GND: microscope, do not power |
| Closes | K4-BRINGUP |
| Source | hw/pod/k4/pod_k4_M.net; bom_jlc_M.csv; sub-power.md |

### K2. board P bare: U1 supply pins, BM28 J21 pins, TP1-TP3, TP7-TP9, J1/J2

| | |
|---|---|
| Tools | multimeter, loupe |
| Expect | +3V0 (J21 pin15) to GND: no resistive short (>50 kohm; decoupling charges, the reading climbs); BOOT0 (U1 PH3) to GND: R1 10 kohm 1%; each TIM1 gate net to GND or +3V0 (R3-R6): 100 kohm 1% each; R21 0.1 ohm sense: 0.1 ohm +-1% (2-wire reads 0.2-0.4 ohm incl. leads: use the 4-wire/LCR) ; R23 1 Mohm; C14 22u/C4/C7 10u: LCR 1 kHz within +-20% of nominal minus DC-bias (unbiased); L1 2u2: 2.2 uH +-20% at 1 MHz (Murata DFE201610E-2R2M), DCR <= ~0.1 ohm [A]; Q1/Q2 diode mode: body diode 0.5-0.8 V one way, OL the other; J1-J2 across the exciter pads: open (no exciter yet) |
| Pass | no short; passives within tolerance; U1 pin 1 orientation matches pin1_expected.png |
| On fail | U1 QFN-48 bridging: inspect/reflow; wrong-rotation part (pin1 check B5 in .pcba-workflow/k4-release/gate.yaml) |
| Closes | K4-BRINGUP |
| Source | hw/pod/k4/pod_k4_P.net; bom_jlc_P.csv; gate.yaml B5 |

### K3. M alone: inject 3.00 V (current limit 20 mA) at TP4 (+3V0) / GND, and again 4.0 V at J5 (BAT+, cell stand-in, limit 20 mA, no cell)

| | |
|---|---|
| Tools | bench supply, multimeter, PPK2 |
| Expect | at 3.0 V into TP4: current < 5 uA once caps settle (no load on M except pull-ups to idle MCU-less inputs, R10 not driven, mic VDD unpowered: PA5 on P); at 4.0 V on J5: U3 BAT FET path: VSYS (TP6) = about 4.0 V minus 55 mohm x load; U4 LDO_OUT (R20 side) = 3.00 V +-1% (TPS7A2030PDQNR fixed 3.0 V, SBVS338H) with +3V0 0.00-0.01 V drop across R20; supply current 6.5 uA LDO Iq + 3.2 uA U3 ship/battery-only Iq [datasheet typ] -> 8-20 uA total |
| Pass | LDO 2.97-3.03 V; idle current < 30 uA |
| On fail | LDO off: check U4 EN to VSYS and C17/C18 orientation-free; current > 100 uA: U6/D5 reverse leakage or flux residue (clean, bake) |
| Closes | K4-BRINGUP, PWR-I14 |
| Source | sub-power.md U4_noise_iq, U3_fet_iq; TPS7A2030 SBVS338H |
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

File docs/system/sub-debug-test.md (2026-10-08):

# SUB-DEBUG-TEST: SWD, test pads + dots, isolation links, ROM DFU, USB self-test, bring-up
Rev MZ-2 2026-10-07: body rewritten to the Phase-2 design (`hw/current.yaml`, ECR-0018): TP1-TP6 bare 0.7 pads on F in per-pad VHB cut-outs (reachable only before the board is bonded to the lid); TP7-TP10 dots, R1 PH3 tack pad, R20/R21 and every probe point on B (reachable with the lid lifted); R21 0402; LN-M03 1.29 % PASS; all nets routed. Rev F/G facts moved to the last section.
Status: schematic = Rev G nets, MZ-2 packages (`hw/pod/pod_mz2.net`; bom_check netlist/nets PASS 2026-10-07); board `hw/pod/draft_r2/out/routed.kicad_pcb`: 610 track segments, 136 vias (0.35/0.15), DRC 0, 0 unconnected (pcbnew probe + ECR-0018 log, 2026-10-07); interfaces.py clamp-bands (VHB face) PASS 91 % bonded, 2026-10-07. Not done: snap-off test frame; self-test firmware (requirements only, FWSIM-R57..R61); no hardware ordered (O21) → no bring-up. Updated 2026-10-07.

```yaml
abbrev: {SWD: "Arm 2-wire debug port", DFU: "USB Device Firmware Upgrade (ST ROM bootloader)", CDC: "USB virtual serial port", TP: "test pad/dot", VHB: "3M VHB 4914 0.25 mm acrylic foam tape that hangs the board from the lid", MDF/ADF: "STM32U5 multi/audio digital filter", F/B: "board faces: F = outer (bonded to the lid), B = inner (toward the cell)", "(x, y)": "board mm, origin top-left, KiCad top view"}
item: SUB-DEBUG-TEST
src_of_truth: ["hw/pod/gen.py (NRST, C10, R1; R21/R22/C22; R20; TP1-TP10; MZ2 table)", "hw/pod/draft_r2/out/routed.kicad_pcb (positions)", "hw/pod/draft_r2/placement.yaml", "hw/mech/dims_r2.py (F_PADS, TP_PAD_D, TP_CUT_MARGIN)", "hw/mech/shell_r2.py::vhb", "hw/lib/pod.pretty/TestPoint_Pad_D0.7mm, TestDot_D0.5mm", "docs/system/pin-contract.yaml", "docs/system/integration-map.md F14 (generated)"]
owner_decisions: {O9: "rev 1 = prototype: pads + snap-off frame", O10: "bonded final build, cut-openable", O13: "own bench, no tool purchases", O15: "self-test over USB (size clause superseded by O20)", O18: "fail informatively; DFU most-verified, SWD backup; spare pins to pads; removals stated", O19: "diagnosability", O20: "test access must not cost size", O21: "no orders before freeze", O22: "freeze = evidence gate", O25: "Claude lays out; owner reviews in 1-2 weeks (supersedes O14 for rev 1)", O26: "Phase 2 now"}
ecrs_open: {ECR-0005: "self-test drive level vs U4 300 mA (interfaces.py rails: +3V0 peak 326 mA, 2026-10-07)", ECR-0009: "no output while docked vs docked self-test (DBG-12)", ECR-0010: "bring-up plan + firmware before order", ECR-0013: "S1 implemented (PB5 strapped to GND); S2 firmware (UCPD_DBDIS order) open; S3 partial", ECR-0018: "Phase 2 package set + board (approved, owner review pending)"}
checks: ["tools/checks/interfaces.py [clamp-bands] (2026-10-07: PASS, 7 F parts in VHB cut-outs, 91 % bonded)", "tools/checks/interfaces.py [board-nets] (PASS)", "sim/noise LN-M03 (2026-10-07: 1.29 % PASS)"]
diagrams: ["docs/diagrams/board-map-phase2.png (tools/board_map.py)", "docs/diagrams/schematic-rev1.png (block flowchart, nets unchanged)"]
```

## Scope
```yaml
carries: [F14 debug/flash/test, "F4 test side (|Z| self-test; circuit owned by sub-output)"]   # integration-map §1
brief: "O18: rev 1 will partly fail; every failure diagnosable from the board (hooks, telemetry, isolation links); USB DFU = most-verified path; SWD = backup"
access_by_build_stage:   # physical.md assembly order; shell_r2.py docstring (2026-10-07)
  bare_board: "everything: F TP1-TP6 + B dots/pads"
  board_bonded_to_lid: "F face is on the VHB: TP1-TP6 unreachable (physical.md step 8). B face faces the cell: lifting the lid lifts the board on its wires and exposes B (test build: peel the seam tape)"
  final_bonded_pod: "dock only (USB DFU, CDC); B face after cutting the seam; SWD needs the board peeled/sawn off the lid (reg-pod-body issue 15)"
access_paths:
  - {id: AP-DFU1, what: "first flash, blank chip: tack R1 PH3 pad R1.1 (2.58, 3.85) B -> +3V0 at reset -> ROM USB DFU on J10/J11", src: "integration-map F14 'R1 pad = DFU tack point'; ECR-0018 log 2026-10-03 (field recovery = ROM DFU via R1/PH3 on B + dock USB)"}
  - {id: AP-SWD, what: "SWD on TP1/TP2/TP3/TP5 (TP4 = probe Vref sense only); bench only, before the lid bond", src: "gen.py TP block; dims_r2.F_PADS"}
  - {id: AP-USB, what: "app CDC self-test stream + boot-stub jump to ROM DFU for updates (boot stub not designed: sub-dock-usb)", src: "integration-map F10"}
  - {id: AP-UART, what: "TP7 = PB6 USART1_TX printf, B face (works with USB dead; SWO lost to MIC_CLK on PB3)", src: "pin-contract.yaml DBG_TX"}
  - {id: AP-HAND, what: "probe dots/cap terminals on B; lift R20 (rail) or R21 (bridge); both 0402 hand hooks (gen.py MZ2 'kept on purpose')", src: gen.py}
why_blank_needs_hook: "R1 holds BOOT0 low -> boot from (empty) flash; U575 has no empty-flash->bootloader rule (RM0456 Rev 7 Table 25 p.192; AN2606 Rev 69 Pattern 12)"
```

## Elements (Phase 2, positions: pcbnew probe of routed.kicad_pcb, fenced, 2026-10-07)
```yaml
elements:
- {ref: "TP5, TP4, TP2, TP1", part: "Ø0.7 bare copper pad (TestPoint_Pad_D0.7mm)", nets: "TP5 GND · TP4 +3V0 · TP2 SWCLK PA14(37) · TP1 SWDIO PA13(34)", at: "(1.6 / 3.1 / 4.6 / 6.1, 11.3) F: 1.5 mm pitch, 0.8 mm copper gap"}
- {ref: TP3, part: "Ø0.7 pad", net: "NRST(7)", at: "(9.3, 2.9) F, over U1"}
- {ref: TP6, part: "Ø0.7 pad", net: "VSYS", at: "(24.0, 10.9) F, near U3/U4"}
- {ref: "VHB cut-outs", what: "one 1.8 mm square per TP1-TP6 (pad Ø1.0 [A] + 0.4 margin each side) so bonded pads stay clean", src: "dims_r2 TP_PAD_D, TP_CUT_MARGIN; shell_r2.vhb(); interfaces.py clamp-bands 91 % bonded (2026-10-07)"}
- {ref: TP7, part: "Ø0.5 dot", net: "DBG_TX = PB6(42) USART1_TX AF7", at: "(4.25, 9.35) B"}
- {ref: TP8, part: "Ø0.5 dot", net: "MDF_CCK = PB8(45) MDF1_CCK0 AF5", at: "(3.5, 3.85) B"}
- {ref: TP9, part: "Ø0.5 dot", net: "MDF_SDI = PB1(19) MDF1_SDI0 AF6", at: "(2.05, 8.25) B"}
- {ref: TP10, part: "Ø0.5 dot", net: "MIC_DATA (PB4(40), U2 DATA)", at: "(3.1, 8.25) B"}
- {ref: R1, part: "10k 1% 0402 BOOT0 pull-down (hand hook, kept 0402)", net: "N$1 = PH3-BOOT0(44)", at: "(2.07, 3.85) B; PH3 pad R1.1 (2.58, 3.85)", lcsc: "C25744 (bom_jlc_mz2.csv 'dated lookup')"}
- {ref: C10, part: "100nF 0201 X5R NRST filter", net: NRST, at: "(9.55, 0.83) B", lcsc: "C76934"}
- {ref: R20, part: "0R 0402 link LDO_OUT->+3V0 (hand hook)", at: "(23.0, 11.0) B; LDO pad R20.1 (23.51, 11.0)", lcsc: "C17168"}
- {ref: R21, part: "ERJ2BSFR10X Panasonic 0.1R 1% 0402 current-sense (166 mW per docs/research/simplify/output.md L86)", net: "BRIDGE_RTN->GND", at: "(19.45, 6.45) B; GND pad R21.2 (18.94, 6.45) with two pad-hugging GND vias (hw/pod/kelvin_r21.py)", lcsc: "C409058 Extended"}
- {ref: "R22, C22", part: "1k 0201 / 10nF X7R 0201 low-pass 15.9 kHz", net: "BRIDGE_RTN->I_SENSE->PA6(16) ADC1_IN11", at: "(15.4, 3.55) / (15.4, 4.4) B", lcsc: "C270365 / C85930"}
mdf_fallback: "ADF clock duty out of spec (sub-audio-in issue 5): lift R2, wire TP8 (3.5, 3.85) -> R2.2 MIC_CLK (5.48, 8.07), TP9 (2.05, 8.25) -> TP10 (3.1, 8.25); firmware moves mic to MDF1. All on B: lid lifted"
free_pins_no_pad: "PC13(2), PH0(5), PH1(6), PA3(13), PB0(18), PA9(30)  # integration-map §4; PB5 strapped to GND (ECR-0013 S1)"
```

## Probe points (no dedicated pad; all B unless noted; probe 2026-10-07)
```yaml
VBAT: "J5 (28.9, 1.1)"
"+3V0": "TP4 (3.1, 11.3) F; C1.1 (6.92, 0.83); C3.1 (13.23, 0.83); R5.2 (20.68, 10.8)"
VDD11: "C9.1 (5.38, 3.86); C8.1 (14.92, 9.15)"
DOCK_VBUS: "J3 (25.1, 1.7) or D5.1 (25.5, 3.5)"
VBUS: "C15.1 (20.42, 3.4) or R12.1 (17.72, 4.4)"
VSYS: "TP6 (24.0, 10.9) F; C21.1 (19.43, 0.9)"
LDO_OUT_alone: "R20.1 (23.51, 11.0) or C18.1 (23.48, 6.5) (R20 lifted)"
MIC_VDD: "C13.1 (5.12, 5.08)"
MIC_CLK: "R2 (5.48, 7.75): MCU side R2.1 N$2 = PB3 (5.48, 7.43), mic side R2.2 MIC_CLK (5.48, 8.07); duty check E6/D13 at R2.2"
MIC_DATA: "TP10"
I_SENSE: "C22.1 (15.72, 4.4)"
BTN: "R10.1 (17.62, 6.4)"
BOOT0: "R1.1 (2.58, 3.85)"
GB_P / GB_N: "R5.1 (21.32, 10.8) / R6.1 (21.32, 7.35)"
wire_pads: "OUT_A/B J1/J2, LED_A/K J7/J8, TS J9, CC J12, D+/D- J10/J11, VBAT J5, GND J4 (B, rear columns x 25-29)"
silk: "refs on Fab only (hw/pod/silk.py one-face mode); F silk = port motif + name; identify pads from board-map-phase2.png"
```

## What the MCU reads about itself (O18)
```yaml
readable_over_usb:
- {what: "+3V0 = VDDA = ADC ref", how: "VREFINT ADC4 VIN[0] -> back-calc VDDA; VBAT/4 VIN[14] (VBAT pin 1 tied to +3V0)", src: "RM0456 Rev 7 Table 329 p.1383"}
- {what: "VDD11 / die temp", how: "VCORE VIN[12] / VSENSE VIN[13]", src: same}
- {what: "VBAT, VBUS, TS", how: "PA4 VBAT_SENSE (ADC4), PA1 VBUS_SENSE, PA2 TS", src: "integration-map §8"}
- {what: "bridge supply current", how: "PA6 I_SENSE ADC1_IN11", src: "F4; sub-output issue 1"}
- {what: "charger state", how: "U3 registers over I2C2 PB13/PB14 (I2C_SCL partly routed on In2 inside the +3V0 plane, hw/pod/inner_bridge.py)", src: "integration-map F13; ECR-0018 log 2026-10-07"}
not_readable: "VSYS (TP6 only), LDO_OUT apart from +3V0, MIC_VDD + mic current, LED current, coil current, CC voltage (ILIM by enumeration)"
```

## USB self-test (O15): requirements only
```yaml
spec: "docs/sim/firmware-emulation.yaml FWSIM-R57 codec, R58 test set (ST-HELLO/RAILS/CLK/MIC/PWMAB/CHG/ZSWEEP/BTN/EVT/KNOB/CYC/USB/PINS), R59 |Z| sweep, R60 mic stream, R61 PWM-noise A/B (2026-10-02)"
firmware: "none (fw/ absent); docs/research/self-test-firmware.md (cited by O15) does not exist"
caveats:
  - "RAILS: VSYS not covered; docked values differ (VSYS ~4.5 V)"
  - "CLK: mic-clock duty 48-52 % (D13) needs a scope at R2.2 (B)"
  - "MIC: 200 kS/s x 16 bit = 3.2 Mbit/s vs USB FS bulk ~1.216 MB/s (FWSIM-R60, derived, unverified); docked = record only, never listen (spec L562)"
  - "PWMAB: bridge 200/400/800 kHz vs stopped (or R21 lifted); runs docked -> ECR-0009 conflict (DBG-12)"
  - "ZSWEEP: PA6 sees i·(2d-1): |Z|, phase at 2f + DC term (sub-output issue 1 option D, unverified); I_SENSE Kelvin error 1.29 % <= 2 % PASS (LN-M03, sim/noise/out_r2/budget.json, board sha da4e8b13, 2026-10-07); full scale > U4 300 mA (ECR-0005); docked heats U4; blocked docked by ECR-0009 unless exemption (DBG-12)"
  - "CHG: U3 status + VBAT/TS/VBUS through a charge (CC not read)"
```

## ROM bootloader pin effects (AN2606 Rev 69 Nov 2025 §89 Table 199 pp.466-469; effects derived; nets unchanged from Rev G)
```yaml
rom_dfu_pin_states:
- {pin: "PA2 TS", rom: "USART2_TX AF push-pull, pull-up, idles high", effect: "TS ~3.0 V -> U3 reads cold -> charging paused in ROM DFU (DBG-8)"}
- {pin: "PA3 free", rom: "USART2_RX input pull-up", effect: "idles high, no external load"}
- {pin: "PA4/PA5/PA6/PA7 VBAT_SENSE/MIC_VDD/I_SENSE/GA_N", rom: "SPI1 slave, pull-downs; PA6 MISO output", effect: "mic unpowered; leg-A N off; PA6 may drive I_SENSE via R22 (<= 3 mA)"}
- {pin: "PA8 GA_P", rom: untouched, effect: "R3 holds leg-A P off"}
- {pin: "PA9 free", rom: "USART1_TX output, pull-up", effect: none}
- {pin: "PA10 GB_P", rom: "USART1_RX input pull-up", effect: "+ R5 100k to +3V0 -> leg-B P off; RX idle"}
- {pin: "PB15 GB_N", rom: "SPI2_MOSI input pull-down", effect: "+ R6 100k (+ UCPD dead-battery 5.1k if still armed, ECR-0013 S2) -> leg-B N off"}
- {pin: "PB13/PB14 I2C_SCL/SDA", rom: "SPI2_SCK in pull-down / SPI2_MISO out", effect: "PB14 drives SDA; harmless while nothing talks to U3"}
- {pin: "PB5 (GND strap)", rom: "SPI3_MOSI input pull-down", effect: none}
- {pin: "PB6 DBG_TX TP7 / PB7 LED_K", rom: "I2C1 SCL/SDA open-drain pull-up", effect: "TP7 idles high; LED dark"}
- {pin: "PB8 MDF_CCK TP8", rom: "FDCAN1_RX AF pull-up", effect: "unwired: none; MDF fallback wired: pulls the unpowered mic's CLK up (same class as PB4)"}
- {pin: "PB4 MIC_DATA", rom: "not a ROM pin; reset = NJTRST internal pull-up", effect: "back-feeds unpowered mic DATA in reset + DFU (sub-audio-in issue 11); meter at TP10 / C13.1"}
- {pin: "PA11/PA12", rom: "USB FS DFU, HSI48 + CRS, no crystal, no ext pull-up; 'VDDUSB must be connected to 3.3 V'", effect: "+3V0 2.955-3.045 V (DBG-6)"}
bridge_in_dfu: "all four gates off (rows PA7, PA8, PA10, PB15)"
rom_resources: "60 MHz from HSI-PLL; 16 kB RAM from 0x2000 0000; image 0x0BF9 0000 (Table 199 p.466)"
local_copy: "scratchpad boot/an2606.pdf, fetched 2026-09-30, SHA-256 b0ed4c4839c41131 (docs/system/audit-datasheet-claims.md)"
```

## Bring-up sequence (proposal for ECR-0010; adapted from hw/mech/notes/electronics.md §A; build stages per physical.md assembly order)
**K4 stage K (K1-K10, 2026-10-08: each board alone, BM28 mate/reversal table, R30 mic filter, L1 buzz, dock pads + head, first charge, SW1 glue post) is appended to `docs/build/bringup.yaml`; stages A-I still read r2.** **Superseded as the working plan (2026-10-07) by `docs/build/bringup.yaml` (agent twin) / `bringup.md` (owner) / `docs/diagrams/bringup-sequence.svg`: 9 stages A-I, 40 steps, gates G0-G5, each step with tools, expected value, pass, on-fail and the backlog ids it closes. The list below stays as the debug-side summary; step numbers map n1 -> B2, n2 -> C1, n3 -> D1, n4 -> E1, n5 -> E3, n6 -> D4, n7 -> E5/E6, n8 -> F1/F2, n9 -> E7/G1, n10 -> H2.**
```yaml
- {n: 0, stage: bare board, do: "loupe: U3 balls, U1, Q1/Q2 (Nexperia land pattern, ECR-0004), SW1, D5/D6, 0201 tombstones, pad-board LED cathode mark", fail: "photograph, stop"}
- n: 1
  stage: bare board
  do: "meter, unpowered: TP4-TP5, TP6-TP5, J5-J4, J3-J4, then every J-pad neighbour (copper gaps 0.90-1.22 mm, board probe 2026-10-07 after the J3/J4 swap): J3-J4 (dock supply short), J4-J5 (cell short), J4-D5.1 (J4 GND pad edge 0.76 mm from DOCK_VBUS), J4-J12, J4-J9, J12-J9, J12-J11, J10-J11, J10-J12, J9-J5, J9-J3, J9-J10, J1-J2, J1-J7, J1-J8, J7-J8, J7-J10, J7-J11, J8-J2, J8-J11; pad board J2-J4, J1-J3 (reg-pad issue 13); TP row TP5-TP4 (GND-+3V0, 0.8 mm)"
  expect: "no short; record board 1 as reference"
  fail: "J4-J5 = cell short (PCM cuts it). J3-J4 / J4-D5.1 = dock supply short. J12-J9 = CC on TS. J8-J2 / pad-board J2-J4 = bridge output into PB7. J1-J2 = exciter shorted across the bridge"
- {n: 2, stage: bare board, do: "bench 3.7 V, 50 mA limit, J5(+)/J4(-)", expect: "TP6 ~3.7 V; TP4 2.955-3.045 V; record blank-chip current (no reference)", fail: "lift R20 -> LDO_OUT alone at R20.1 -> 3.0 V into TP4 (30 mA limit) to split LDO side from load side"}
- {n: 3, stage: bare board, do: "first flash AP-DFU1: tack R1.1 PH3 (2.58, 3.85) B to +3V0 C1.1 (6.92, 0.83) B (5.3 mm wire; TP4 on F also works before the bond); 5 V current-limited on J3/J4, USB D+/D- on J10/J11; power-cycle; flash; remove tack. Then SWD on TP1/TP2/TP3/TP5 once, while F is still reachable", expect: "ROM DFU enumerates; image runs after tack removed; SWD attaches", fail: "AP-SWD if DFU fails (DBG-1); TP4 = Vref sense only, never drive a probe's 3.3 V into it; check NRST idles high"}
- {n: 4, stage: bare board, do: "clocks: LSE, MSI lock, PLL; scope MIC_CLK at R2.2 (B)", expect: "duty 48-52 % above 2.4 MHz (D13)", fail: "E6/R13: MDF fallback via TP8/TP9/TP10 (mdf_fallback above)"}
- {n: 5, stage: bare board, do: "pad board (or any LED) on J7/J8; press SW1; printf on TP7 (3.3 V-logic USB-UART RX)", expect: "LED on/off from PB7; +1.36 mA while pressed; PA0 high; TP7 text", fail: "LED dark = reversed"}
- {n: 6, stage: bare board, do: "USB: CDC enumerates; boot-stub jump to ROM DFU and re-flash over USB (O18); repeat with 2.95 V on TP4 (R20 lifted); meter C13.1 and TP10 in DFU (PB4 back-feed); DFU session > 160 s with charger watchdog armed (sub-power)", fail: "sub-dock-usb USB-at-3.0 V issue"}
- {n: 7, stage: bare board, do: "I2C2: read U3 at 0x6A (exercises the In2 SCL run); write register plan; charge the real cell; log via self-test", ref: "sub-power"}
- {n: 8, stage: "board bonded to the lid (TP1-TP6 now gone), lid lifted", do: "mic: PA5 on, 4 MHz; stream to PC through the real duct", expect: "spectrogram of HC-SR04 40 kHz (spec L574); duct resonance near 63 kHz visible (sub-audio-in)"}
- {n: 9, stage: same, do: "bridge: 8-12 Ω resistor on J1/J2 first (electronics.md A.5), low level; then exciter; |Z| sweep low amplitude; PWM-noise A/B", fail: "lift R21 (B) to rule the bridge out"}
- {n: 10, stage: same + puck fitted, do: "Off: Stop 2, PPK2 in series", expect: "≈15.5-22.7 µA (sub-power off_D12; derived, unmeasured)", fail: "+1.36 mA = SW1 pre-pressed: refit the puck (sub-ui issue 1)"}
- {n: 11, do: "only then close and seal (physical.md assembly order)"}
```
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

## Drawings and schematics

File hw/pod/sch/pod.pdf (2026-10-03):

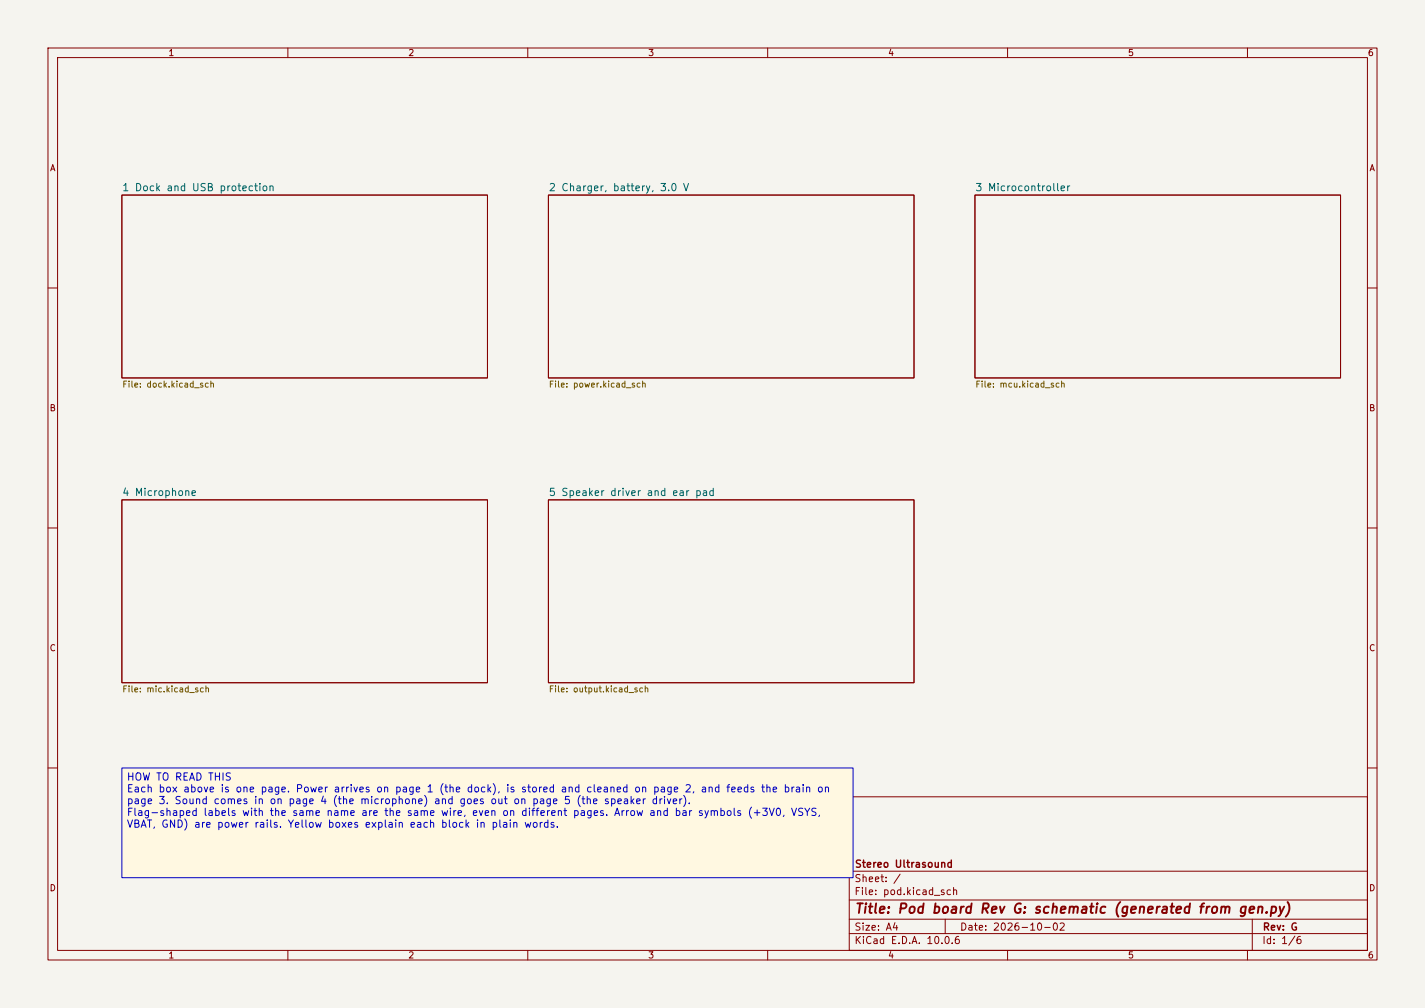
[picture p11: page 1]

1 Dock and USB protection

3 Microcontroller File: mcu.kicad_sch 4 Microphone

HOW TO READ THIS
Each box above is one page. Power arrives on page 1 (the dock), is stored and cleaned on page 2, and feeds the brain on
page 3. Sound comes in on page 4 (the microphone) and goes out on page 5 (the speaker driver).
Flag-shaped labels with the same name are the same wire, even on different pages. Arrow and bar symbols (+3V0, VSYS,
VBAT, GND) are power rails. Yellow boxes explain each block in plain words.

Stereo Ultrasound
Sheet: /
File: pod.kicad_sch
Title: Pod board Rev G: schematic (generated from gen.py)

Size: A4 | Rev: G
KiCad E.D.A. 10.0.6 | Id: 1/6

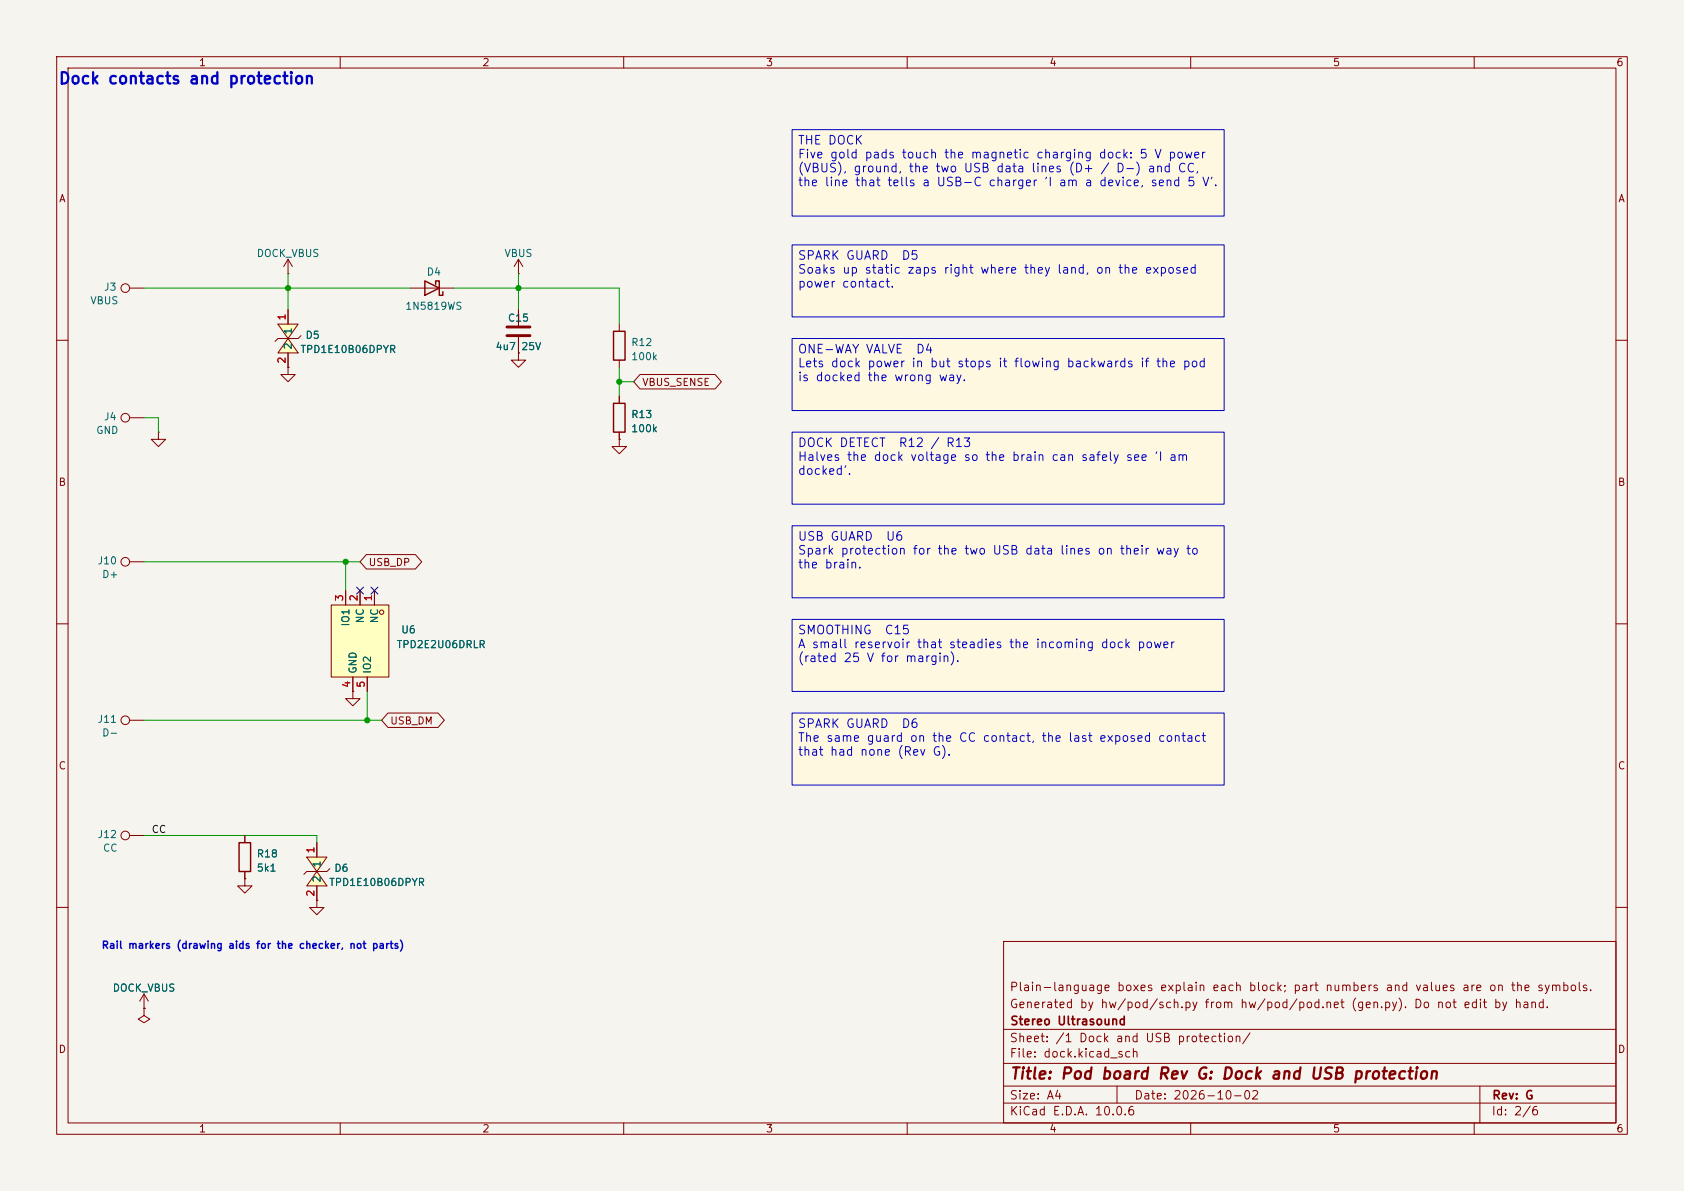
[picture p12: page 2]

Dock contacts and protection
VBUS NC

THE DOCK
Five gold pads touch the magnetic charging dock: 5 V power
(VBUS), ground, the two USB data lines (D+ / D-) and CC,
the line that tells a USB-C charger 'I am a device, send 5 V'.

SPARK GUARD D5
Soaks up static zaps right where they land, on the exposed
power contact.

ONE-WAY VALVE D4
Lets dock power in but stops it flowing backwards if the pod
is docked the wrong way.

DOCK DETECT R12 / R13
Halves the dock voltage so the brain can safely see 'I am
docked'.

USB GUARD U6
Spark protection for the two USB data lines on their way to
the brain.

SMOOTHING C15
A small reservoir that steadies the incoming dock power
(rated 25 V for margin).

SPARK GUARD D6
The same guard on the CC contact, the last exposed contact

that had none (Rev G). Rail markers (drawing aids for the checker, not parts)

Stereo Ultrasound
Sheet: /1 Dock and USB protection/
File: dock.kicad_sch
Title: Pod board Rev G: Dock and USB protection

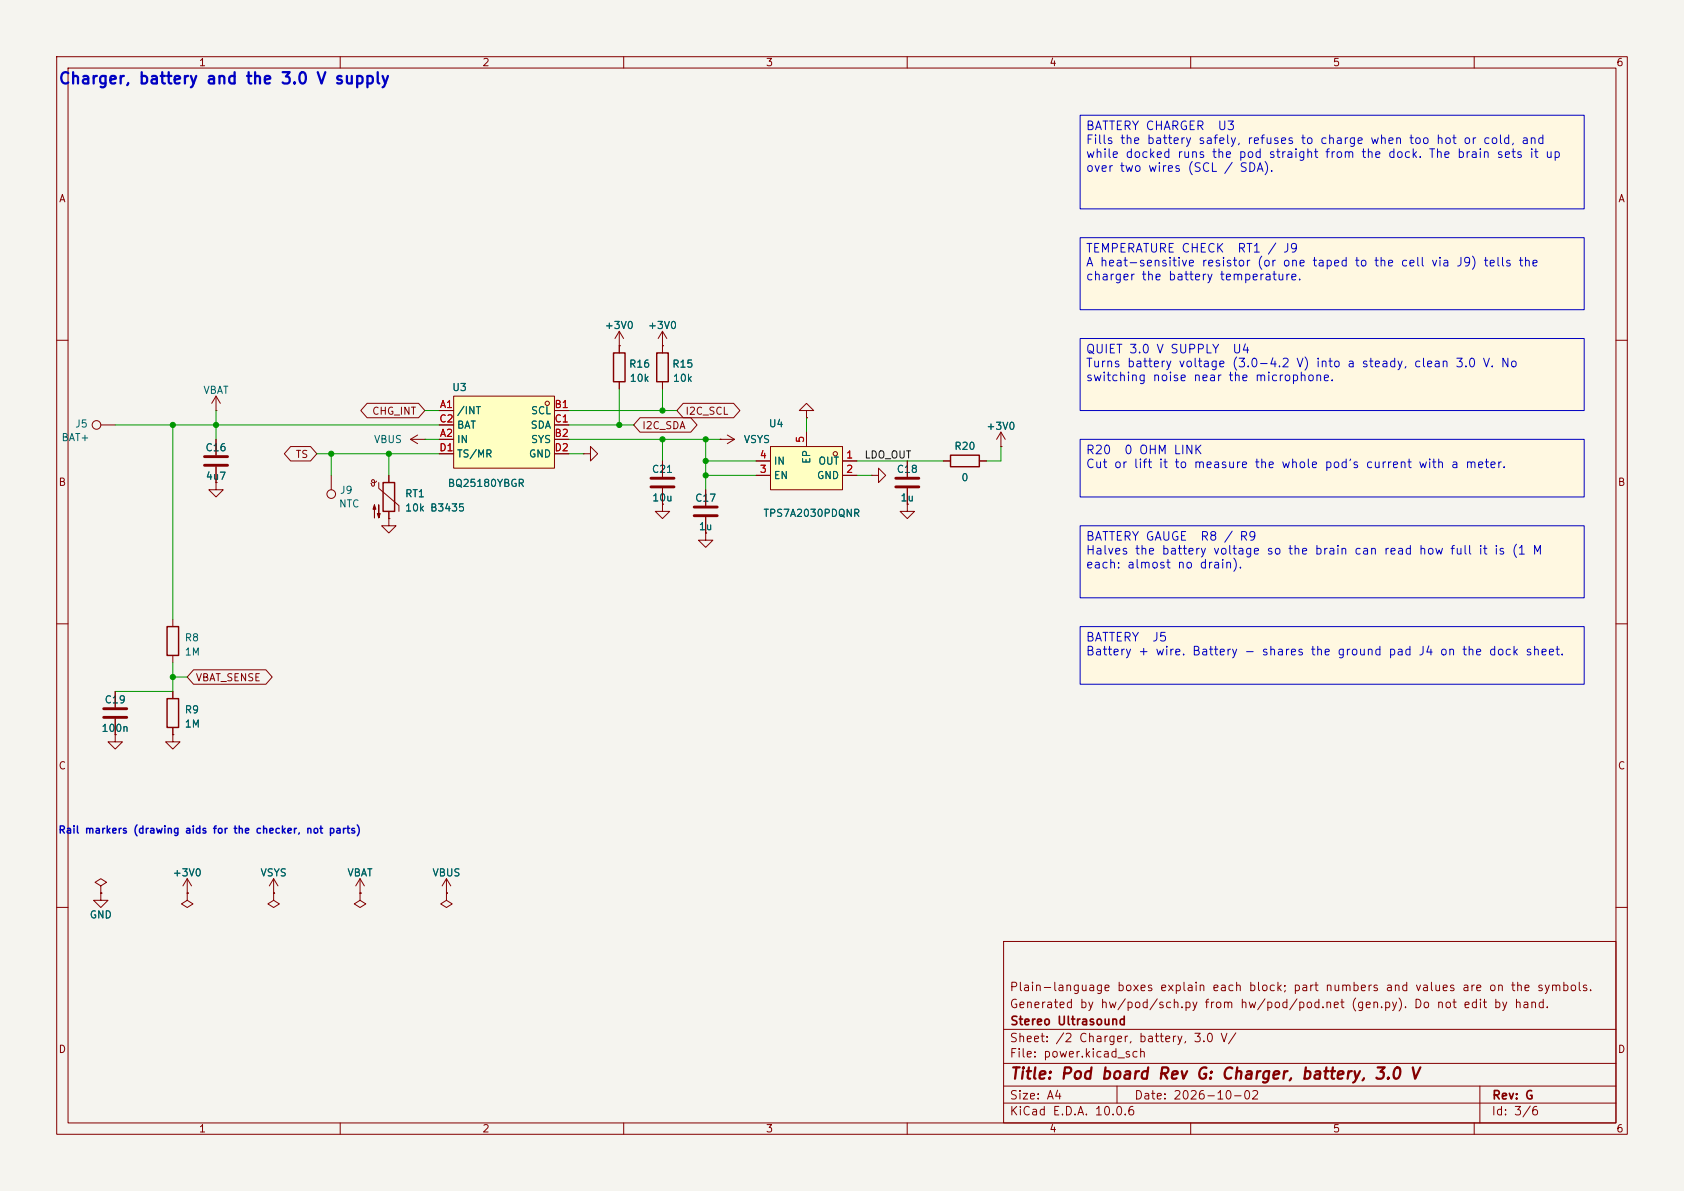
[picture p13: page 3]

Charger, battery and the 3.0 V supply

Fills the battery safely, refuses to charge when too hot or cold, and
while docked runs the pod straight from the dock. The brain sets it up
over two wires (SCL / SDA).

TEMPERATURE CHECK RT1 / J9
A heat-sensitive resistor (or one taped to the cell via J9) tells the
charger the battery temperature.

QUIET 3.0 V SUPPLY U4
Turns battery voltage (3.0-4.2 V) into a steady, clean 3.0 V. No
switching noise near the microphone.

R20 0 OHM LINK
Cut or lift it to measure the whole pod's current with a meter.

BATTERY GAUGE R8 / R9
Halves the battery voltage so the brain can read how full it is (1 M
each: almost no drain).

BATTERY J5
Battery + wire. Battery - shares the ground pad J4 on the dock sheet.

Generated by hw/pod/sch.py from hw/pod/pod.net (gen.py). Do not edit by hand.
Stereo Ultrasound
Sheet: /2 Charger, battery, 3.0 V/
File: power.kicad_sch
Title: Pod board Rev G: Charger, battery, 3.0 V

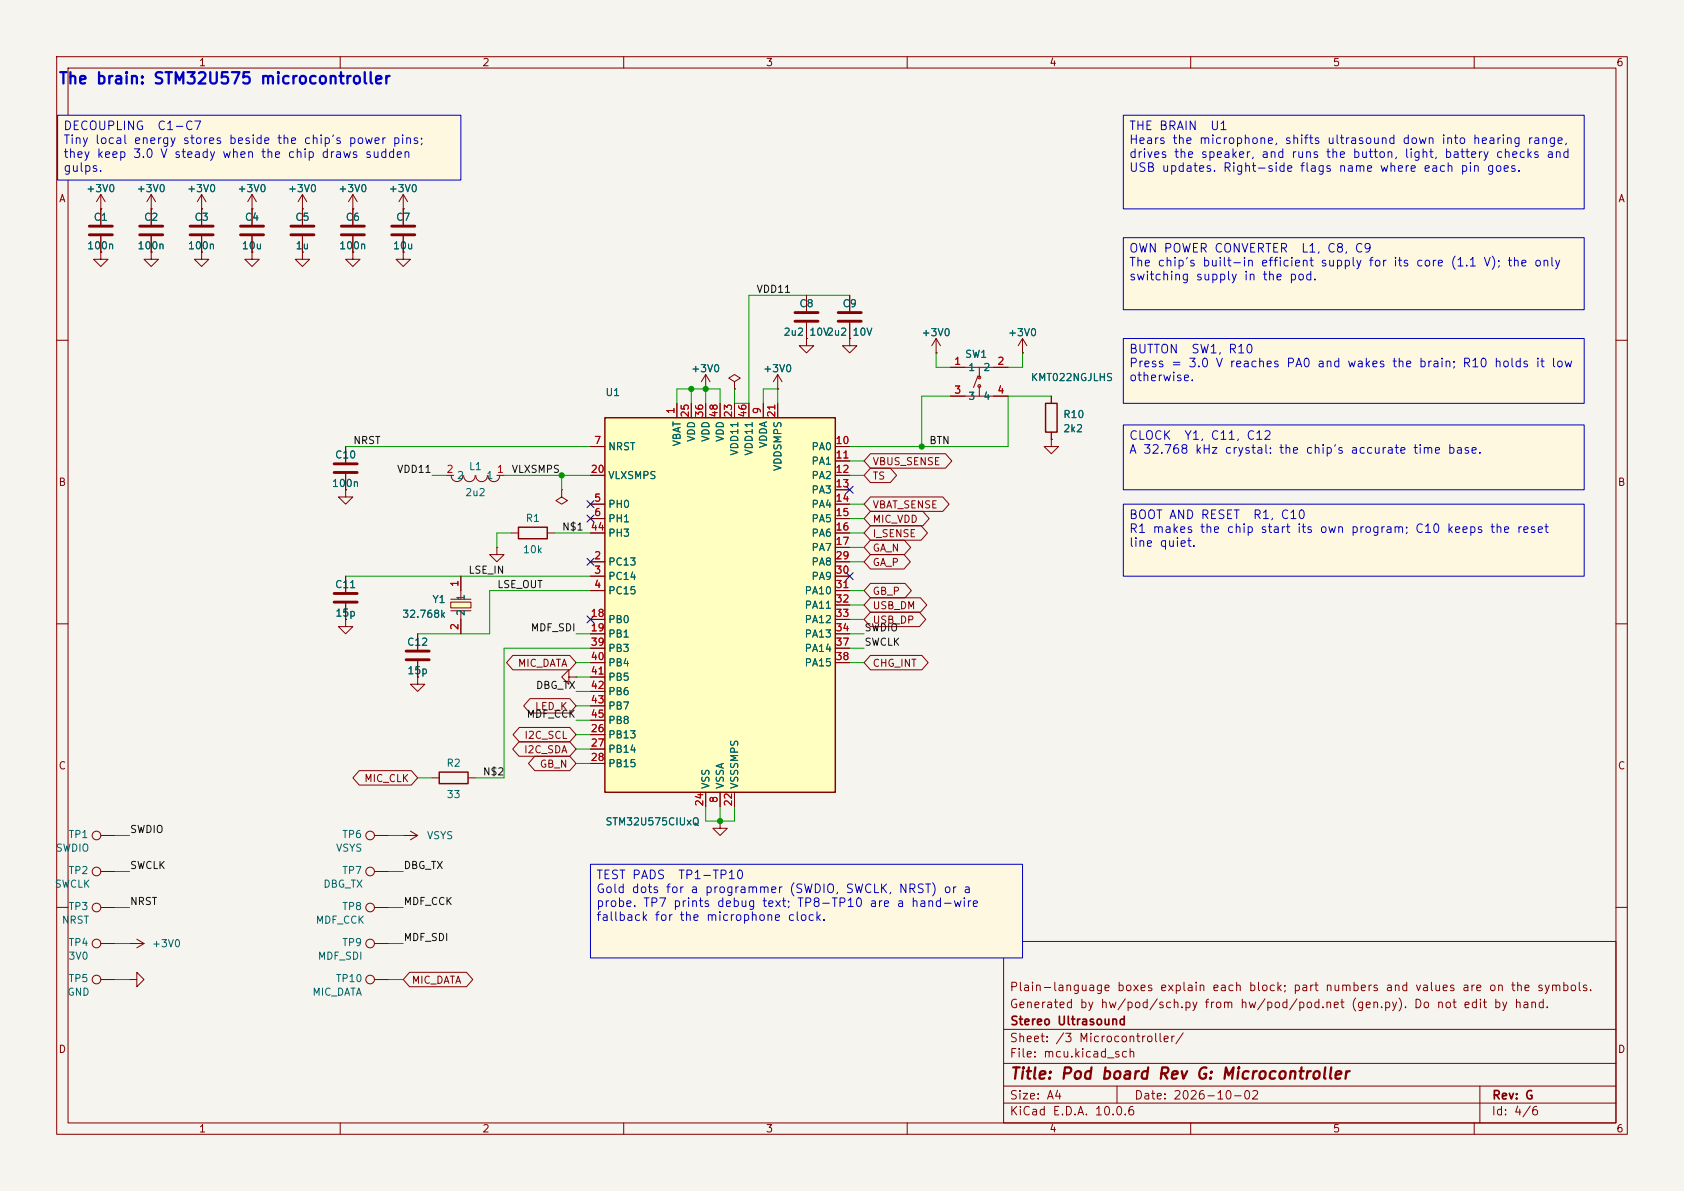
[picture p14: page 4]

DECOUPLING C1-C7
Tiny local energy stores beside the chip's power pins;
they keep 3.0 V steady when the chip draws sudden
gulps.

THE BRAIN U1
Hears the microphone, shifts ultrasound down into hearing range,
drives the speaker, and runs the button, light, battery checks and
USB updates. Right-side flags name where each pin goes.

OWN POWER CONVERTER L1, C8, C9
The chip's built-in efficient supply for its core (1.1 V); the only
switching supply in the pod.

BUTTON SW1, R10
Press = 3.0 V reaches PA0 and wakes the brain; R10 holds it low
otherwise.

CLOCK Y1, C11, C12
A 32.768 kHz crystal: the chip's accurate time base.

BOOT AND RESET R1, C10
R1 makes the chip start its own program; C10 keeps the reset
line quiet.

TEST PADS TP1-TP10
Gold dots for a programmer (SWDIO, SWCLK, NRST) or a
probe. TP7 prints debug text; TP8-TP10 are a hand-wire
fallback for the microphone clock.

Plain-language boxes explain each block; part numbers and values are on the symbols.
Generated by hw/pod/sch.py from hw/pod/pod.net (gen.py). Do not edit by hand.
Stereo Ultrasound
Sheet: /3 Microcontroller/
File: mcu.kicad_sch
Title: Pod board Rev G: Microcontroller

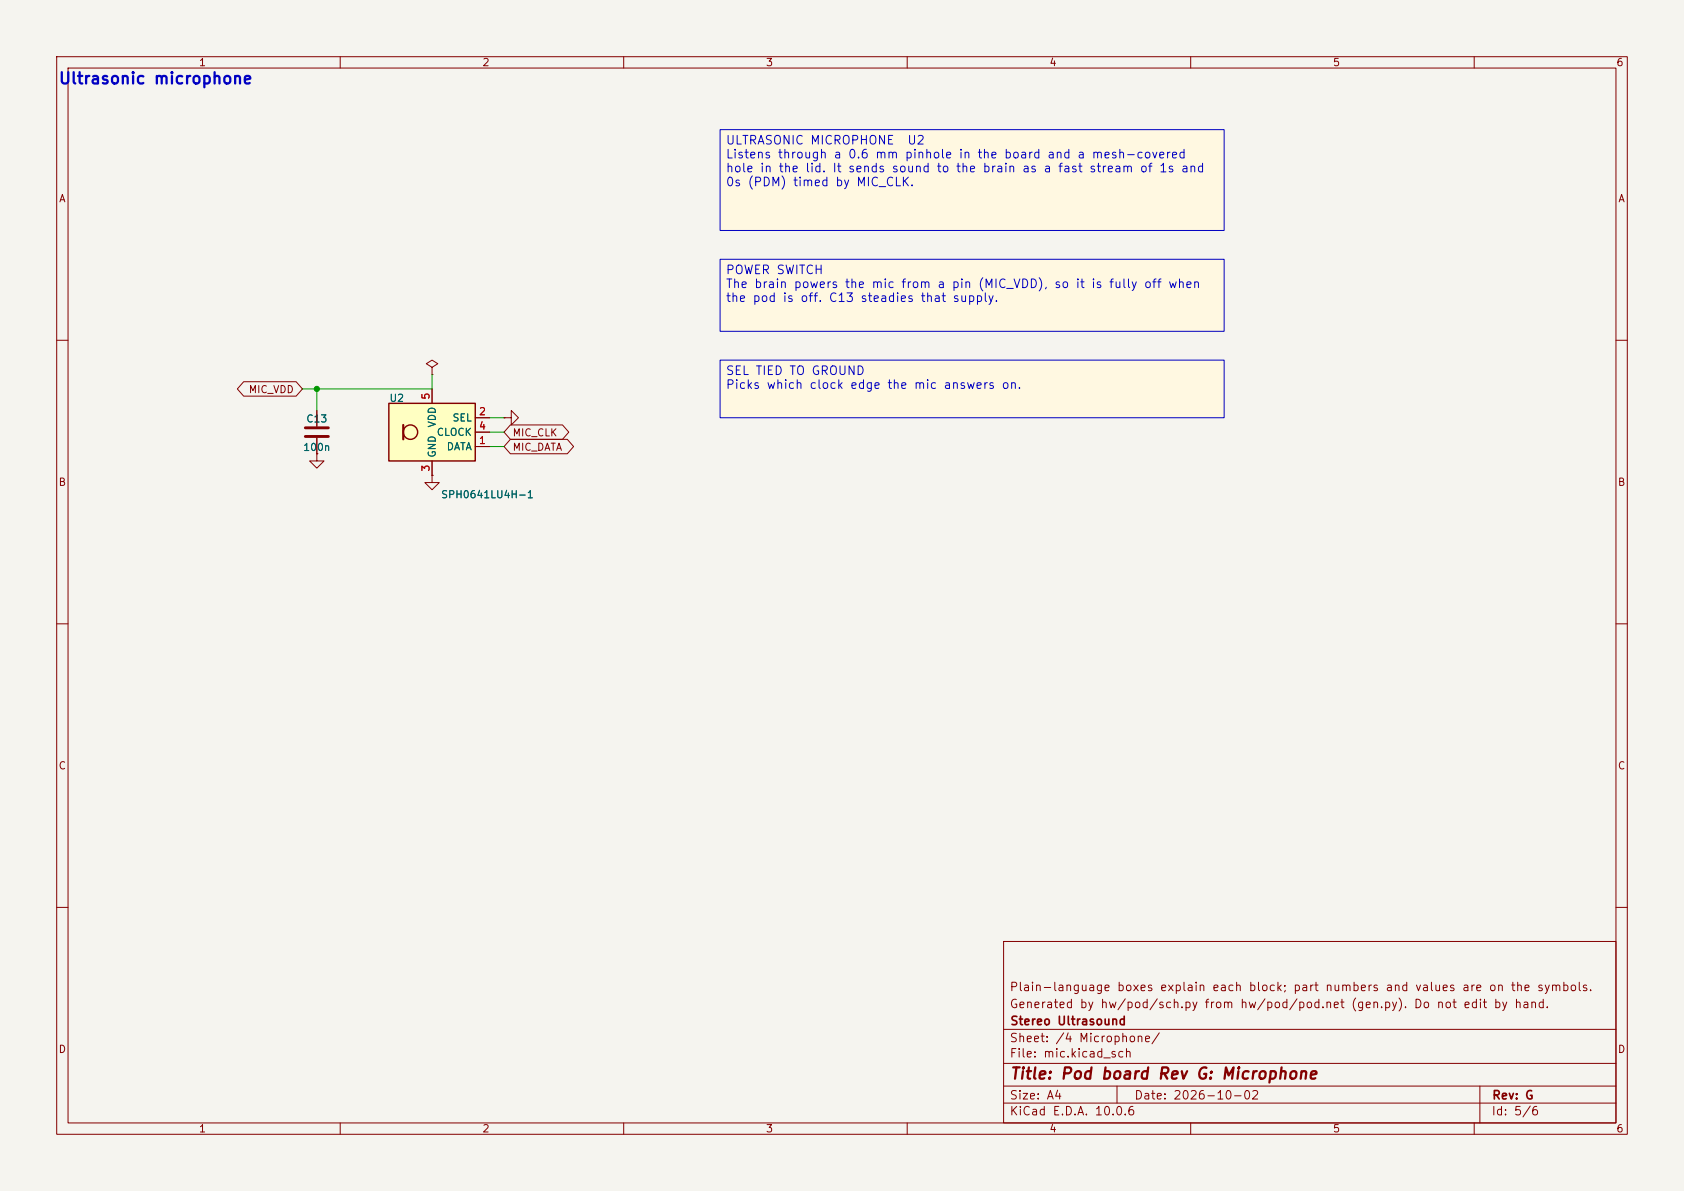
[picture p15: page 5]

Picks which clock edge the mic answers on. Ultrasonic microphone

Listens through a 0.6 mm pinhole in the board and a mesh-covered
hole in the lid. It sends sound to the brain as a fast stream of 1s and
0s (PDM) timed by MIC_CLK.

POWER SWITCH
The brain powers the mic from a pin (MIC_VDD), so it is fully off when
the pod is off. C13 steadies that supply.

SEL TIED TO GROUND

Plain-language boxes explain each block; part numbers and values are on the symbols.
Generated by hw/pod/sch.py from hw/pod/pod.net (gen.py). Do not edit by hand.
Stereo Ultrasound
Sheet: /4 Microphone/
File: mic.kicad_sch
Title: Pod board Rev G: Microphone

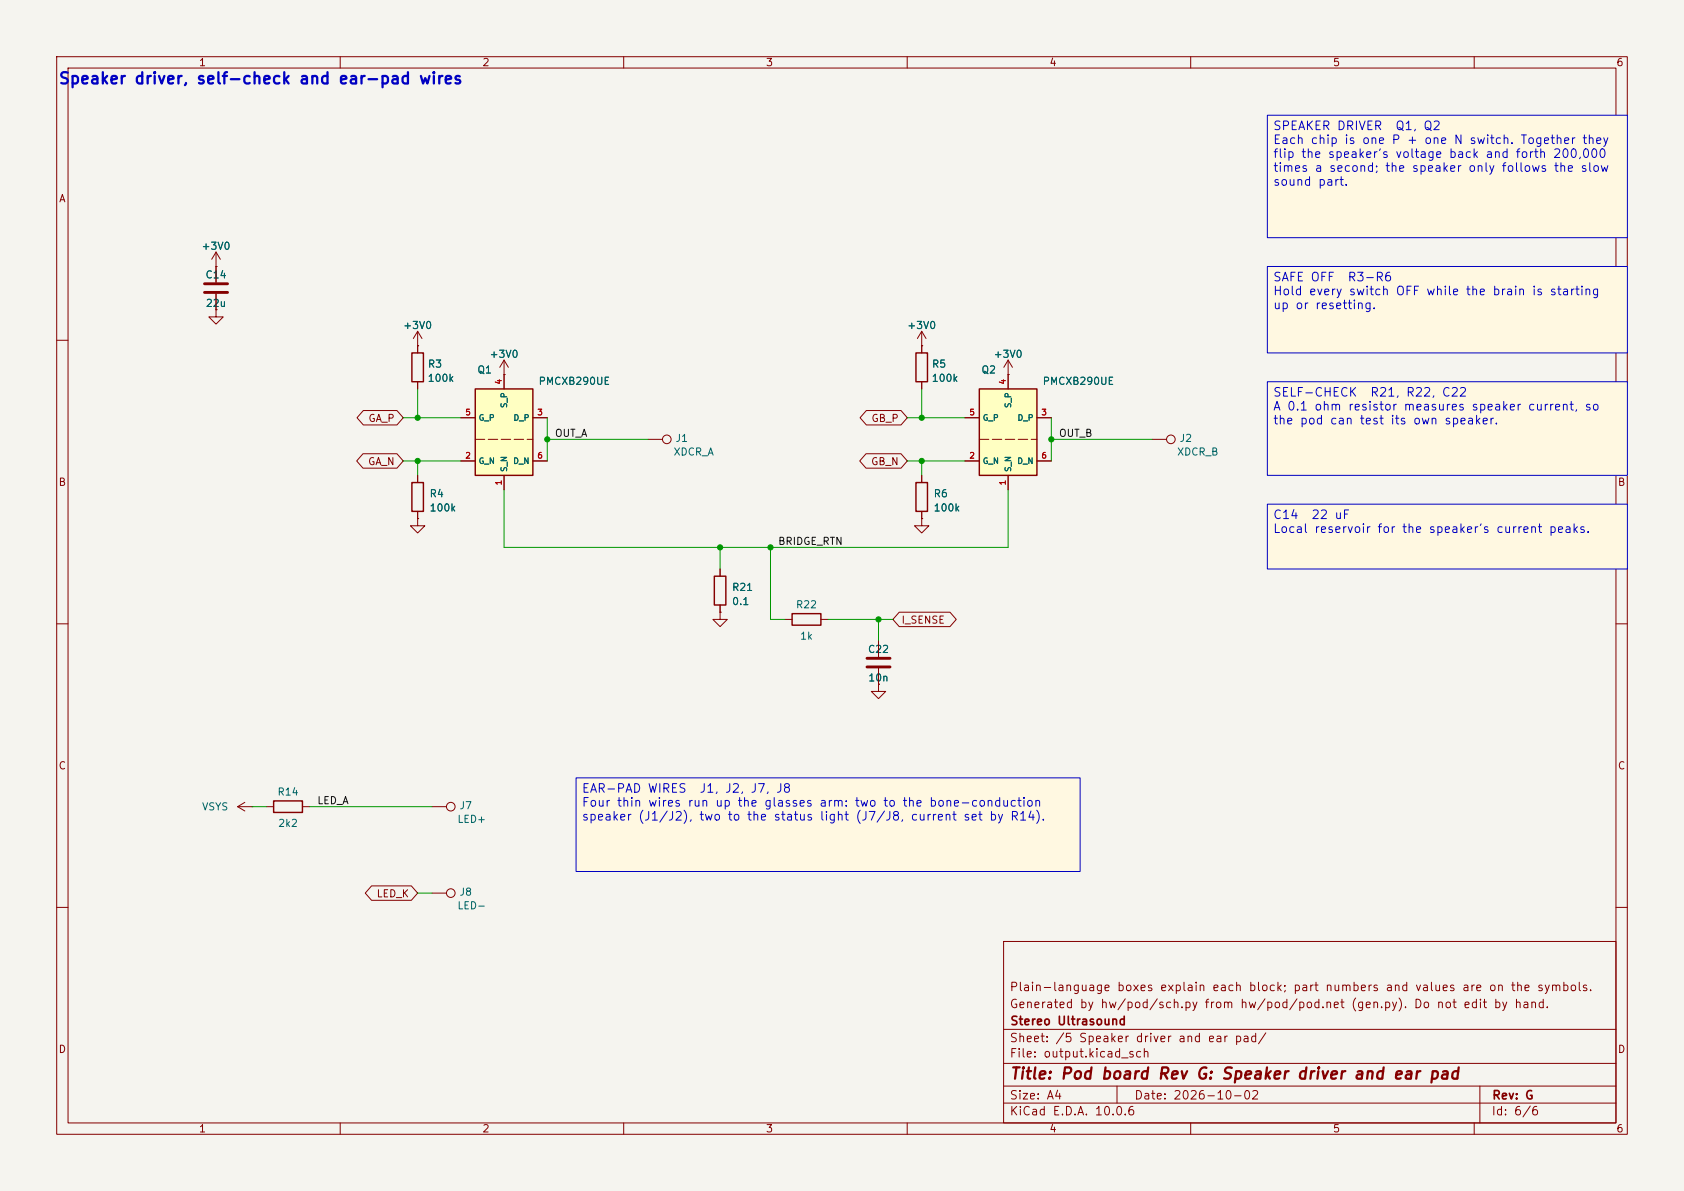
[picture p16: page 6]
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

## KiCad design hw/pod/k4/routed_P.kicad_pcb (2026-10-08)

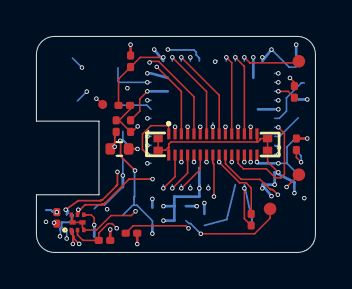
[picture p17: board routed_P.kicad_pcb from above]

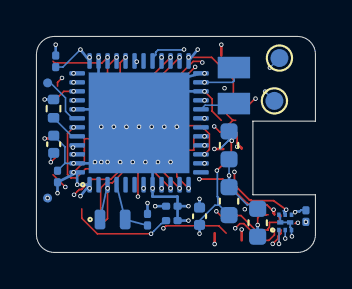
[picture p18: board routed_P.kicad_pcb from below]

Board: 6 copper layers, 15.5 x 12.0 mm, 37 parts (20 on the bottom side), 35 nets.

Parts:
C1, C2, C3, C6, C10: 100n; C_0201_0603Metric
C4, C7: 10u; C_0603_1608Metric
C5: 1u; C_0402_1005Metric
C8: 2u2 10V; C_0402_1005Metric
C9: 2u2 10V; C_0201_0603Metric
C11, C12: 8p2; C_0201_0603Metric
C14: 22u; C_0603_1608Metric
C22: 10n; C_0201_0603Metric
J1: XDCR_A; TestPoint_Pad_D1.0mm
J2: XDCR_B; TestPoint_Pad_D1.0mm
J21: BM28B0.6-30DP/2-0.35V(51); BM28B0.6-30DP_2-0.35V
L1: 2u2; L0806
Q1, Q2: PMCXB290UE; Nexperia_SOT1216_DFN1010B-6
R1: 10k; R_0402_1005Metric
R2: 33; R_0201_0603Metric
R3, R4, R5, R6: 100k; R_0201_0603Metric
R21: 0.1; R_0402_1005Metric
R22: 1k; R_0201_0603Metric
R23: 1M; R_0201_0603Metric
TP1: SWDIO; TestPoint_Pad_D0.7mm
TP2: SWCLK; TestPoint_Pad_D0.7mm
TP3: NRST; TestPoint_Pad_D0.7mm
TP7: DBG_TX; TestDot_D0.5mm
TP8: MDF_CCK; TestDot_D0.5mm
TP9: MDF_SDI; TestDot_D0.5mm
U1: STM32U575CIUxQ; QFN-48-1EP_7x7mm_P0.5mm_EP5.6x5.6mm
Y1: 32.768k 7pF; Crystal_SMD_2012-2Pin_2.0x1.2mm

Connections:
+3V0: C1.1, C2.1, C3.1, C4.1, C5.1, C6.1, C7.1, C14.1, J21.15, J21.30, J21.31, J21.32, J21.33, J21.34, Q1.4, Q2.4, R3.2, R5.2, R23.1, U1.1, U1.9, U1.21, U1.25, U1.36, U1.48
BRIDGE_RTN: Q1.1, Q2.1, R21.1, R22.1
BTN: J21.25, U1.10
CHG_INT: J21.23, U1.38
DBG_TX: TP7.1, U1.42
GA_N: Q1.2, R4.1, U1.17
GA_P: Q1.5, R3.1, U1.29
GB_N: Q2.2, R6.1, U1.28
GB_P: Q2.5, R5.1, U1.31
GND: C1.2, C2.2, C3.2, C4.2, C5.2, C6.2, C7.2, C8.2, C9.2, C10.2, C11.2, C12.2, C14.2, C22.2, J21.2, J21.4, J21.6, J21.8, J21.10, J21.12, J21.14, J21.16, J21.17, J21.18, J21.20, J21.22, J21.24, J21.26, J21.28, R1.2, R4.2, R6.2, R21.2, U1.8, U1.22, U1.24, U1.35, U1.41, U1.47, U1.49
I2C_SCL: J21.7, U1.26
I2C_SDA: J21.9, U1.27
I_SENSE: C22.1, R22.2, R23.2, U1.16
LED_K: J21.19, U1.43
LSE_IN: C11.1, U1.3, Y1.1
LSE_OUT: C12.1, U1.4, Y1.2
MDF_CCK: TP8.1, U1.45
MDF_SDI: TP9.1, U1.19
MIC_CLK: J21.3, R2.2
MIC_DATA: J21.21, U1.40
MIC_VDD: J21.1, U1.15
unnamed: R1.1, U1.44
unnamed: R2.1, U1.39
NRST: C10.1, TP3.1, U1.7
OUT_A: J1.1, Q1.3, Q1.6, Q1.7, Q1.8
OUT_B: J2.1, Q2.3, Q2.6, Q2.7, Q2.8
SWCLK: TP2.1, U1.37
SWDIO: TP1.1, U1.34
TS: J21.29, U1.12
USB_DM: J21.11, U1.32
USB_DP: J21.13, U1.33
VBAT_SENSE: J21.5, U1.14
VBUS_SENSE: J21.27, U1.11
VDD11: C8.1, C9.1, L1.2, U1.23, U1.46
VLXSMPS: L1.1, U1.20

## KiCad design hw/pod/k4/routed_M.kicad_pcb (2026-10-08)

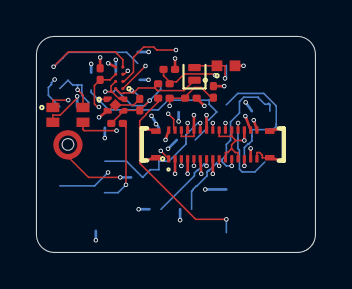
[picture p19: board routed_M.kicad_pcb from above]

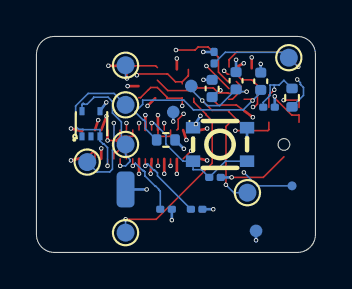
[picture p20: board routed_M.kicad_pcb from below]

Board: 6 copper layers, 15.5 x 12.0 mm, 38 parts (24 on the bottom side), 22 nets.

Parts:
C13, C19: 100n; C_0201_0603Metric
C15: 4u7 25V; C_0402_1005Metric
C16: 2u2 10V; C_0201_0603Metric
C17: 1u 16V; C_0201_0603Metric
C18: 1u; C_0402_1005Metric
C21: 10u; C_0402_1005Metric
D4: PMEG3005EL; D_SOD-882
D5: TPD1E10B06DPYR; X1SON-2_L1.0-W0.6-P0.65-BI-1
J3: VBUS; TestPoint_Pad_D1.0mm
J4: GND; WirePad_1.0x2.0mm
J5: BAT+; TestPoint_Pad_D1.0mm
J7: LED+; TestPoint_Pad_D1.0mm
J8: LED-; TestPoint_Pad_D1.0mm
J9: NTC; TestPoint_Pad_D1.0mm
J10: D+; TestPoint_Pad_D1.0mm
J11: D-; TestPoint_Pad_D1.0mm
J20: BM28B0.6-30DS/2-0.35V(51); BM28B0.6-30DS_2-0.35V
R8, R9: 1M; R_0201_0603Metric
R10, R14: 2k2; R_0201_0603Metric
R12, R13: 100k; R_0201_0603Metric
R15, R16: 10k; R_0201_0603Metric
R20: 0; R_0402_1005Metric
R30: 33; R_0402_1005Metric
RT1: 10k B3435; R_0201_0603Metric
SW1: KMT022NGJLHS; SW-SMD_4P-L3.0-W2.6-P1.85-LS3.4
TP4: 3V0; TestPoint_Pad_D0.7mm
TP5: GND; TestPoint_Pad_D0.7mm
TP6: VSYS; TestPoint_Pad_D0.7mm
TP10: MIC_DATA; TestDot_D0.5mm
U2: SPH0641LU4H-1; Knowles_LGA-5_3.5x2.65mm_Port0.65
U3: BQ25180YBGR; DSBGA-8_L1.6-W0.9-R2-C4-P0.40-BL
U4: TPS7A2030PDQNR; X2SON-4_L1.0-W1.0-P0.65-TL-EP
U6: TPD2E2U06DRLR; SOT-553-5_L1.6-W1.2-P0.50-LS1.6-TL-1

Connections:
+3V0: J20.15, J20.30, J20.31, J20.32, J20.33, J20.34, R15.2, R16.2, R20.2, SW1.1, SW1.2, TP4.1
BTN: J20.25, R10.1, SW1.3, SW1.4
CHG_INT: J20.23, U3.A1
DOCK_VBUS: D4.2, D5.1, J3.1
GND: C13.2, C15.2, C16.2, C17.2, C18.2, C19.2, C21.2, D5.2, J4.1, J20.2, J20.4, J20.6, J20.8, J20.10, J20.12, J20.14, J20.16, J20.17, J20.18, J20.20, J20.22, J20.24, J20.26, J20.28, R9.2, R10.2, R13.2, RT1.2, TP5.1, U2.2, U2.3, U3.D2, U4.2, U4.5, U6.4
I2C_SCL: J20.7, R15.1, U3.B1
I2C_SDA: J20.9, R16.1, U3.C1
LDO_OUT: C18.1, R20.1, U4.1
LED_A: J7.1, R14.2
LED_K: J8.1, J20.19
MIC_CLK: J20.3, U2.4
MIC_DATA: J20.21, TP10.1, U2.1
MIC_VDD: J20.1, R30.1
MIC_VDDF: C13.1, R30.2, U2.5
TS: J9.1, J20.29, RT1.1, U3.D1
USB_DM: J11.1, J20.11, U6.5
USB_DP: J10.1, J20.13, U6.3
VBAT: C16.1, J5.1, R8.1, U3.C2
VBAT_SENSE: C19.1, J20.5, R8.2, R9.1
VBUS: C15.1, D4.1, R12.1, U3.A2
VBUS_SENSE: J20.27, R12.2, R13.1
VSYS: C17.1, C21.1, R14.1, TP6.1, U3.B2, U4.3, U4.4

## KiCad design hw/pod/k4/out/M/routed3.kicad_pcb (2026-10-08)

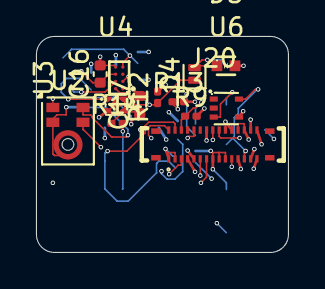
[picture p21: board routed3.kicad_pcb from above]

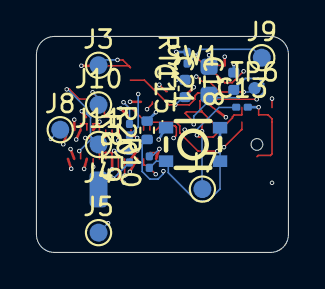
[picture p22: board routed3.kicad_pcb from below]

Board: 6 copper layers, 14.0 x 12.0 mm, 32 parts (19 on the bottom side), 21 nets.

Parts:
C13, C19: C_0201_0603Metric
C15, C16, C17, C18: C_0402_1005Metric
C21: C_0603_1608Metric
D4: D_SOD-882
D5: X1SON-2_L1.0-W0.6-P0.65-BI-1
J3, J5, J7, J8, J9, J10, J11: TestPoint_Pad_D1.0mm
J4: WirePad_1.0x2.0mm
J20: CONN-SMD_BM28B0.6-30DS-2-0.35V-51; BM28B0.6-30DS_2-0.35V
R8, R9, R10, R12, R13, R14: R_0201_0603Metric
R20: R_0402_1005Metric
RT1: R_0201_0603Metric
SW1: SW-SMD_4P-L3.0-W2.6-P1.85-LS3.4
TP6: TestPoint_Pad_D0.7mm
U2: Knowles_LGA-5_3.5x2.65mm; Knowles_LGA-5_3.5x2.65mm_Port0.65
U3: DSBGA-8_L1.6-W0.9-R2-C4-P0.40-BL
U4: X2SON-4_L1.0-W1.0-P0.65-TL-EP
U6: SOT-553-5_L1.6-W1.2-P0.50-LS1.6-TL-1

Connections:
+3V0: J20.17, J20.18, J20.19, R20.2, SW1.1, SW1.2
BTN: J20.29, R10.1, SW1.3, SW1.4
CHG_INT: J20.27, U3.A1
DOCK_VBUS: D4.2, D5.1, J3.1
GND: C13.2, C15.2, C16.2, C17.2, C18.2, C19.2, C21.2, D5.2, J4.1, J20.1, J20.2, J20.4, J20.5, J20.8, J20.9, J20.10, J20.12, J20.14, J20.15, J20.16, J20.20, J20.21, J20.24, R9.2, R10.2, R13.2, RT1.2, U2.2, U2.3, U3.D2, U4.2, U4.5, U6.4
I2C_SCL: J20.23, U3.B1
I2C_SDA: J20.25, U3.C1
LDO_OUT: C18.1, R20.1, U4.1
LED_A: J7.1, R14.2
LED_K: J8.1, J20.30
MIC_CLK: J20.3, U2.4
MIC_DATA: J20.7, U2.1
MIC_VDD: C13.1, J20.6, U2.5
TS: J9.1, J20.22, RT1.1, U3.D1
USB_DM: J11.1, J20.13, U6.5
USB_DP: J10.1, J20.11, U6.3
VBAT: C16.1, J5.1, R8.1, U3.C2
VBAT_SENSE: C19.1, J20.28, R8.2, R9.1
VBUS: C15.1, D4.1, R12.1, U3.A2
VBUS_SENSE: J20.26, R12.2, R13.1
VSYS: C17.1, C21.1, R14.1, TP6.1, U3.B2, U4.3, U4.4

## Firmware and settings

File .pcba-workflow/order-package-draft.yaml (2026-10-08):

status: DRAFT - NOT FROZEN. Nothing is ordered (O21). Owner places every order.
queue_item: B-ORDER-PACKAGE
drafted: 2026-10-07 (session date); JLC query_utc below
jlc_query_utc:
- 2026-10-08T00:57Z
source:
  bom: hw/pod/bom_jlc_mz2.csv (Phase-2 MZ-2, hw/current.yaml)
  price_tool: tools/jlc.py (JLCPCB parts API)
  alternates: .pcba-workflow/sourcing-lock.csv
  note: 'bom_check.py not run: needs the full KiCad/SKiDL harness; BOM read directly'
assumptions:
- 'One board design serves both pods (O16). JLC PCBA minimum 5 boards: 2 worn + 3 spares, so spares are whole boards and every line is qty x 5.'
- Standard (non-economic) PCBA charges a feeder fee per BOM line, Basic or Extended (JLC help, Sep 2026); extended-fee total not computed here.
- Prices are qty-1 and first 3 breaks; at 5 boards the lowest break reached is shown by price_breaks.
- 'Re-run tools/jlc.py at order time: stock moves daily.'
single_source_flags:
  MCU: 'STM32U575CIU6Q C5271013: live stock very low (26); reserve first, ECR-0008 option C fallback on paper only'
  mic: Knowles SPH0641LU4H-1 C2879853 (stock ~1049), no alternate
  cell: 'Renata ICP501233PA-02: no public price, quote needed'
  exciter: 'RC-BC02: marketplace only, listings unsaved, impedance 8 vs 12 ohm unknown (E1)'
  NiTi: Kellogg's W-NITI-0.75-SE only source costed
  VHB: 3M VHB 4914 0.25 mm only candidate (retention + duct seal)
  mesh: Saatifil Acoustex 042 (42 rayl, 29 % open, 46 um) via distributor (marianinc.com TDS); hydrophobic treatment open
jlc_lines:
- refs: C1,C10,C13,C19,C2,C3,C6
  lcsc: C76934
  part: 100 nF decoupling cap 0201 (Murata GRM033R61A104KE15D)
  mpn_live: GRM033R61A104KE15D
  qty_per_board: 7
  boards_assumed: 5
  qty_total_5_boards: 35
  library: Extended
  stock_live: 891913
  price_usd_qty1: 0.0039
  price_breaks:
  - - 1
    - 0.0039
  - - 1000
    - 0.0029
  - - 3000
    - 0.0025
  stock_ok_for_order: true
  alternate: 'none in lock: any same-value/package part of the same class (re-check at order time)'
  single_source: false
- refs: C11,C12
  lcsc: C161441
  part: 8.2 pF C0G 0201 cap, crystal load (Murata)
  mpn_live: GRM0335C1H8R2BA01D
  qty_per_board: 2
  boards_assumed: 5
  qty_total_5_boards: 10
  library: Extended
  stock_live: 23841
  price_usd_qty1: 0.0043
  price_breaks:
  - - 1
    - 0.0043
  - - 1000
    - 0.0034
  - - 3000
    - 0.0029
  stock_ok_for_order: true
  alternate: 'none in lock: any same-value/package part of the same class (re-check at order time)'
  single_source: false
- refs: C14
  lcsc: C59461
  part: 22 uF 0603 bulk cap (Samsung)
  mpn_live: CL10A226MQ8NRNC
  qty_per_board: 1
  boards_assumed: 5
  qty_total_5_boards: 5
  library: Basic
  stock_live: 7919093
  price_usd_qty1: 0.0311
  price_breaks:
  - - 1
    - 0.0311
  - - 200
    - 0.0233
  - - 600
    - 0.0199
  stock_ok_for_order: true
  alternate: 'none in lock: any same-value/package part of the same class (re-check at order time)'
  single_source: false
- refs: C15
  lcsc: C2858031
  part: 4.7 uF 25 V 0402 charger-input cap (Murata)
  mpn_live: GRM155R61E475ME15D
  qty_per_board: 1
  boards_assumed: 5
  qty_total_5_boards: 5
  library: Extended
  stock_live: 122900
  price_usd_qty1: 0.0833
  price_breaks:
  - - 1
    - 0.0833
  - - 100
    - 0.0717
  - - 300
    - 0.0659
  stock_ok_for_order: true
  alternate: 'none in lock: any same-value/package part of the same class (re-check at order time)'
  single_source: false
- refs: C16
  lcsc: C23733
  part: 4.7 uF 0402 cap (Samsung CL05A475)
  mpn_live: CL05A475MP5NRNC
  qty_per_board: 1
  boards_assumed: 5
  qty_total_5_boards: 5
  library: Basic
  stock_live: 2212818
  price_usd_qty1: 0.0166
  price_breaks:
  - - 1
    - 0.0166
  - - 500
    - 0.0128
  - - 1500
    - 0.0112
  stock_ok_for_order: true
  alternate: 'none in lock: any same-value/package part of the same class (re-check at order time)'
  single_source: false
- refs: C22
  lcsc: C85930
  part: 10 nF 0201 cap (Murata)
  mpn_live: GRM033R71E103KE14D
  qty_per_board: 1
  boards_assumed: 5
  qty_total_5_boards: 5
  library: Extended
  stock_live: 513766
  price_usd_qty1: 0.0047
  price_breaks:
  - - 1
    - 0.0047
  - - 1000
    - 0.0037
  - - 3000
    - 0.0032
  stock_ok_for_order: true
  alternate: 'none in lock: any same-value/package part of the same class (re-check at order time)'
  single_source: false
- refs: C21,C4,C7
  lcsc: C19702
  part: 10 uF 10 V 0603 SMPS-input cap (Samsung)
  mpn_live: CL10A106KP8NNNC
  qty_per_board: 3
  boards_assumed: 5
  qty_total_5_boards: 15
  library: Basic
  stock_live: 9773561
  price_usd_qty1: 0.0319
  price_breaks:
  - - 1
    - 0.0319
  - - 200
    - 0.0249
  - - 600
    - 0.0213
  stock_ok_for_order: true
  alternate: 'C315248 CL05A106MP5NUNC (Extended, lock stock 524766 2026-09-30T06:48Z): 0402 10 V X5R, Extended (smaller)'
  single_source: false
- refs: C17,C18,C5
  lcsc: C52923
  part: 1 uF 0402 cap (Samsung)
  mpn_live: CL05A105KA5NQNC
  qty_per_board: 3
  boards_assumed: 5
  qty_total_5_boards: 15
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

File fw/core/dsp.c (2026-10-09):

/* fw/core/dsp.c: DSP chain (see dsp.h). Mirrors sim/dsp/pipeline.py algo_b / algo_a and sim/e2e/stages.py PwmShaper; deviations
 * from the float64 reference are listed in docs/sim/firmware-emulation.yaml FWSIM-R13/R14 status. */
#include "dsp.h"

#include <math.h>
#include <string.h>

#include "dsp_math.h"
#include "hal_fmac.h"

#define NOINL __attribute__((noinline))
#define FS_HZ 200000.0f
#define FS_OUT_HZ 12500.0f
#define BIN_HZ 781.25f                     /* 200 kHz / 256 */
#define INC_PER_HZ_INT 343597u             /* 2^32 / 12500 = 343597.38368 */
#define INC_PER_HZ_FRAC 0.38368f
#define HOP 128u
#define UP 16u

static const float hann[FW_DSP_HANN_N] = FW_DSP_HANN_INIT;
static const float eq2[FW_DSP_EQ2_N] = FW_DSP_EQ2_INIT;
static const float noise_spec[FW_DSP_NOISE_SPEC_N] = FW_DSP_NOISE_SPEC_INIT;
static const float noise_slim[FW_DSP_NOISE_SLIM_N] = FW_DSP_NOISE_SLIM_INIT;
static const float tw128[FW_DSP_TW128_N] = FW_DSP_TW128_INIT;
static const float twr256[FW_DSP_TWR256_N] = FW_DSP_TWR256_INIT;
static const float interp[FW_DSP_INTERP_N] = FW_DSP_INTERP_INIT;   /* [16][TPP] */
static const float hb[FW_DSP_HB_N] = FW_DSP_HB_INIT;
static const float a_hp[FW_DSP_A_HP_N] = FW_DSP_A_HP_INIT;
static const float a_h1[FW_DSP_A_H1_N] = FW_DSP_A_H1_INIT;
static const float a_h2[FW_DSP_A_H2_N] = FW_DSP_A_H2_INIT;
static const float ntf_2cos[FW_DSP_NTF_2COS_N] = FW_DSP_NTF_2COS_INIT;
static const float geo_spec[FW_DSP_GEO_SPEC_N] = FW_DSP_GEO_SPEC_INIT;
static const float geo_slim[FW_DSP_GEO_SLIM_N] = FW_DSP_GEO_SLIM_INIT;
static const float mapgeo_spec[FW_DSP_MAPGEO_SPEC_N] = FW_DSP_MAPGEO_SPEC_INIT;
static const float mapgeo_slim[FW_DSP_MAPGEO_SLIM_N] = FW_DSP_MAPGEO_SLIM_INIT;
static const float a_noise_sm[FW_DSP_A_NOISE_SM_N] = FW_DSP_A_NOISE_SM_INIT;

_Static_assert(FW_DSP_INTERP_N == 16u * FW_INTERP_TPP, "interpolator table shape");
_Static_assert(FW_DSP_A_H1_N == 16u && FW_DSP_A_H2_N == 40u, "algorithm A decimators 16 + 40 taps (pipeline.a_decimators)");
_Static_assert(FW_DSP_NOISE_SPEC_N == FW_DSP_NB_MAX, "spec B has 28 bands (FWSIM-R10 taps)");
_Static_assert(FW_INTERP_REJ_DB_X10 >= 670, "interpolator image rejection >= 67 dB into 8-16 kHz (FWSIM-R14 F5)");

/* Hz -> phase increment per 12.5 kS/s sample (2^32 = one turn); integer part exact */
static uint32_t hz_to_inc(float f)
{
    if (!(f > 0.0f))
        return 0u;
    uint32_t fi = (uint32_t)f;
    float ff = f - (float)fi;
    return fi * INC_PER_HZ_INT + (uint32_t)((float)fi * INC_PER_HZ_FRAC + ff * (343597.38368f) + 0.5f);
}

static float map_freq(const fw_dsp_t *d, float f)   /* pipeline.map_freq: log compression f_lo..f_hi -> out_lo..out_hi */
{
    if (f < d->f_lo)
        f = d->f_lo;
    if (f > d->f_hi)
        f = d->f_hi;
    return d->out_lo * fw_exp2f(d->k_map * fw_log2f(f / d->f_lo));
}

void fw_dsp_init(fw_dsp_t *d, const fw_knobs_t *k, uint32_t arr, uint32_t reps)
{
    memset(d, 0, sizeof *d);
    d->algo = k->algo == 1 ? (uint32_t)FW_ALGO_A : (uint32_t)FW_ALGO_B;
    d->slim = k->b_variant == 1 ? 1u : 0u;
    d->nb = d->slim ? FW_DSP_NOISE_SLIM_N : FW_DSP_NOISE_SPEC_N;
    d->ramp_len = d->slim ? 16u : 8u;
    d->ramp_shift = d->slim ? 4u : 3u;
    d->transient = k->transient_only ? 1u : 0u;
    d->arr = arr;
    d->reps = reps;
    d->dither_on = k->dither_on ? 1u : 0u;
    d->hold_samples = (uint32_t)k->squelch_hold_ms * 25u / 2u;   /* 12.5 samples per ms */
    float frame_s = (float)(d->slim ? 2u * HOP : HOP) / FS_HZ;
    d->om_up = fw_om_exp(frame_s * 1000.0f / (float)k->floor_up_ms);
    d->om_dn = fw_om_exp(frame_s * 1000.0f / (float)k->floor_down_ms);
    d->a_up = 1.0f - d->om_up;
    d->a_dn = 1.0f - d->om_dn;
    d->gate_lin = fw_db20_to_lin((float)k->gate_cdb * 0.02f);        /* 10^(gate_db/10) as power ratio */
    d->margin_lin = fw_db20_to_lin((float)k->noise_margin_cdb * 0.02f);
    d->gain_lin = fw_db20_to_lin((3000.0f + (float)k->volume_cdb) * 0.01f);   /* pipeline gain_db 30 + volume */
    d->a_att = fw_om_exp(frame_s * 1.0e6f / (float)k->env_attack_us);
    d->a_rel = fw_om_exp(frame_s * 1.0e6f / (float)k->env_release_us);
    d->f_lo = (float)k->band_lo_hz;
    d->f_hi = (float)k->band_hi_hz;
    d->out_lo = (float)k->out_lo_hz;
    float lr = fw_log2f(d->f_hi / d->f_lo);
    d->k_map = fw_log2f((float)k->out_hi_hz / d->out_lo) / lr;
    float bc = 1.0f;                                              /* binomial coefficients C(k_map, n), n = 1..5 */
    for (uint32_t i = 0; i < 5u; i++) {
        bc = bc * (d->k_map - (float)i) / (float)(i + 1u);
        d->mk[i] = bc;
    }
    /* band edges f_lo * (f_hi/f_lo)^(i/nb) (np.geomspace); bin k is in band b if edge[b] <= k*781.25 < edge[b+1] (np.digitize) */
    float edge[FW_DSP_NB_MAX + 1u];
    for (uint32_t i = 0; i <= d->nb; i++)
        edge[i] = i == 0u ? d->f_lo : (i == d->nb ? d->f_hi : d->f_lo * fw_exp2f(lr * (float)i / (float)d->nb));
    d->bin_lo = 0u;
    d->bin_hi = 0u;
    for (uint32_t kb = 0; kb < sizeof d->band_of_bin; kb++) {
        float f = (float)kb * BIN_HZ;
        uint8_t b = 255u;
        if (kb <= 128u && f >= edge[0] && f < edge[d->nb]) {
            uint32_t j = 0;
            while (j + 1u < d->nb && f >= edge[j + 1u])
                j++;
            b = (uint8_t)j;
            if (d->bin_hi == 0u)
                d->bin_lo = kb;
            d->bin_hi = kb + 1u;
        }
        d->band_of_bin[kb] = b;
    }
    for (uint32_t n = 0; n < 128u; n++) {
        uint32_t r = 0;
        for (uint32_t bit = 0; bit < 7u; bit++)
            r |= ((n >> bit) & 1u) << (6u - bit);
        d->rev[n] = (uint8_t)r;
    }
    for (uint32_t b = 0; b <= d->nb; b++) {                       /* first bin of each band (bins of a band are contiguous) */
        uint32_t kb = d->bin_lo;
        while (kb < d->bin_hi && d->band_of_bin[kb] < b)
            kb++;
        d->band_start[b] = (uint8_t)kb;
    }
    for (uint32_t b = 0; b < d->nb; b++) {
        d->geo[b] = sqrtf(edge[b] * edge[b + 1u]);
        d->noise[b] = d->slim ? noise_slim[b] : noise_spec[b];
        d->inc_prev[b] = hz_to_inc(map_freq(d, d->geo[b]));      /* pipeline: f_prev = map_freq(geometric centres) */
        d->map_geo[b] = map_freq(d, d->geo[b]);
        if (FW_DSP_MAP_DEFAULTS(k->band_lo_hz, k->band_hi_hz, k->out_lo_hz, k->out_hi_hz)) {   /* exact tables (dsp_tables.h) */
            d->geo[b] = d->slim ? geo_slim[b] : geo_spec[b];
            d->map_geo[b] = d->slim ? mapgeo_slim[b] : mapgeo_spec[b];
            d->inc_prev[b] = hz_to_inc(d->map_geo[b]);
        }
        d->inv_geo[b] = 1.0f / d->geo[b];
    }
    /* algorithm A */
    d->a_lo_inc = (uint32_t)((((uint64_t)(uint32_t)k->a_lo_hz << 32) + 100000u) / 200000u);   /* round(f 2^32 / 200 kHz), exact */
    d->a_gate_lin = fw_db20_to_lin((float)k->gate_cdb * 0.01f);
    d->a_noise_thr = a_noise_sm[0] * fw_db20_to_lin((float)k->noise_margin_cdb * 0.01f);   /* gate floor: mic self-noise + margin */
    d->a_up_s = fw_om_exp(1000.0f / ((float)k->floor_up_ms * FS_OUT_HZ));
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

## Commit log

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2026-09-30 Pod board schematic in SKiDL: netlist, JLC BOM (41 parts, all with LCSC), draft placement
    ERC 0 errors. STM32U575 on its SMPS, mic on ADF PB3/PB4 powered from
    PA5, 2x PMCXB290UE bridge with gate pulls, MCP73831 + TPS7A2030, SWD
    pads. place.py fits everything on 20x10 mm, two-sided, no courtyard
    overlaps (feasibility draft; the owner does the real layout).
    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
    [bom_jlc.csv]
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2026-09-30 Draft route run 2: 0 DRC errors, 8 connections unrouted; render script; 150-pass rerun in progress
    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
    [pod_placed.kicad_pcb, pod_routed.kicad_pcb]
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2026-09-30 Self-contained KiCad 10 project of the draft pod board (local LCSC libs + 3D models via KIPRJMOD, README of known issues)
    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
    [bom_jlc.csv, pod.kicad_pcb]
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2026-09-30 Pod schematic Rev B: audit wiring fixes
    - MCP73832 (open-drain STAT, JLC C38066) replaces MCP73831: PA10 no longer
    sees the charger's 5 V (NM-1); 100k pull-up to +3V0
    - VBUS sense on PA1 (100k/100k): firmware knows it is docked, sleeps, and
    the charger can terminate (PWR-05)
    - C4 10 uF 0603 (AN5373 VDD bulk, NM-7); R1 BOOT0 10k (NM-11); C20 100 nF
    at VBAT (NM-5)
    ERC 0 errors; 45 parts, all with LCSC numbers.
    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
    [bom_jlc.csv]
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2026-09-30 Schematic Rev C: pad LED indicator; NiTi pre-set straight (no heat-set); real-light renders; PCB status map
    - O8 resolved (owner): LED solid as power indicator; VBAT -> R14 2k2
    (C25879, Basic, JLC 2026-09-30) -> J7/J8 pad wires -> PB7 open-drain.
    ERC 0 errors, 46 parts, all LCSC
    - Owner: NiTi bought straight + superelastic, NO heat-setting; direction
    from angled holes in heel and pad (tragus-arm.md, spec O7)
    - pad-led.md: build-ease notes (pre-wired LEDs, 0603 option, pad order)
    - render_styles.py: real lighting (bundled HDRI + soft key), NEON=1 keeps
    the old look; tries OptiX/CUDA, falls back to CPU
    - docs/diagrams/pcb-status.svg: where the pod PCB stands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
    [bom_jlc.csv]
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2026-10-01 Pod schematic Rev D: BQ25180 power-path charger + NTC, magnetic USB dock (D+/D-/CC, ESD, reverse-dock diode), IP68 KMT022 switch
    - U3 BQ25180YBGR (C3682423): IN=VBUS, SYS=VSYS (LDO + LED now on VSYS),
    BAT=cell, I2C PB13/PB14 + 10k pull-ups, /INT PA15, TS = NTC (RT1 + J9) also
    read on PA2; replaces MCP73832
    - Dock pads J3 VBUS (via D4 1N5819WS), J4 GND, J10 D+ -> PA12, J11 D- -> PA11
    (U6 TPD2E2U06), J12 CC with Rd 5k1 and 10k to PA3; PA10 keeps its pull-up
    - SW1 C&K KMT022NGJLHS (IP68, 1.6 N; datasheet: pads 1-2 / 3-4 common, min
    1 mA contact current -> R10 2k2 pull-down)
    - Fix: SKiDL searched '.' recursively and resolved 'lcsc' to the stale copy
    in hw/pod/kicad-draft; hw/lib/lcsc n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
    [bom.csv, bom_jlc.csv]
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2026-10-03 Rev F routed (Phase 1 board for owner review): ECR-0003 bridge leg B -> TIM1_CH3/CH3N on PA10/PB15 (verified in ST open pin data, AF1); charger cluster shifted +2.5 mm to give the MCU's top-right pin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
    [pod_r1_routed.kicad_pcb]
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2026-10-03 Silkscreen redesign + photo renders (owner: "make sure the silkscreen looks pretty"; translucent case parts considered)
    hw/pod/silk.py (post-route, idempotent, copper untouched; place_r1.py now runs it):
    - reference designators -> Fab layers (52 refs cannot meet JLC's 1.0 mm legend minimum on 34x13 mm)
    - footprint silk kept only for orientation-critical parts; library marks within 0.15 mm of a pad replaced by
    pin-1 dots placed clear of pads and package bodies (U1, U3, U4, U6)
    - top face: mic-port keep-clear ring + sound arcs; STEREO / ULTRASOUND / REV F name block; bottom: CELL SIDE
    - board rules raised to JLC legend minimums (jlcpcb.com capabilities, read 2026-10-02): text 1.0 mm, line 0.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
    [pod_r1_routed.kicad_pcb]
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2026-10-03 Generated circuit schematic (hw/pod/sch.py -> hw/pod/sch/): 5 functional sheets drawn from pod.net, connectivity proven
    Owner: "schematic-rev1 is a flowchart, keep it, but we want schematics too". gen.py (SKiDL) stays the source of
    truth and is untouched; sch.py lays its netlist out as a KiCad 10 schematic: dock + USB protection, charger/battery/
    3.0 V, MCU, microphone, speaker driver + ear-pad wires, plus an index page with a reading guide. Real library symbols
    (PMCXB290UE drawn here: gen.py defines it in code), +3V0/GND symbols per pin, other rails wired and named by one
    symbol per island, short orthogonal wires where they cross nothing, labels where they would; test pads in their own
    labe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
    [dock.kicad_sch, mcu.kicad_sch, mic.kicad_sch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]
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2026-10-03 Stage-C simulation: plans + scaffolds committed (e2e chain, layout noise, acoustics port + bone, firmware/emulation requirements, shared params, index)
    docs/sim/index.yaml = run order, status, permission list (installs only on triggers; licences re-read 2026-10-02).
    Rev F results (fenced 3 GB): e2e 5 PASS / 28 WARN (stubs) / 3 FAIL (DSP true peak -6.3 dBFS vs -12 ceiling);
    layout noise on Rev F (stale board now exits 1): 5/6, LN-M03 Kelvin 5.2 % FAIL, LN-M02 0.2 dB margin; acoustics:
    as-built open gap -15.4 dB; sealed duct ID 1.0 fails 20-85 kHz (+19.3 dB at 84.7 kHz), S1 stack passes; every sealed
    option needs a board x-stop (2.22 mm worst offset vs 0.2 allowed). Skeptic's 18 findings fixed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
    [params.yaml]
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2026-10-03 Rev G (ECR-0017, owner O24): C8/C9 back to 10 V-rated 2.2 uF C107369 (ST DS13737 Rev 10 p.153); D6 TPD1E10B06 ESD at the exposed CC contact J12 (same part/BOM line as D5)
    - gen.py Rev G: 53 placed parts, 30 BOM lines, ERC 0; bom_check identity + part_heights for C107369
    - board re-placed + routed (D6 on B behind J12, one via): 694 tracks, 118 vias, 1 unconnected (I2C_SDA, router
    variance), DRC 19 courtyard + 1 clearance 0.0892 vs 0.09 mm (router rounding); Phase-2 board supersedes it
    - schematic pages regenerated (D6 on the dock sheet, Rev G title): connectivity PASS, 195 memberships
    - tracker: new relations R-SMPS-BOARD, R-CLOCK-BOARD, R-UI-BOARD (miniaturization MZG-15 blind spot); all r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
    [bom.csv, bom_jlc.csv, dock.kicad_sch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]
2026-10-03 Phase 2 start (ECR-0018, owner O25/O26): package set MZ-2 "Balanced" as a gen.py variant (POD_PACKAGES=mz2 -> pod_mz2.net, bom_jlc_mz2.csv)
    29 parts to smaller packages with nets identical to Rev G (verified): 0201 resistors/caps/NTC (vetted set), R21 0402
    current sense (ERJ2BSFR10X), Y1 Epson FC-12M 2.0x1.2 7 pF with C11/C12 8.2 pF C0G (gmcrit ~0.98 vs 2.16 uA/V), D4
    PMEG3005EL SOD-882. Kept: R1/R20 hooks 0402, C8/C9 0402 10 V, bulk/25 V caps, L1, QFN48 MCU. All parts JLC-stocked
    (parts API 2026-10-03T03:57Z). Default build stays Rev G until the Phase-2 board replaces the draft.
    Claude-Session: https://claude.ai/code/session_01Wg997D6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
    [bom_jlc_mz2.csv]
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2026-10-03 Phase-2 parts in the checkers: heights (datasheet maxima: 0201 R 0.26, 0201 C/NTC 0.33, ERJ2B 0.40, SOD-882 0.50, FC-12M 0.60), bom_check identities and sourcing-lock rows (JLC API 2026-10-03T04:04Z)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
    [sourcing-lock.csv]
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2026-10-03 Phase 2 WIP board routed (draft_r2): 30 x 12 one-face, stack F sig / In1 GND / In2 +3V0 plane / B sig; 505 tracks, 130 vias, DRC 0 errors, 8 unconnected (U1 escapes: BTN, VBUS_SENSE, GB_P, MDF_CCK; F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
    - place_r2.py: In2 +3V0 plane + via fan-out (net_fanout), TP1-TP6 allowed on F (bare pads, bench access), via 0.35/0.15
    kept (0.30 broke the 0.2 mm hole clearance), fan-out on every part (skipping U1/U3/U4 routed worse)
    - the 51 mm +3V0 net was the router's main blocker on the first tries (7 -> 10 unconnected); the plane fixed it
    Claude-Session: https://claude.ai/code/session_01Wg997D6KFs8bxoAH56j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
    [placed.kicad_pcb, routed.kicad_pcb]
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2026-10-03 Phase 2 route: 0.11 mm routing clearance for both FreeRouting passes (0.10 produced 0.192 mm hole clearance); routed board DRC 0 errors, 7 unconnected (U1 top-row escapes NRST/BTN/VBUS_SENSE + LSE_OU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
    [placed.kicad_pcb, routed.kicad_pcb]
2026-10-03 Phase 2 board lettering: silk.py reads the port/button/outline from the board (one-face board: name block between the mic-port motif and SW1, 'PHASE 2'); pin-1 dot list in a sidecar; place_r2 --route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
    [routed.kicad_pcb]
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2026-10-03 Phase 2 route closure (agent v6): 1 unconnected (I2C_SCL at U1.26), DRC 0 errors, placement check pass: U1 top strip loosened (C2/C3/C10), C9 pocket fixed, Y1 vertical, TP3/TP6 moved on F; mic port n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
    [placed.kicad_pcb, routed.kicad_pcb]
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2026-10-07 Phase 2 board fully routed: 0 unconnected, DRC 0. I2C_SCL at U1.26 (boxed in on both outer faces) bridged 8.97 mm on the In2 +3V0 plane by new hw/pod/inner_bridge.py (maze route, plane stays one isla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
    [routed.kicad_pcb]
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2026-10-07 sim/noise models every plane (params board.planes: In1 GND + In2 +3V0; a plane without a filled zone is skipped and warned, so Rev F still runs). Phase-2 board results (out_r2, valid): LN-M01 26.5 dB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
    [params.yaml]
2026-10-07 LN-M03 Kelvin fix on the Phase-2 board: hw/pod/kelvin_r21.py (two pad-hugging GND vias at R21, 4 options scored). All layout-noise metrics now pass (M03 3.31 -> 1.29 %); DRC 0, 0 unconnected
    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
    [routed.kicad_pcb]
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2026-10-07 Layout noise defaults from hw/current.yaml: Phase-2 routed board + pod_mz2.net + bom_jlc_mz2.csv (ROUTED_CANDIDATES removed). smoke.sh exit 0, metrics == out_r2 (M01 26.5, M02 20.1, M03 1.29, M04 0.1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
    [params.yaml]
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2026-10-07 Checks default to hw/current.yaml (Phase 2): interfaces/bom_check read the r2 board, pod_mz2.net, bom_jlc_mz2.csv and dims_r2 shell facts; system_map.build applies the MZ-2 package set. Rev-G-specifi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
    [bom_jlc_mz2.csv]
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2026-10-07 Phase-2 board: B-DOC-AUDIT-0007 layout fixes 1-3 (local re-route of the committed board)
    - J3 DOCK_VBUS / J4 GND swapped: J4 now sits between J3 and J5 VBAT (ASM-09); J3-J5 gap 1.17 -> 2.80 mm, all wire-pad gaps >= 0.90
    - mic-port keep-out (R-ACO-P6): F.Cu rule area r 1.6 in place_r2 (FreeRouting + DRC enforce it), fan-out avoids it, check 'port';
    MDF_SDI re-routed: nearest F copper / via 1.35 -> 1.87 mm from the port
    - LSE: Y1/C11/C12 moved, C1 to the QFN corner; LSE_IN/LSE_OUT pre-routed on B (locked), 0 vias, 7.72 / 7.43 mm (was 2 vias each, F+B)
    - VDDA pin 9: C6 100 nF at the pin (1.13 mm, was 8.8), C5 1 uF 2.32 mm (was 9.2); C3 to VDD pin 36; C10 / R9 nudged; NEAR rules per pin
    - R21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
    [placed.kicad_pcb, routed.kicad_pcb]
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2026-10-07 V4: static cycle budgets on the U575 (fw/bench kernels + objdump counter); B at 55 MHz doesn't fit (61-71 MHz), slim B fits; nothing fits 24 MHz (A_q15 26-32 MHz)
    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
    [kernels.h]
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2026-10-07 FWSIM foundation (group a): portable fw/core behind fw/hal, host fakes, generated board/variant/knob config, R64 current clamp, fwsim gate
    - fw/core C11 (entry points pure of state+args+injected time; fw_hop ABI v1 frozen, silence stub),
    fw/hal 37 functions, fw/port_host stateful fakes (log, scripts, fault injection, flash power-fail/ECC),
    fw/port_u575 startup + linker + HAL stubs
    - fw/tools/gen.py: board_config.h from pin-contract + phase2 circuit + ST pin data (refuses on interfaces pins FAIL),
    variant_config.h (FWSIM-R64: PH2_175 270 mA, K1_130 208 mA), knobs_def.h (42 knobs, hard clamps), tables.h
    - dual-slot CRC knob store, survives a torn write at every flash step
    - fw/tools/fwsi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
    [app.c, fw.c]
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2026-10-07 FWSIM group b: DSP chain in fw/core (B spec + slim B knob, A, D1/D2 front ends, x16 interp + true-peak limiter + squelch + 3rd-order shaper), golden vectors + L0/L1
    - fw/core/dsp.c: algo_b mirror (Hann 256 FFT, mic EQ, log bands, floor/gate, envelopes, log2/exp2 frequency map, phase-continuous oscillator bank), slim B (16 bands, frames every 256 samples), algo A (LO mix, HP at 200k, 575-tap decimating FIR = reference filters reordered), D2 half-band, output stage (x16 polyphase TPP 10 = 70.2 dB images, instant-attack true-peak limiter, causal squelch, F2 shaper reset, TPDF xorshift dither) through fw_ccr_from_amp
    - fw/tools/dsp_tables.py -> fw/gen/dsp_tables.h (all filters from the sim refer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
    [dsp.c, fw.c]
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2026-10-07 FWSIM group b: fwsim dsp stage (R8 sha, L1, L0, R15 property, static cycles), L2 harness, A gate noise floor, inline sine/CCR
    - fw/tools/cycles.py: fw/bench cyccount CPI x gcov line counts (same core sources) per variant -> cycles_hop vs V4
    - sim/fw/l2.py: sim/e2e scenarios with FwDsp/FwShaper (firmware in the loop) vs the Python chain (B, slim, A), regression gate
    - algorithm A gate: threshold never below the mic self-noise envelope + noise_margin (T6 idle regression fixed)
    - fw_sin_turns and fw_ccr_from_amp inline (still the only CCR writer); fwsim 'dsp' rows in 'all' (23 rows PASS)
    Claude-Session: https://claude.ai/code/session_01Wg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
    [dsp.c]
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2026-10-07 FWSIM optimisation pass 1: B 152-195 -> 94-119 MHz, slim 108-141 -> 60-76, A 137-175 -> 73-94 (static, V4 overhead)
    - bit-identical algorithm: fused radix-2 stage pairs, window + bit-reverse in one pass, contiguous band accumulation,
    exact 32-bit synth ramp (q*kk + (r*kk)>>s), 2-half PCM ring, A doubled ring + 7-pair unroll
    - output stage: history in registers, one xorshift draw per period (TPDF from two 16-bit halves), floor by offset convert,
    integer CCR clamp FW_CCR_LEVEL_STORE (one-compare fast path; test_clamp_level_matches_amp)
    - cycles.py: prologue/epilogue at call count; hot inlines as macros so their cost lands on the caller line
    - goldens untouched (inputs + reference only): L1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
    [dsp.c]
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2026-10-07 FWSIM round 3: algorithm A two-stage 16+40-tap decimator in sim/dsp AND fw (lead decision), A goldens re-blessed; ARM L0 on QEMU mps2-an505 bit-exact; FFT/map optimisations
    - sim/dsp/pipeline.py: a_decimators() + algo_a_base() (causal: 16-tap /4, 40-tap /4, butter(2) HP at 12.5 kS/s); algo_a uses it
    - fw/core/dsp.c: A = same cascade (tables from pipeline via dsp_tables.py); bless delta sweep.A dsp_out_err -90.3 -> -93.8 dB (only A_y drifted)
    - ARM L0: fw/port_qemu (startup, an505.ld, semihosting driver) + sim/fw/l0_arm.py; 12/12 vector x variant runs bit-exact ARM vs host;
    shim runs with FTZ|DAZ like FPSCR.FZ; fwsim row dsp.L0.arm_qemu_vs_host (24 rows PASS)
    - B: frequency map as a 5th-ord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
    [dsp.c]
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2026-10-07 CHK-STOCK: sourcing lock covers every part the MZ-2 schematic uses (8 dated rows via tools/jlc.py); 12 unused RECOMMENDED rows marked SUPERSEDED; C48260 (D5/D6) promoted
    JLC parts API 2026-10-07T17:35-17:36Z rows for C17168 R20, C1972959 U6, C221707 SW1,
    C25744 R1 (was undated), C2858031 C15, C2879853 U2, C3682423 U3, C5271013 U1.
    bom_jlc_mz2.csv regenerated by gen.py (column 'dated lookup' -> 'yes'; parts unchanged;
    netlist unchanged). bom_check: lock-drift PASS; stock-lock WARN now only U1 stock 26
    (ECR-0008). plm 0/0/0/0.
    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
    [bom_jlc_mz2.csv, sourcing-lock.csv]
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2026-10-07 RB-19: routed board Value fields now hold the schematic values (74/74 from pod_mz2.net via pcbnew); geometry untouched
    git diff: only the 74 (property "Value" ...) lines. bom_check values WARN -> PASS.
    DRC before/after identical: 0 errors, 3 pre-existing warnings (1 hole_to_hole, 2
    via_dangling) -> new backlog item CHK-DRCWARN (router). plm 0/0/0/0.
    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
    [routed.kicad_pcb]
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2026-10-07 CHK-DRCWARN: 2 dangling vias deleted from the routed board (pcbnew, authorised); DRC 0 errors / 0 unconnected / 1 warning; noise metrics identical
    Deleted (only change to routed.kicad_pcb): GND via (23.875, 1.7), on the In1 plane with
    no F/B copper; NRST via (9.23, 1.24), the locked pre-via place_r2.py adds for pin 7 ->
    TP3, unused by the router (TP3 reached another way; next place_r2 run recreates it).
    kicad-cli DRC with schematic parity: 0 errors, 0 unconnected, parity 0, 1 warning.
    Remaining warning is real: hole_to_hole 0.109 mm between two +3V0 vias (11.37, 1.28) /
    (11.595, 1.152), 0.259 c-c, D0.15 drills, rule 0.25: same net (harmless electrically),
    drilling-web risk; fix at the next r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
    [routed.kicad_pcb]
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2026-10-07 FWSIM round 5: FMAC x16 interpolator path (+6 dB guard, hal_fmac backed by a bit-accurate FMAC model), CPU interpolator kept as A/B build option
    - fw/hal/hal_fmac.h hal_fmac_fir_bank: pure math accelerator, the one HAL family core entry points may call (test_abi_pure exemption)
    - fw/core/fmac_model.c: C twin of sim/fw/fmac_model.py (RM0456 s26.3.7; A1/A2 floor assumptions), bit-exact (fwsim row dsp.fmac_model_c_vs_py);
    used by the host fake, the QEMU port and the U575 port (until the register driver, E4)
    - fw/core/dsp.c FW_INTERP_FMAC=1 default: guard at 2 x ceiling, q1.15 at 0.999/(2 ceiling kappa), 16 phases x 10 taps, true-peak limiter after
    it on the CPU, CPU fallback on HAL error; F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
    [dsp.c]
2026-10-07 Board: redundant +3V0 via removed (hole-to-hole 0.109 mm) - DRC now 0 violations, 0 unconnected, parity 0; noise metrics identical
    The two +3V0 vias (11.37, 1.28) / (11.595, 1.152) both joined the same B-side copper
    (U1 pin 9 VDDA <-> C6 pad 1, linked on B) to the In2 plane. Deleted via d5fef857 and its
    0.86 mm stub from U1.9 (pcbnew, authorised); kept the via at C6 pad 1, so the supply path
    is plane -> via -> C6 -> pin 9 (decoupling cap before the pin).
    DRC (kicad-cli, schematic parity): 0 violations, 0 unconnected, parity 0 (was 1 warning).
    Noise smoke: LN-M01 26.5 dB, M02 20.1, M03 1.29 %, M04 0.1267 mV, M05 8.718 uV,
    M06 0.1074 mV, identical; layout-noise.yaml sha 36d088d4 -> 21bbe68f, 5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
    [routed.kicad_pcb]
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2026-10-07 FWSIM round 6: mode FSM (table from fw/spec/fsm.yaml), gestures as a knob table (option B), docked interlock, BQ25180 charger supervision, FWSIM-R64 on self-test/CDC paths, FWSIM-R65 break logic
    - fw/spec/fsm.yaml -> gen.py -> fw/gen/fsm_table.h (every state x event cell a transition or explicit ignore) -> fw/core/modes.c;
    1e6-step random walk: output / Off invariants 0 violations, all states reached and left; re-match in 2 presses for B and C (A needs 3)
    - gestures: debounce, short/double/hold1/hold2 recogniser, knob gesture_option (A/B/C), stuck button
    - FWSIM-R19: raw PA1 stops output at once, docked = PA1 OR charger VIN_PGOOD, variant (b) has no exemption code (nm rows)
    - fw/core/charg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
    [app.c, charger.c, dsp.c]
2026-10-07 FWSIM round 7: idle detector -> IDLE (default off: T2 recall finding), ticks, LED duty, Off/Stop 2 sequence + pin audit, awake fractions, U575 register layer GPIO + TIM1 PWM/break vs RM0456
    - fw/core/idle.c (pipeline.idle_detector_fft rev 2): active fractions match the reference on the e2e scenes (house 0.176/0.176,
    bats 0.763/0.741, self-noise 0.708/0.673, silence 0/0); Transient -> IDLE -> wake, Full never idles, 12-hop look-back.
    Finding: awake within 20 ms of only 73-75 % of Port Meadow calls (reference too) -> T2 recall 0.83 -> 0.56: idle_enable default 0
    - volume ticks (vol_idx+1 bursts, 2 kHz, -30 dBFS) through the output stage; LED duty toward led_target_ua via R14 from VSYS/VBAT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
    [app.c, dsp.c, fw.c]
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2026-10-07 Router batch (round 8): R23 1M I_SENSE offset (OUT-1B), TP2/TP4 swap (DBG-2), mic port D0.65 (SAI-15D) - local re-route, DRC 0/0/0 incl. warnings
    Schematic (gen.py, Phase-2 only so the Rev G reference stays frozen): R23 1M 0201
    (C473482, existing line) +3V0 -> I_SENSE. 100k was the first value but +3V0 stays up in
    Off and 100k drew 29.7 uA (> the 16.5-24 uA Off budget); 1M = 3.0 uA, +3.0 mV offset;
    selftest_lockin.py (now R_OFF env) at 1M: -12 dBFS |Z| 2.07 %, phase 0.89 deg (100k:
    1.91 / 0.73), min ADC input 2.7 mV (no negative samples).
    Mic: new footprint Knowles_LGA-5_3.5x2.65mm_Port0.65 (Port0.6 kept for Rev F): NPTH D0.65
    at local (0, 0.75) -> board (1.90, 6.0); +0.02 so pad 3 clearance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
    [bom.csv, bom_jlc_mz2.csv, routed.kicad_pcb]
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2026-10-07 FWSIM round 10a: PWM timing per clock plan - fw_arr_for_khz(pwm, plan) keeps f_pwm an exact integer multiple of fs_pcm at all 8 plans (illegal 800 kHz at P64/P48/P72/P52 falls back to 400), dead time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
    [app.c, dsp.c, fw.c]
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2026-10-07 FWSIM round 11: charger ILIM follows USB configuration (hal_usb_configured; 100 mA until configured, back on suspend/unplug), guarded DFU handoff (DOCKED_CHARGE only, settle, guards -> DFU_ABORT, cha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
    [app.c, fw.c]
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2026-10-07 FWSIM round 12a: USB suspend -> BQ25180 SYS_MODE 01 (IN disconnected, SYS from the cell; SLUSE99C 8.3.4) until resume, so the suspended port stays <= 2.5 mA (50 mA ILIM floor cannot); hal_usb_bus (no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
    [app.c, charger.c, fw.c]
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2026-10-08 ECR-0020: K4 two-board split (M/P), hw/pod/k4/gen.py emits two netlists + BM28 30-pin map; ERC 0 errors both; docs updated
    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
    [bom_jlc_M.csv, bom_jlc_P.csv]
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2026-10-08 K4 dock connector search (no stocked 4-pin fits; fallback = trim C5126844 flange), cell-to-lid clearance 0.05 -> 0.20 (tape 0.10)
    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
    [bom_jlc_M.csv, bom_jlc_P.csv]
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2026-10-08 K4 P unload experiment (5 parts P->M: TP4/5/10, R15/R16): P 1 open + 2 DRC; route_net3d.py 4-layer hand router; close_gaps guard; inner_bridge In3/In4. Partition change NOT adopted (M would need re-r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
    [routed_P_L15.5_unload5_1open_2drc.kicad_pcb]
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2026-10-08 K4 closure at L15.5: 5-part unload P->M + BM28 pins 26/27 swap (ECR-0020 rev 4); M and P both 0 open / 0 DRC / place PASS
    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
    [b3.dsn, base.kicad_pcb, board.dsn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]
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2026-10-08 K4 mic-supply filter: R30 33R + C13 on M (MIC_VDDF), k4_noise corrected (P mirror/flip, gap 0.6, JLC 6L stack K4-STACK6): worst-PSRR corner 8.0 dB unfiltered -> 26.4 dB filtered
    M re-placed/re-routed (place PASS, 0 unconnected, 0 DRC errors, ERC 0 errors both); P untouched. ECR-0020 rev 5, V9, backlog, vcrm pins, plm 0/0.
    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
    [board.dsn, board2.dsn, bom_jlc_M.csv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]
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2026-10-08 K4 lid ledge 0.70 (ECR-0022) + C21 0402: M re-routed 0/0, heights from datasheets: lid +0.112 floor +0.163 worst, B2B gap side still fails (C16 -0.10, C17/C9 -0.05)
    Noise F02->MIC_VDD worst corner 28.7 dB, k4_checks PASS, plm 0/0. P untouched.
    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
    [board.dsn, board2.dsn, bom_jlc_M.csv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]
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2026-10-08 tools/jlc_rotations.py: derive KiCad->JLC CPL rotation/offset per footprint (EasyEDA pin-1 + community DB + 2022 bottom rule); K4 CPLs corrected, 12 parts flagged for preview with pin-1 picture
    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
    [jlc_rotation_corrections.csv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]
2026-10-08 K4 B2B gap: C16/C17 (M) and C9 (P) to Samsung 0201 (0.39 max): gap side 0 fail, worst +0.05 (U3 BQ25180 / D4 0.5 max are package-fixed); D5 0.45, U3 0.5 from datasheets; M re-routed 0/0, P local edit
    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
    [board2.dsn, placed.kicad_pcb, routed.kicad_pcb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]
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2026-10-08 K4 re-place/route after 9ec84ae: P and M at L 15.5, plain kicad-cli DRC 0 errors / 0 unconnected both; route_net3d GRID env; pin-contract + ECR-0020 + backlog (C9/C17 datasheet check still open)
    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
    [placed.kicad_pcb, routed.kicad_pcb, routed_M.kicad_pcb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]
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2026-10-08 Loudness fix: alert tone at 2-3 kHz and look-ahead soft-knee limiter at the R64 clamp, behind knobs (lim_lookahead default off); host tests; before/after margin
    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
    [dsp.c, fw.c]
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2026-10-09 fw: loud toggle = TRIPLE press in gesture option B (HOLD2 stays A); fix loud_db description; test_loud_gesture extended; sub-ui sync
    Triple armed only when loud_db > 0 (legacy timing otherwise). No default change, no golden re-bless.
    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
    [fw.c]
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2026-10-09 D17 follow-ups: lim_c sized per carrier ARR (clamp never bites at 200/400/800 kHz), prop_ceiling clamp check restored for all carriers; PLM SPEC reviewed; perf-port-meadow drift cause + 130 mAh runti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
    [dsp.c]
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
